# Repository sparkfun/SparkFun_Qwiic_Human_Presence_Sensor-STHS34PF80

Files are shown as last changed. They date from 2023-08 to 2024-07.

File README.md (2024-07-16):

SparkFun Human Presence and Motion Sensor - STHS34PF80
========================================

| [SparkFun Human Presence and Motion Sensor - STHS34PF80 (Qwiic)  *(SEN-22494)*](https://www.sparkfun.com/products/22494) | [SparkFun Qwiic Mini Human Presence and Motion Sensor - STHS34PF80 *(SEN-23253)*](https://www.sparkfun.com/products/23253) |
| --- | --- |
| product in standard 1x1 form factor (https://www.sparkfun.com/products/22494) | product in mini form factor (https://www.sparkfun.com/products/23253) |

The STHS34PF80 sensor, from [ST Microelectronics](https://www.st.com/), is designed to measure the precise [black-body radiation](https://en.wikipedia.org/wiki/Black-body_radiation) *(as described by [Plank's law](https://en.wikipedia.org/wiki/Planck%27s_law))* of an object; as well as monitor ambient temperature conditions within its 80&deg; field of view. The sensor is composed of a matrix of floating vacuum thermal transistors MOS split into two parts, one exposed to IR radiation and the other one shielded. The differential reading between the segments, allows the sensor to remove self-heating effects. The STHS34PF80 also incorporates algorithms to detect and discriminate between stationary and moving objects. These features enable the sensor to work as a human presence and motion sensor in different applications such as alarm systems, anti-intruder systems, smart lighting, and room occupancy.

The sensor can operate in multiple lighting conditions and is unaffected by visible light or other bands thanks to the 5 to 20&micro;m optical band-pass filter. The STHS34PF80 has an output data rates between 0.25 to 30 Hz and an available single-shot, which are accessed through its I²C/SPI interface.

*These products are available in both the standard 1"x1" and mini Qwiic breakout boards. The mini is panel mount compatible for use in enclosures.*

Repository Contents
-------------------

* **[/docs](/docs/)** - Online documentation files
    * [assets](/docs/assets/) - Assets files
        * [board_files](/docs/assets/board_files/) - Files for the product design
            * [Eagle design files](/docs/assets/board_files/eagle_files.zip) (.zip)
            * [Schematic](/docs/assets/board_files/schematic.pdf) (.pdf)
            * [Dimensions](/docs/assets/board_files/dimensions.pdf) (.pdf)
        * [component_documentation](/docs/assets/component_documentation/) - Datasheets for hardware components
        * [img/hookup_guide/](/docs/assets/img/hookup_guide/) - Images for hookup guide documentation
* **[/Hardware](/Hardware/)** - Eagle design files (.brd, .sch)
  * **[/1U](/Hardware/1U/)** - 1"x1" Form Factor
    * **[/Production](/Hardware/1U/Production/)** - Production files
  * **[/Mini](/Hardware/Mini/)** - Mini Form Factor
    * **[/Production](/Hardware/Mini/Production/)** - Production files

Documentation
--------------

* **[Hookup Guide (mkdocs)](http://docs.sparkfun.com/SparkFun_Qwiic_Human_Presence_Sensor-STHS34PF80/)** - Hookup guide for the mosaic-X5 GNSS Breakout hosted by GitHub pages.
  * [Arduino Library](https://github.com/sparkfun/SparkFun_STHS34PF80_Arduino_Library/tree/main)

*Need to download or print our hookup guide?*

* [Print *(Print to PDF)* from Single-Page View](http://docs.sparkfun.com/SparkFun_Qwiic_Human_Presence_Sensor-STHS34PF80/print_view)

Product Variants
----------------

* [SEN-22494](https://www.sparkfun.com/products/22494)- v1.0, Initial Release *(1"x1" Form Factor)*
* [SEN-23253](https://www.sparkfun.com/products/23253)- v1.0, Initial Release *(Mini Form Factor)*

Version History
---------------

* [v10](https://github.com/sparkfun/SparkFun_Qwiic_Human_Presence_Sensor-STHS34PF80/releases/tag/v10) - Initial Release

License Information
-------------------

This product is ***open source***!

Please review the [`LICENSE.md`](./LICENSE.md) file for license information.

If you have any questions or concerns about licensing, please contact technical support on our [SparkFun forums](https://forum.sparkfun.com/viewforum.php?f=152).

Distributed as-is; no warranty is given.

- Your friends at SparkFun.

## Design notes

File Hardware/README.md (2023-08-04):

SparkFun <PRODUCT NAME> Design Files
=====================================

The .sch and .brd files hare are Eagle CAD schematic and PCB design files from SparkFun Electronics.
A freeware version of Autodesk Eagle can be found [here](https://www.autodesk.com/products/eagle/free-download).

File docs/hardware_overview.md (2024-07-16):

---
icon: material/cog
---

## Board Dimensions
The Qwiic Mini Human Presence and Motion Sensor breakout boards are laid out in the standardized 0.5"x 1" (1.77 x 2.54 cm) *mini* form-factor and the normal, 1" x 1" (2.54 x 2.54 cm) Qwiic breakout board. These boards also include standard 0.13" mounting holes, which are compatible with 4-40 screws. The dimensions of these boards are illustrated in the drawings below, where the listed measurements are in inches.

<div class="grid" markdown>

<div markdown>
<figure markdown>
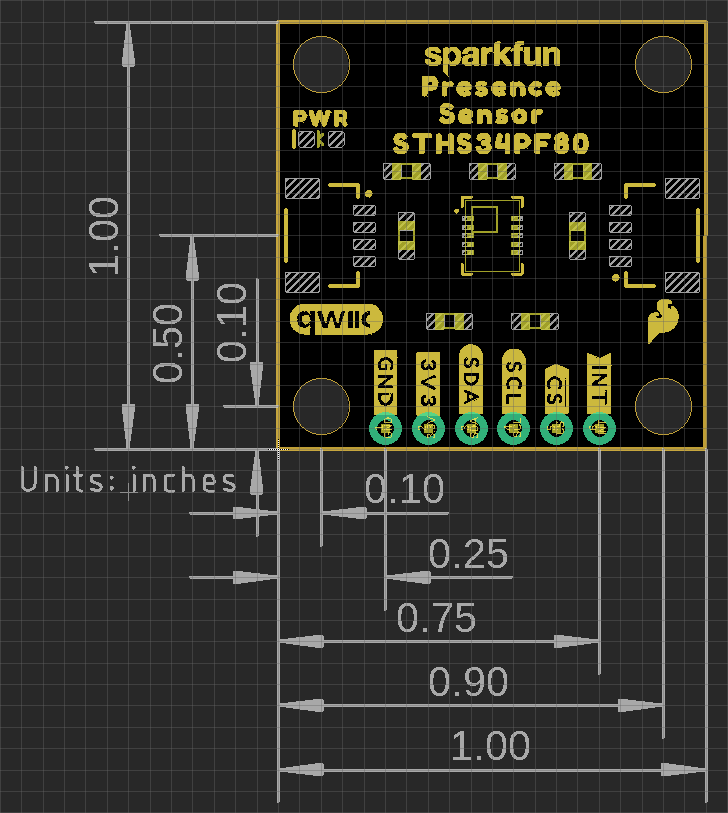
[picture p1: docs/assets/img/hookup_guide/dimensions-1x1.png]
Board Dimensions of the standard board

</figure>
</div>

<div markdown>
<figure markdown>
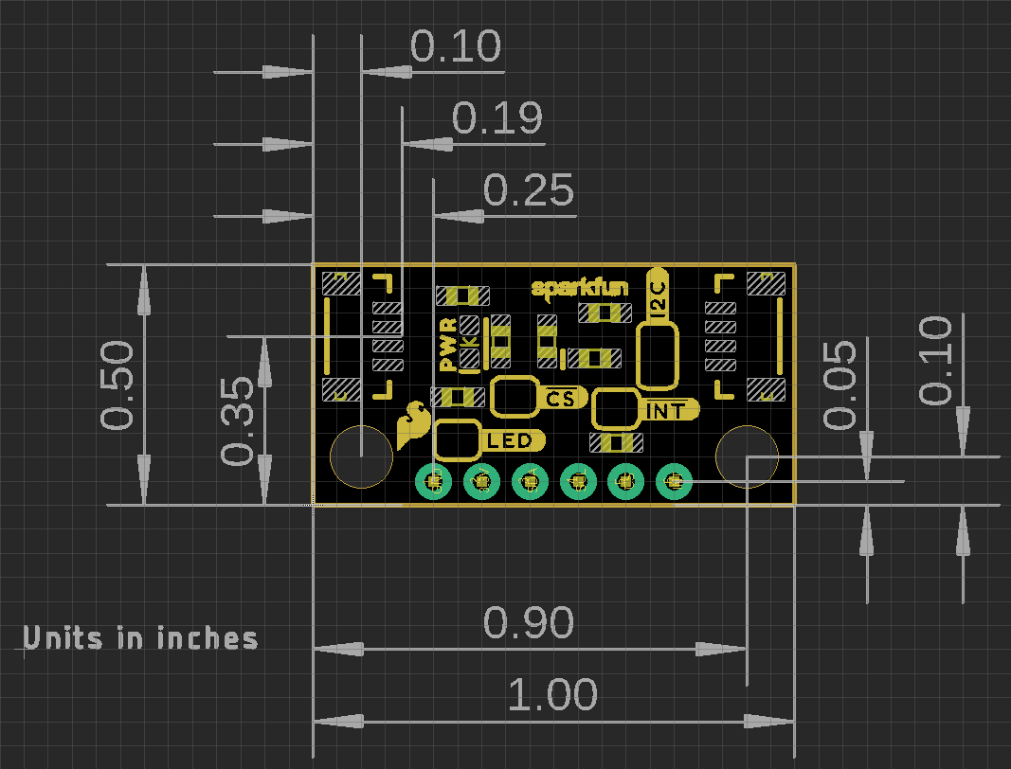
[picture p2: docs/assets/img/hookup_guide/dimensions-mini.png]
Board Dimensions of the mini board

</figure>
</div>

</div>

<center>
*[Dimensions (PDF)](./assets/board_files/dimensions.pdf) for the Qwiic Human Presence/Motion Sensor boards, in inches.*
</center>

??? tip "Need more measurements?"
	For more information about the board's dimensions, users can download the [eagle files](./assets/board_files/eagle_files.zip) for the board. These files can be opened in Eagle and additional measurements can be made with the dimensions tool.

	??? info ":octicons-download-16:{ .heart } Eagle - Free Download!"
		Eagle is a [CAD]("computer-aided design") program for electronics that is free to use for hobbyists and students. However, it does require an account registration to utilize the software.

		<center>
		[Download from<br>:autodesk-primary:{ .autodesk }](https://www.autodesk.com/products/eagle/free-download "Go to downloads page"){ .md-button .md-button--primary width="250px" }
		</center>

	??? info ":straight_ruler: Dimensions Tool"
		This video from Autodesk demonstrates how to utilize the dimensions tool in Eagle, to include additional measurements:

		<center>
		<div class="video-500px">
		<iframe src="https://www.youtube.com/embed/dZLNd1FtNB8" title="EAGLE Dimension Tool" frameborder="0" allow="accelerometer; autoplay; clipboard-write; encrypted-media; gyroscope; picture-in-picture" allowfullscreen></iframe>
		</div>
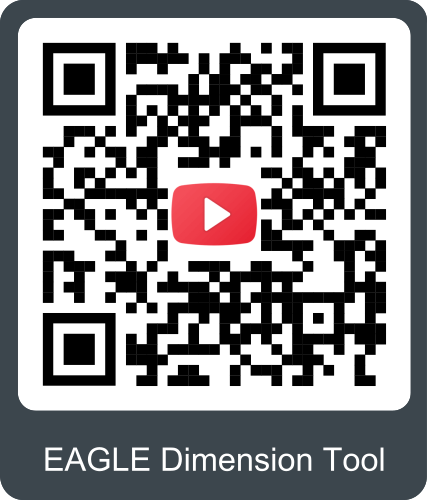
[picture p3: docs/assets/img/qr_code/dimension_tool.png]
QR code to play video
		
		</center>

## Power
The STHS34PF80 requires a supply voltage between **1.7V** to **3.6V**. This power can be provided to the board, either, through one of the *polarized* Qwiic connectors or the dedicated 3.3V and GND [PTH](https://en.wikipedia.org/wiki/Through-hole_technology "Plated Through Holes") pins broken out on the board.

<div class="grid" markdown>

<div markdown>
<figure markdown>
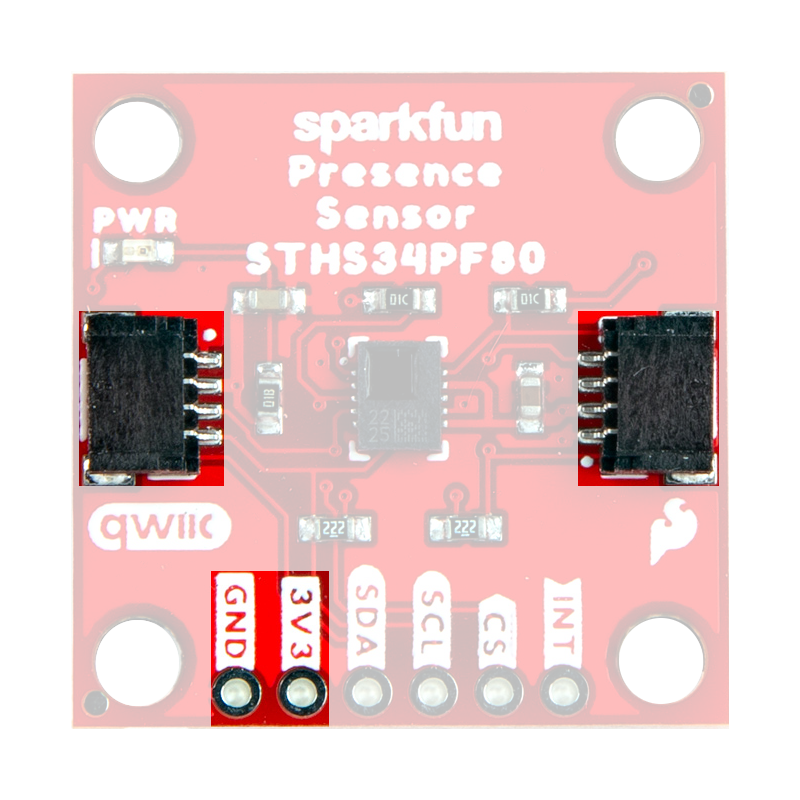
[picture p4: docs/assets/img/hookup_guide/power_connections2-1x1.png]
Power connections on the standard board

</figure>
</div>

<div markdown>
<figure markdown>
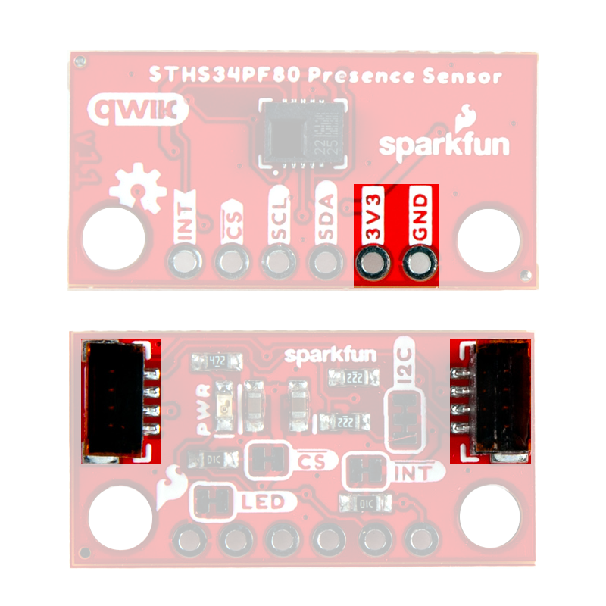
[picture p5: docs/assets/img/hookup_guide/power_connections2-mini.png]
Power connections on the mini board

</figure>
</div>

</div>

<center>
*Qwiic Human Presence/Motion Sensor boards' power connections.*
</center>

!!! warning "Info"
	The Qwiic connect system is meant to run on **3.3V**. Ensure that another voltage is not being supplied, when utilized in conjunction with this system.

!!! info
	For more details, users can reference the [schematic](./assets/board_files/schematic.pdf) and the [STHS34PF80 datasheet](./assets/component_documentation/sths34pf80.pdf).

### Power Status LED
The red, `PWR` LED will light up once **1.4V** is supplied to the board; however, for most users, it will light up when **3.3V** is supplied through the Qwiic connector. A jumper is available to disconnect the power from the LED, for low-power applications (see Jumpers section below).

<div class="grid" markdown>

<div markdown>
<figure markdown>
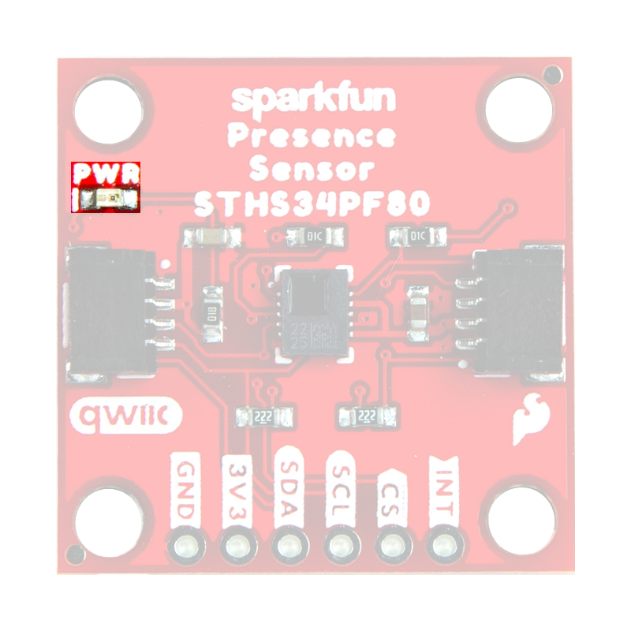
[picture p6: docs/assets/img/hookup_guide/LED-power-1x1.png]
Power LED on the standard board

</figure>
</div>

<div markdown>
<figure markdown>
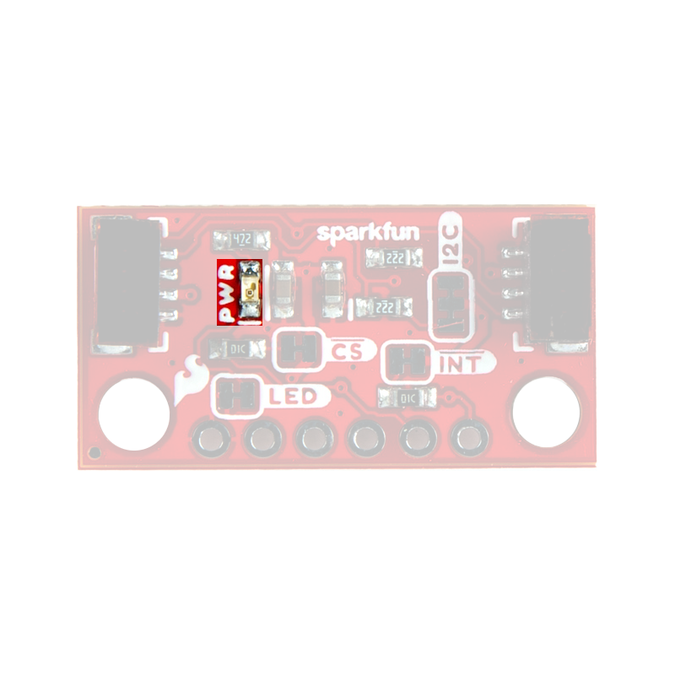
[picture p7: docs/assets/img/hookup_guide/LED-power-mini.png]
Power LED on the mini board

</figure>
</div>

</div>

<center>
*The `PWR` status LED on the Qwiic Human Presence/Motion Sensor boards.*
</center>

!!! tip "Minimum Voltage"
	Users should keep in mind that the forward voltage of the red LED is lower than the minimum voltage required to power the STHS34PF80 sensor. Therefore, the LED could potentially be lit, when there isn't enough voltage to power the sensor.

## :fontawesome-solid-microchip:&nbsp; STHS34PF80
The Qwiic Human Presence/Motion Sensor board features the [STHS34PF80 sensor](./assets/component_documentation/sths34pf80.pdf) from [ST Microelectronics](https://www.st.com). Composed of a matrix of floating vacuum thermal transistors MOS, the sensor measures the ambient temperature and detects the [black-body radiation](https://en.wikipedia.org/wiki/Black-body_radiation) of objects within its 80&deg field of view. The sensor's transistor array is split into two parts, one exposed to IR radiation and the other one shielded. The differential reading between the segments, allows the sensor to remove self-heating effects.

The sensor can operate in multiple lighting conditions and is unaffected by visible light or other bands thanks to the 5 to 20&micro;m optical band-pass filter. The STHS34PF80 also incorporates algorithms to detect and discriminate between stationary and moving objects. These features enable the sensor to work as a human presence and motion sensor in different applications such as alarm systems, anti-intruder systems, smart lighting, and room occupancy. With an output data rates between 0.25 to 30 Hz and an available single-shot measurement from the STHS34PF80, all of which can be accessed through its I<sup>2</sup>C/SPI interface.

<div class="grid" markdown>

<div markdown>

**Features:**

<div class="annotate" markdown>

* I<sup>2</sup>C Address *(7-bit)*: **0x5A** *(**`1011010`**)*
* Operating Voltage: **1.7 to 3.6V**
	* Current Draw: 10&micro;A
* Range: 4m *(objects 70 x 25 cm² in size)*
	* Field of View: 80°
* Optical wavelength: 5 to 20&micro;m
* Built-in Detection Algorithms:
	* Identify stationary objects
	* Distinguish between stationary and moving objects
* Output Data Rate: 0.25 to 30Hz
* IR sensitivity: 2000 LSB/&deg;C
* RMS noise: 25 LSB<sub>rms</sub>
* Operating Temperature: -40 to 85&deg;C (1)
* Sensor accuracy: ±0.6&deg;C *(local)* (2)
* Factory calibrated

</div>

1. The operational temperature range of the sensor is 
2. The accuracy specifications only apply under settled isothermal conditions.

!!! info "Current Consumption"
	The average current consumption by the STHS34PF80 is 10&micro;A with 1.5&micro;A in power-down mode.

</div>

<div markdown>

<!-- <figure markdown>
[![STHS34PF80 sensor on the standard board](./assets/img/hookup_guide/STHS34PF80-1x1.png){ width="400" }](./assets/img/hookup_guide/STHS34PF80-1x1.png "Click to enlarge")
<br>
<figure markdown>
[![STHS34PF80 sensor on the mini board](./assets/img/hookup_guide/STHS34PF80-mini.png){ width="400" }](./assets/img/hookup_guide/STHS34PF80-mini.png "Click to enlarge")
<figcaption markdown>The STHS34PF80 sensor on the Qwiic Human Presence/Motion Sensor boards.</figcaption>
</figure> -->

<figure markdown>
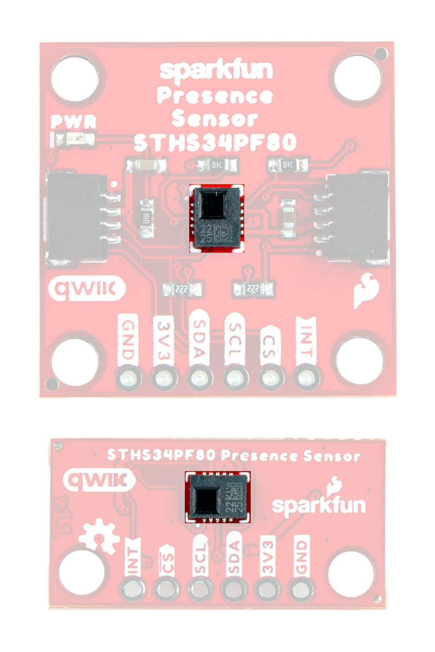
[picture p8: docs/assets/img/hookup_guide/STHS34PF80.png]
STHS34PF80 sensor on the mini board

<figcaption markdown>The STHS34PF80 sensor on the Qwiic Human Presence/Motion Sensor boards.</figcaption>
</figure>

</div>

</div>

??? note "Operation Modes"
	The STHS34PF80 has three operation modes:

	* **Power-down:** After the boot is completed, the device is automatically configured in power-down mode.
	* **One-shot:**	When configured in one-shot mode, the device can read environmental data at the very moment the controlling MCU requires it.
	* **Continuous:**	When configured in continuous mode, the device keeps reading data at predefined frequencies (fixed output data rates, ODRs).
	
	In both one-shot mode and continuous mode, the STHS34PF80 allows performing prior averaging (filtering) of the values of ambient temperature and object temperature to obtain smoother outputs.

	!!! info
		For more details, users can refer to [Section 3 of the AN5867 - Operation Manual](./assets/component_documentation/an5867-operation-manual.pdf).

??? note "Smart Detection Algorithms"
	The STHS34PF80 has three detection modes that are provided by the built-in smart algorithms:

	* Presence detection
	* Motion detection
	* Ambient temperature shock detection

	*\*These are not available when wide mode is configured.*

	!!! info
		For more details, users can refer to [Section 7 of the AN5867 - Operation Manual](./assets/component_documentation/an5867-operation-manual.pdf).

## Breakout Pins
There are six [PTH](https://en.wikipedia.org/wiki/Through-hole_technology "Plated Through Holes") pins broken out on the Qwiic Human Presence/Motion Sensor boards. The pins are evenly spaced at 0.1" on the outer edge of the board; perfect for attaching [headers](https://www.sparkfun.com/categories/381). These pins provide access to the I<sup>2</sup>C and SPI interfaces of the STHS34PF80 sensor, including the interrupt pin.

!!! note
	The I<sup>2</sup>C interface can also be accessed through the Qwiic connectors on the board.

### I<sup>2</sup>C Pins
The I<sup>2</sup>C interface can also be accessed either through the breakout pins or the Qwiic connectors on the board. In most cases, the Qwiic connector will be the simplest method to connect the Qwiic Human Presence/Motion Sensor boards to a microcontroller. The I<sup>2</sup>C interface is **enabled by default** on the Qwiic Human Presence/Motion Sensor boards.

<div class="grid" markdown>

<div markdown>
<figure markdown>
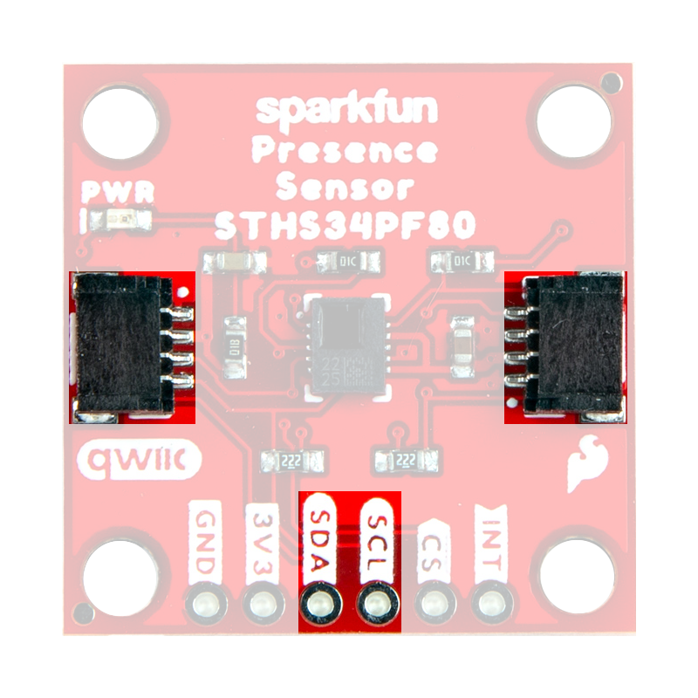
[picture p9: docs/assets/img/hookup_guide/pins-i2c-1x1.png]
I2C pins on the standard board

</figure>
</div>

<div markdown>
<figure markdown>
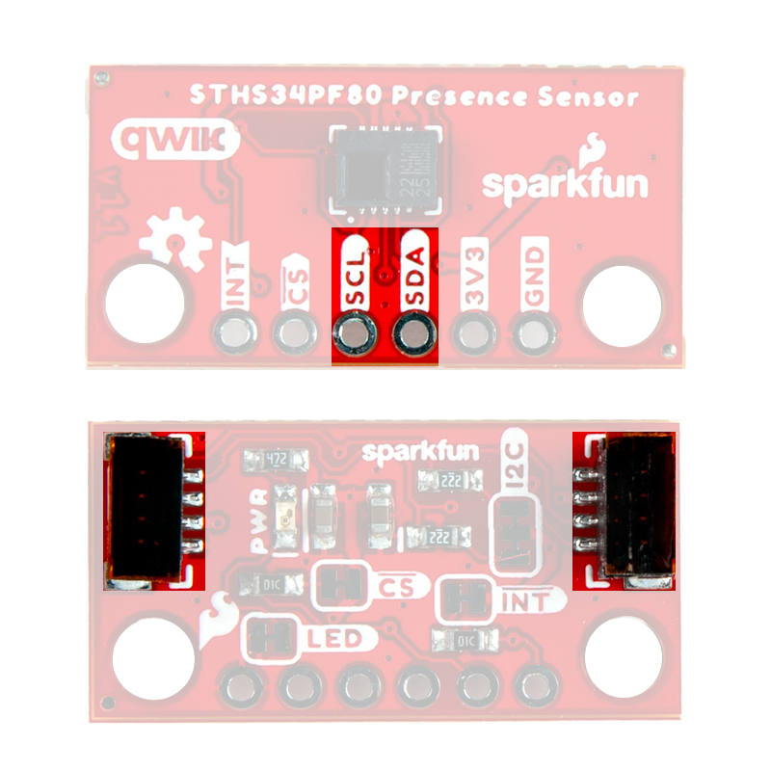
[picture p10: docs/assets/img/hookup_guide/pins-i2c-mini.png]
I2C pins on the mini board

</figure>
</div>

</div>

<center>
*I<sup>2</sup>C pins on the Qwiic Human Presence/Motion Sensor boards.*
</center>

!!! info "Enabling the I<sup>2</sup>C Interface"
	The I<sup>2</sup>C interface is enabled by default on the Qwiic Human Presence/Motion Sensor boards. To disable the I<sup>2</sup>C interface and enable the SPI interface, users must ensure that the `CS` pin is initially pulled down (`0`).

??? tip " Qwiic Connector"
	Qwiic connectors are provided for users to seamlessly integrate I<sup>2</sup>C devices with [SparkFun's Qwiic Ecosystem](https://www.sparkfun.com/qwiic).

	<div class="grid" markdown>

	<div markdown>
	<figure markdown>
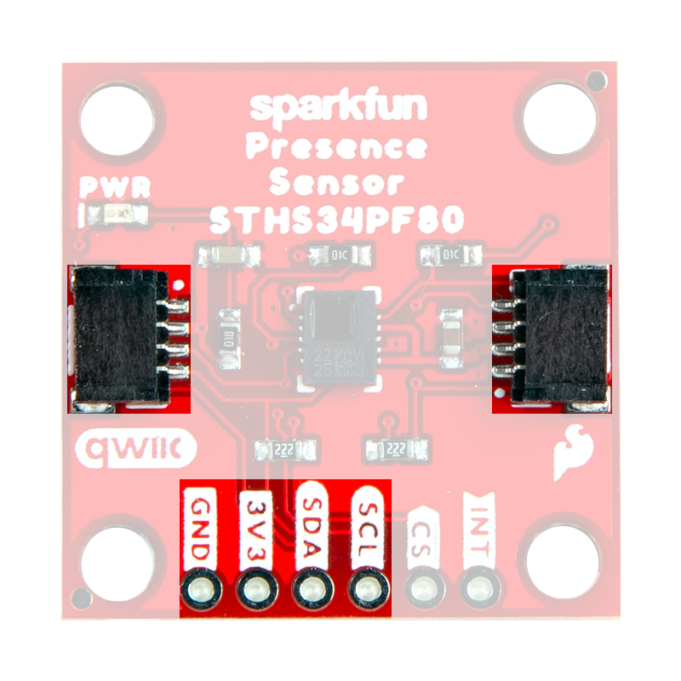
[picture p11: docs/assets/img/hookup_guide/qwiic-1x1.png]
Qwiic connector and I2C pins on the standard board
	
	</figure>
	</div>

	<div markdown>
	<figure markdown>
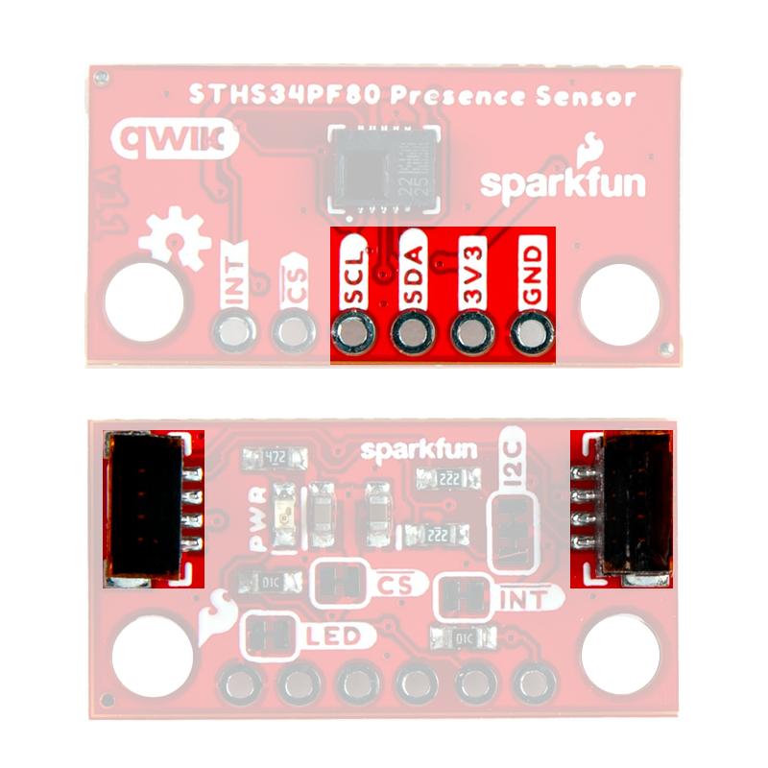
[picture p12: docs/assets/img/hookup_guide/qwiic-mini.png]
Qwiic connector and I2C pins on the mini board
	
	</figure>
	</div>

	</div>

	<center>
	*Qwiic connector and I<sup>2</sup>C pins on the Qwiic Human Presence/Motion Sensor boards.*
	</center>

### SPI Pins
The STHS34PF80 sensor operates in a 3-wire SPI configuration. In a 3-wire mode, the data signal lines are combined into a single bidirectional data line. The data transactions are half-duplex to allow for bidirectional communication.

<div align="center" markdown>

<table markdown>
<tr>
<th align="center">Label</th>
<th align="center">Pin</th>
<th>Function</th>
</tr>
<tr markdown>
<td align="center" markdown>`SCL`</td>
<td align="center" markdown>`SPC`</td>
<td>Clock signal</td>
</tr>
<tr markdown>
<td align="center" markdown>`SDA`</td>
<td align="center" markdown>`SDIO`</td>
<td>Serial data (In/Out)</td>
</tr>
<tr markdown>
<td align="center" style="vertical-align:middle" markdown>`CS`</td>
<td align="center" style="vertical-align:middle" markdown>`CS`</td>
<td markdown>
Chip select:<br>
`1`: I²C enabled<br>
`0`: SPI enabled
</td>
</tr>
</table>

</div>

<div class="grid" markdown>

<div markdown>
<figure markdown>
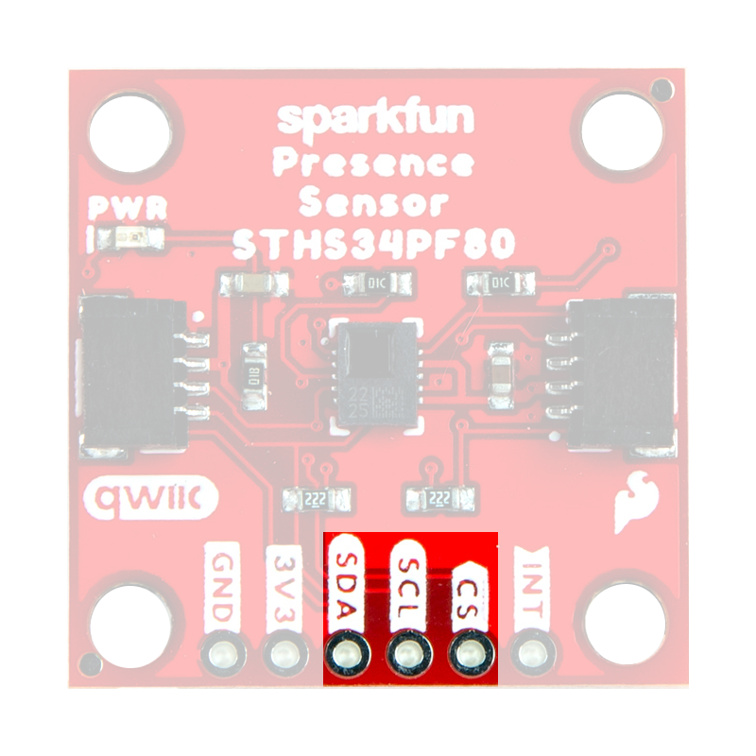
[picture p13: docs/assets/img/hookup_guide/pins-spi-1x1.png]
SPI pins on the standard board

</figure>
</div>

<div markdown>
<figure markdown>
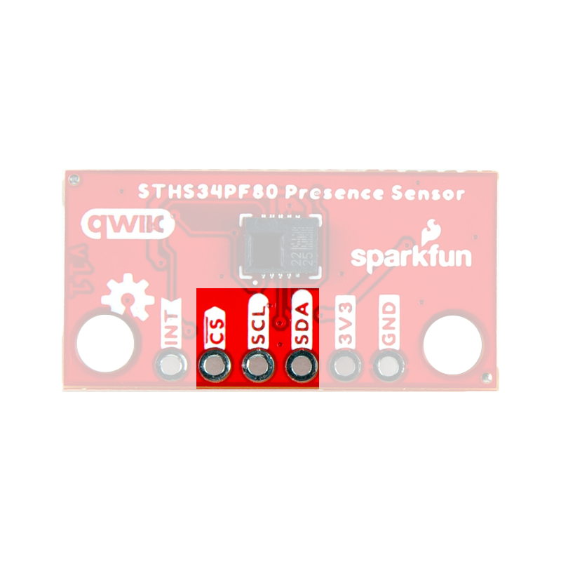
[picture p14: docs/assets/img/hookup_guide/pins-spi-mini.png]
SPI pins on the mini board

</figure>
</div>

</div>

<center>
*SPI pins on the Qwiic Human Presence/Motion Sensor boards. Please refer to the table above for the associated pin connections, based on the boards' labels.*
</center>

!!! info "Enabling the SPI Interface"
	The I<sup>2</sup>C interface is enabled by default on the Qwiic Human Presence/Motion Sensor boards. To disable the I<sup>2</sup>C interface and enable the SPI interface, users must ensure that the `CS` pin is initially pulled down. *(On boot-up, the `CS` must be in a `LOW` state to enable the SPI interface.)*

### Interrupt Pin
By default, the interrupt pin signals when data is available. However, the detection mode employed by the sensor can also trigger an interrupt.

<div class="grid" markdown>

<div markdown>
<figure markdown>
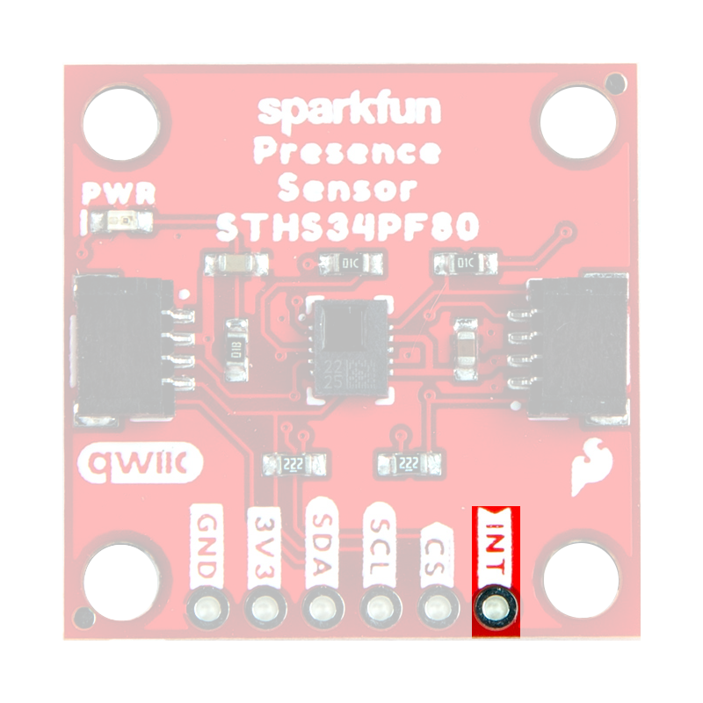
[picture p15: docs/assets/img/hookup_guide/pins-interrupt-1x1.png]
Interrupt pin on the standard board

</figure>
</div>

<div markdown>
<figure markdown>
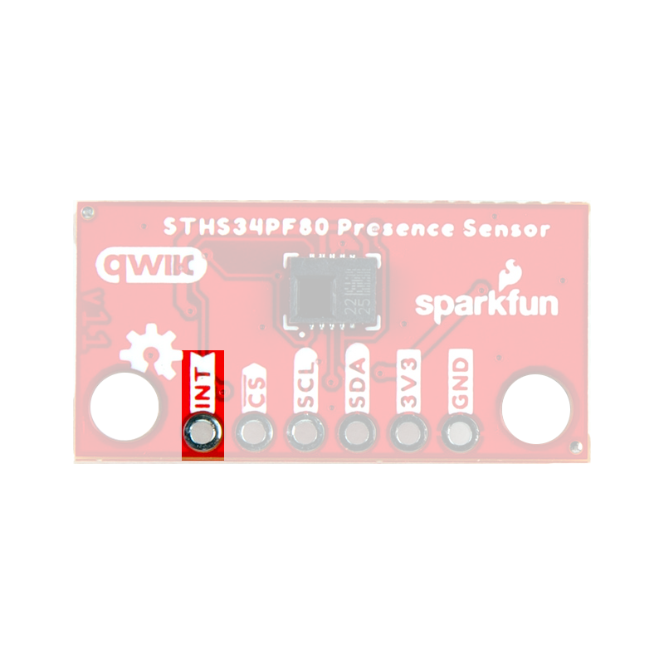
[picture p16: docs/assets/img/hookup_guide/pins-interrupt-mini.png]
Interrupt pin on the mini board

</figure>
</div>

</div>

<center>
*Interrupt pin on the Qwiic Human Presence/Motion Sensor boards.*
</center>

## Qwiic Connectors
Qwiic connectors are provided for users to seamlessly integrate with [SparkFun's Qwiic Ecosystem](https://www.sparkfun.com/qwiic). Otherwise, users can access the I<sup>2</sup>C interface through the [PTH pins broken out on the board](#i2c-pins).

<div class="grid" markdown>

<div markdown>
<figure markdown>
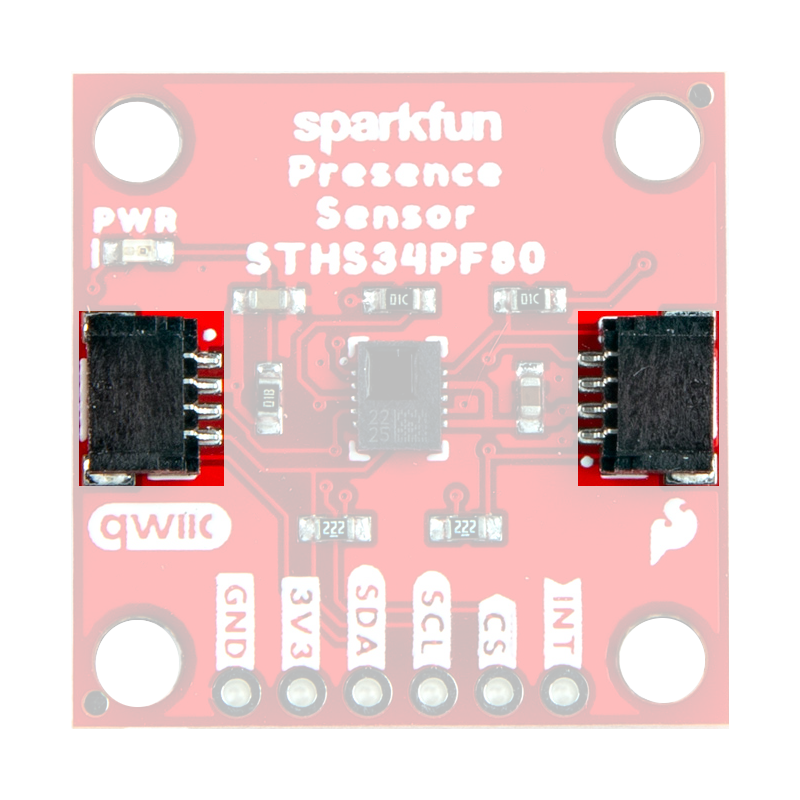
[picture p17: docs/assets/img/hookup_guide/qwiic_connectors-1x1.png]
Qwiic connector on the standard board

</figure>
</div>

<div markdown>
<figure markdown>
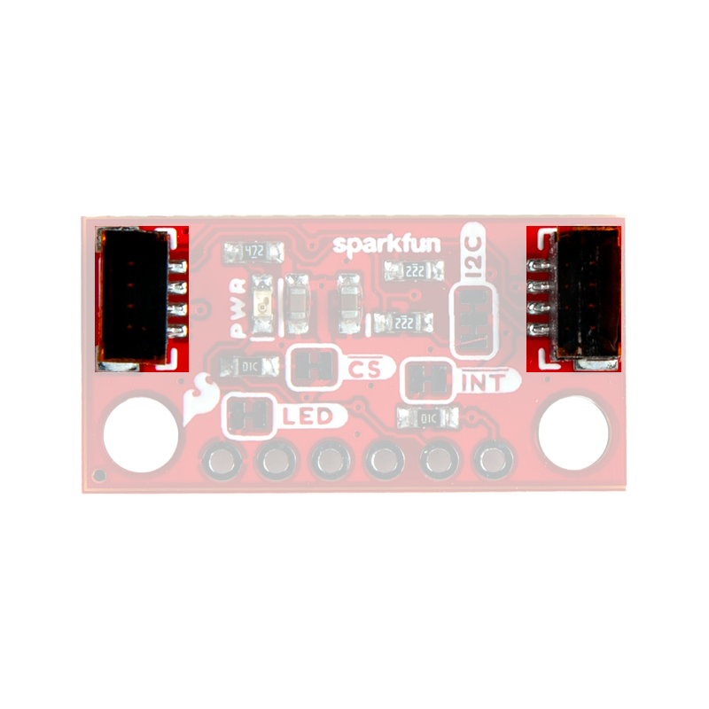
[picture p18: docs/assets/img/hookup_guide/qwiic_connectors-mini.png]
Qwiic connector on the mini board

</figure>
</div>

</div>

<center>
*Qwiic connectors on the Qwiic Human Presence/Motion Sensor boards.*
</center>

??? tip "What is Qwiic?"

	<div class="grid" markdown>

	<div markdown>

	<!-- Qwiic Banner -->
	<center>
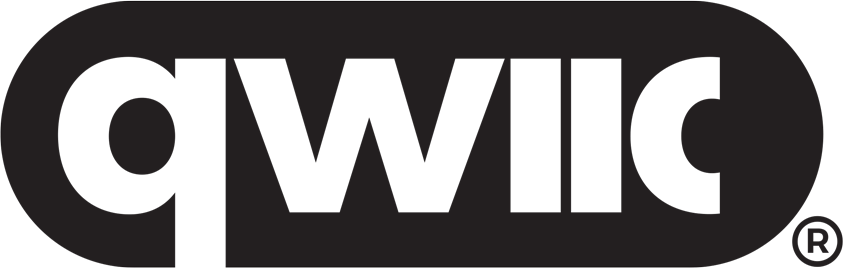
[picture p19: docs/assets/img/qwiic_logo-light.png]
Qwiic Logo - light theme (https://www.sparkfun.com/qwiic)
	
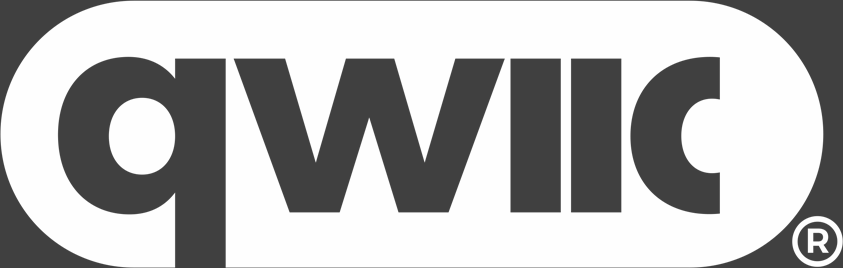
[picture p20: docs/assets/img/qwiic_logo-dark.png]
Qwiic Logo - dark theme (https://www.sparkfun.com/qwiic)
	
	</center>

	---

	The [Qwiic connect system](https://www.sparkfun.com/qwiic) is a solderless, polarized connection system that allows users to seamlessly daisy chain I^2^C boards together. Play the video, to learn more about the Qwiic connect system or click on the banner above to learn more about [Qwiic products](https://www.sparkfun.com/qwiic).

	</div>

	<div style="max-height=400px;" markdown>

	<center>
	<div class="video-container">
	<iframe src="https://www.youtube.com/embed/x0RDEHqFIF8" title="SparkFun's Qwiic Connect System" frameborder="0" allow="accelerometer; encrypted-media; gyroscope; picture-in-picture" allowfullscreen></iframe>

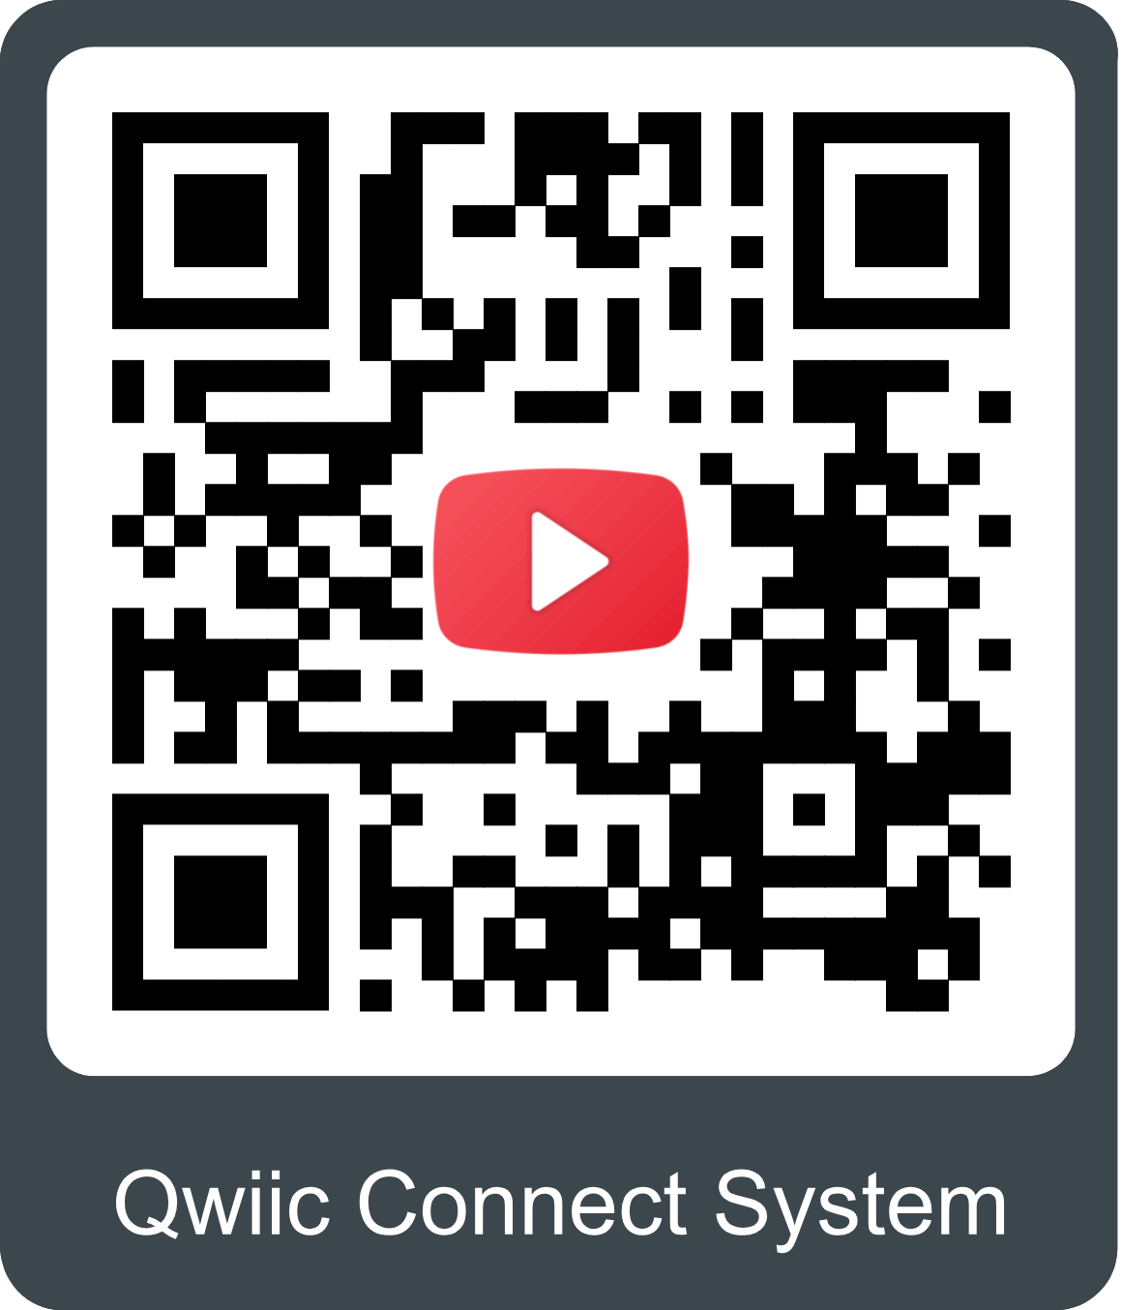
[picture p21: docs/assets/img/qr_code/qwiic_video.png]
QR code to instructional video
	
	</div>
	</center>

	</div>

	</div>

	!!! info "Features of the Qwiic System"

		=== "No Soldering"

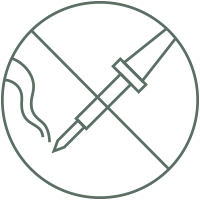
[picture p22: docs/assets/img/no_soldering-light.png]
no soldering - light theme
			
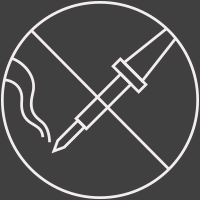
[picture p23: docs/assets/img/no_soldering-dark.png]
no soldering - dark theme
			

			Qwiic cables (4-pin JST) plug easily from development boards to sensors, shields, accessory boards and more, making easy work of setting up a new prototype.

		=== "Polarized Connector"

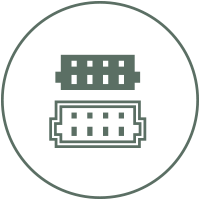
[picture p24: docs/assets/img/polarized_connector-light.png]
polarized connector - light theme
			
			polarized connector - dark theme

			There's no need to worry about accidentally swapping the `SDA` and `SCL` wires on your breadboard. The Qwiic connector is polarized so you know you’ll have it wired correctly every time.

			The part numbers for the PCB connector is `SM04B-SRSS` ([Datasheet](https://cdn.sparkfun.com/assets/parts/1/2/2/8/9/Qwiic_Connector_Datasheet.pdf)) and the mating connector on the cables is `SHR04V-S-B`; or an equivalent *1mm pitch, 4-pin JST connection*.

		=== "Daisy Chain-able"

			daisy chainable - light theme
			daisy chainable - dark theme

			It’s time to leverage the power of the I^2^C bus! Most Qwiic boards will have two or more connectors on them, allowing multiple devices to be connected.

## Jumpers

??? note "Never modified a jumper before?"
	Check out our <a href="https://learn.sparkfun.com/tutorials/664">Jumper Pads and PCB Traces tutorial</a> for a quick introduction!

	<div class="grid cards col-4" markdown align="center">

	-   <a href="https://learn.sparkfun.com/tutorials/664">
		<figure markdown>
		Tutorial thumbnail
		</figure>

		---

		**How to Work with Jumper Pads and PCB Traces**</a>

	</div>

There are four jumpers on the back of the board that can be used to easily modify the hardware connections of the board.

<div class="annotate" markdown>

* **LED** - This jumper can be used to disconnect power from the red, power LED for low-power applications.
* **I2C** - This jumper can be used to remove the pull-up resistors on the I<sup>2</sup>C bus.
* **INT** - This jumper can be used to remove the pull-up resistor from the `INT` pin.
* **CS** - This jumper can be used to remove the pull-up resistor from the `CS` pin.
	* The state of the `CS` pin on boot-up, controls whether the I<sup>2</sup>C or SPI interface is enabled. (1)

</div>

1. !!! info
	* `1`: I²C enabled
	* `0`: SPI enabled

<div class="grid" markdown>

<div markdown>
<figure markdown>
Jumpers on the standard board
<figcaption markdown>Jumpers on the back of the Qwiic Human Presence/Motion Sensor board.</figcaption>
</figure>
</div>

<div markdown>
<figure markdown>
Jumpers on the mini board
<figcaption markdown>Jumpers on the Qwiic Mini Human Presence/Motion Sensor board.</figcaption>
</figure>
</div>

</div>

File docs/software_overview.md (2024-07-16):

---
icon: simple/arduino
---

## Arduino IDE
!!! tip
	For first-time users, who have never programmed before and are looking to use the Arduino IDE, we recommend beginning with the <a href="https://www.sparkfun.com/products/15631">SparkFun Inventor's Kit (SIK)</a>, which is designed to help users get started programming with the Arduino IDE.

Most users may already be familiar with the Arduino IDE and its use. However, for those of you who have never heard the name *Arduino* before, feel free to check out the [Arduino website](https://www.arduino.cc/en/Guide/HomePage). To get started with using the Arduino IDE, check out our tutorials below:

<div class="grid cards" markdown align="center">

-   <a href="https://learn.sparkfun.com/tutorials/50"><figure markdown>
	What is an Arduino?
	</figure>

	---

	**What is an Arduino?**</a>

-   <a href="https://learn.sparkfun.com/tutorials/61"><figure markdown>
	Installing the Arduino IDE
	</figure>

	---
	
	**Installing the Arduino IDE**</a>

-   <a href="https://learn.sparkfun.com/tutorials/15"><figure markdown>
	Installing an Arduino Library
	</figure>

	---
	
	**Installing an Arduino Library**</a>

-   <a href="https://learn.sparkfun.com/tutorials/1265"><figure markdown>
	Installing Board Definitions in the Arduino IDE
	</figure>

	---
	
	**Installing Board Definitions in the Arduino IDE**</a>
</div>

??? tip "Need help setting up the RedBoard Plus?"
	### RedBoard Plus
	The following instructions should help users get started with the RedBoard Plus. For more information about the board, please check out our hookup guide below:

	<figure markdown>
	RedBoard Plus Hookup Guide (https://learn.sparkfun.com/tutorials/1758)
	<figcaption markdown>[**RedBoard Plus Hookup Guide**](https://learn.sparkfun.com/tutorials/1758)</figcaption>
	</figure>

	#### CH340 Driver
	Users will need to install the appropriate driver for their computer to recognize the serial-to-UART chip on their board/adapter. Most of the latest operating systems will recognize the CH340C chip on the board and automatically install the required driver.

	*To manually install the CH340 driver on their computer, users can download it from the [WCH website](http://www.wch-ic.com/products/CH340.html?). For more information, check out our [How to Install CH340 Drivers Tutorial](https://www.sparkfun.com/ch340).*

	<figure markdown>
	How to Install CH340 Drivers (https://learn.sparkfun.com/tutorials/908)
	<figcaption markdown>[**How to Install CH340 Drivers**](https://learn.sparkfun.com/tutorials/908)</figcaption>
	</figure>

	#### Selecting a Board
	When selecting a board to program in the Arduino IDE, users should select the **Arduino Uno** from the **Tools** drop-down menu _(_i.e. **Tools** > **Board** > **Arduino AVR Boards** > **Arduino Uno**)_.

	<figure markdown>
	Click to enlarge
	<figcaption markdown>Select the **Arduino Uno** from the Tools drop-down menu in the Arduino IDE.</figcaption>
	</figure>

	??? info "Arduino IDE 2.x.x - *Alternative Method*"
		In the newest version of the Arduino IDE 2.`x`.`x`, users can also select their board (*green*) and port (*blue*) from the `Select Board & Port` dropdown menu (*yellow*).

		<figure markdown>
		Click to enlarge
		<figcaption markdown>Selecting the **Arduino Uno** and **COM5** port from the **Select Board & Port** drop-down menu in the Arduino IDE (v2.0.3).</figcaption>
	</figure>

## SparkFun STHS34PF80 Arduino Library
The [SparkFun STHS34PF80 Arduino library](https://github.com/sparkfun/SparkFun_STHS34PF80_Arduino_Library) can be installed from the library manager in the Arduino IDE by searching for:

	SparkFun STHS34PF80 Arduino library

<figure markdown>
Click to enlarge
<figcaption markdown>SparkFun STHS34PF80 Arduino library in the library manager of the Arduino IDE.</figcaption>
</figure>

??? tip "Manually Downloading the Arduino Library"
	For users who would like to manually download and install the library, the `*.zip` file can be accessed from the [GitHub repository](https://github.com/sparkfun/SparkFun_STHS34PF80_Arduino_Library) or downloaded by clicking the button below.

	<center>
	[:octicons-download-16:{ .heart } Download the Arduino Library](https://github.com/sparkfun/SparkFun_STHS34PF80_Arduino_Library/archive/refs/heads/main.zip){ .md-button .md-button--primary }
	</center>

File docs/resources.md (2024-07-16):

## Product Resources

<section class="grid cards" markdown>

- **Composite (Both Boards)**

	---

	* :material-folder-cog: Design Files:
		* :fontawesome-solid-file-pdf: [Board Dimensions](./assets/board_files/dimensions.pdf)
		* :fontawesome-solid-file-pdf: [Schematic](./assets/board_files/schematic.pdf)
		* :material-folder-zip: [Eagle Files](./assets/board_files/eagle_files.zip)
	* :simple-arduino: [Arduino Library](https://github.com/sparkfun/SparkFun_STHS34PF80_Arduino_Library/tree/main)
	* Component Documentation
		* :fontawesome-solid-file-pdf: [STHS34PF805 Datasheet](./assets/component_documentation/sths34pf80.pdf)
		* :fontawesome-solid-file-pdf: [AN5983 - Hardware Guidelines](./assets/component_documentation/an5983-hardware-implementation-guidelines.pdf)
		* :fontawesome-solid-file-pdf: [AN5867 - Operation Manual](./assets/component_documentation/an5867-operation-manual.pdf)
	* :material-github: [Hardware Repo](https://github.com/sparkfun/SparkFun_Qwiic_Human_Presence_Sensor-STHS34PF80)

- **Human Presence and Motion Sensor - STHS34PF80 (Qwiic)**

	---

	* :sfe-logo: [Product Page](https://www.sparkfun.com/products/22494)
	* :material-folder-cog: Design Files:
		* :fontawesome-solid-file-pdf: [Board Dimensions](./assets/board_files/dimensions-1x1.pdf)
		* :fontawesome-solid-file-pdf: [Schematic](./assets/board_files/schematic-1x1.pdf)
		* :material-folder-zip: [Eagle Files](./assets/board_files/eagle_files-1x1.zip)

- **Qwiic Mini Human Presence and Motion Sensor - STHS34PF80**

	---

	* :sfe-logo: [Product Page](https://www.sparkfun.com/products/23253)
	* :material-folder-cog: Design Files:
		* :fontawesome-solid-file-pdf: [Board Dimensions](./assets/board_files/dimensions-mini.pdf)
		* :fontawesome-solid-file-pdf: [Schematic](./assets/board_files/schematic-mini.pdf)
		* :material-folder-zip: [Eagle Files](./assets/board_files/eagle_files-mini.zip)

</section>

### Additional Resources

* :material-account-supervisor: [SparkFun Technical Assistance](https://www.sparkfun.com/technical_assistance)

## 🏭&nbsp;Manufacturer's Resources
ST Microelectronics also provides additional resources for the STHS34PF805:

* [STHS34PF805 Product Page](https://www.st.com/en/mems-and-sensors/sths34pf80.html)

<center>
QR code to the hookup guide
</center>

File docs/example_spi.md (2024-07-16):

!!! bug
	This example doesn't currently operate properly; we are actively looking into the issue. To track our progress, please refer to this [GitHub issue](https://github.com/sparkfun/SparkFun_STHS34PF80_Arduino_Library/issues/7).

## Description
The [`Example4_SPIFunctionality.ino`](https://github.com/sparkfun/SparkFun_STHS34PF80_Arduino_Library/blob/main/examples/Example4_SPIFunctionality) example file can be accessed from the **File** > **Examples** > **SparkFun STHS34PF80 Arduino Library** > **Example4_SPIFunctionality** drop-down menu. This example operates similarly to the code in [`Example1_BasicReadings.ino`](https://github.com/sparkfun/SparkFun_STHS34PF80_Arduino_Library/blob/main/examples/Example1_BasicReadings). Instead of retrieving data through the I<sup>2</sup>C interface, the serial peripheral interface (SPI) is used to access the human presence detection values from the STHS34PF80 sensor.

??? code "`Example4_SPIFunctionality.ino`"
	??? info "Code Verification"
		This code was last verified to be functional under the following parameters:

			--8<-- "https://raw.githubusercontent.com/sparkfun/SparkFun_STHS34PF80_Arduino_Library/main/examples/Example4_SPIFunctionality/Example4_SPIFunctionality.ino:16:19"

	```  c++ linenums="1"
	--8<-- "https://raw.githubusercontent.com/sparkfun/SparkFun_STHS34PF80_Arduino_Library/main/examples/Example4_SPIFunctionality/Example4_SPIFunctionality.ino"
	```

## Hardware Connections
For this example, users will need to modify the `CS` jumper to enable the [SPI](https://en.wikipedia.org/wiki/Serial_Peripheral_Interface "Serial Peripheral Interface") communication. In the setups illustrated below, [right-angle headers](https://www.sparkfun.com/products/553) were soldered to the boards and connected with [M/F jumper wires](https://www.sparkfun.com/products/9140) to the microcontroller. However, users should select a connection method that suits their needs.

<div class="grid" markdown>

<div markdown>
<figure markdown>
The sensor connected to a RedBoard Plus
</figure>
</div>

<div markdown>
<figure markdown>
The sensor connected to a RedBoard Plus
</figure>
</div>

</div>

<center>
*The Qwiic Human Presence/Motion Sensor boards with [headers](https://www.sparkfun.com/products/553) soldered to them and connected to a RedBoard Plus with [jumper wires](https://www.sparkfun.com/products/9140).*
</center>

### Pin Connections
Below are the pin connections for SPI communication with the sensor. Users should be aware of the logic-levels of their microcontroller; with the [RedBoard Plus](https://www.sparkfun.com/products/18158), users only need to flip a switch to configure all the board's pins to **3.3V-logic**.

<div class="grid" markdown>

<div align="center" markdown>

| Sensor Pin | Microcontroller Pin | RedBoard Plus |
| :---: | :--- | :---: |
| `CS`  | SPI - Chip Select Pin | `10` |
| `SCL` | SPI - Serial Peripheral Clock | `13` |
| `SDA` | SPI - Serial Data In/Out | `12` |
| `3V3` | Power: **1.7 to 3.6V** | `3.3V`  |
| `GND` | Ground | `GND` |

</div>

<div markdown>
<figure markdown>
Switch on the RedBoard Plus (https://cdn.sparkfun.com/assets/learn_tutorials/1/7/5/8/18158-SparkFun_RedBoard_Plus_IO_Logic_Switch.jpg "Click to enlarge")
<figcaption markdown>
The logic-level switch on the RedBoard Plus.
</figcaption>
</figure>
</div>

</div>

!!! note
	Users will need to initially pull the `CS` pin low, to enable the [SPI](https://en.wikipedia.org/wiki/Serial_Peripheral_Interface "Serial Peripheral Interface") communication on the Qwiic Human Presence/Motion Sensor boards.

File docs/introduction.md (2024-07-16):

---
icon: material/book-open-page-variant
---

# Introduction

The STHS34PF80 sensor, from [ST Microelectronics](https://www.st.com/), is designed to measure the precise [black-body radiation](https://en.wikipedia.org/wiki/Black-body_radiation) *(as described by [Plank's law](https://en.wikipedia.org/wiki/Planck%27s_law))* of an object; as well as monitor ambient temperature conditions within its 80&deg; field of view. The sensor is composed of a matrix of floating vacuum thermal transistors MOS split into two parts, one exposed to IR radiation and the other one shielded. The differential reading between the segments, allows the sensor to remove self-heating effects. The STHS34PF80 also incorporates algorithms to detect and discriminate between stationary and moving objects. These features enable the sensor to work as a human presence and motion sensor in different applications such as alarm systems, anti-intruder systems, smart lighting, and room occupancy.

<section class="grid cards" style="grid-template-columns: repeat(auto-fit,minmax(8rem,1fr));" markdown>

-   <a href="https://www.sparkfun.com/products/22494">
	**SparkFun Human Presence and Motion Sensor - STHS34PF80 (Qwiic)**<br>
	**SKU:** SEN-22494

	---

	<figure markdown>
	Product Thumbnail
	</figure></a>

	<center>
	[QR code to product page&nbsp;&nbsp;Purchase from SparkFun :fontawesome-solid-cart-plus:{ .heart }](https://www.sparkfun.com/products/22494){ .md-button .md-button--primary }
	</center>

-   <a href="https://www.sparkfun.com/products/23253">
	**SparkFun Qwiic Mini Human Presence and Motion Sensor - STHS34PF80**<br>
	**SKU:** SEN-23253

	---

	<figure markdown>
	Product image
	</figure></a>

	<center>
	[QR code to product page&nbsp;&nbsp;&nbsp;Purchase from SparkFun :fontawesome-solid-cart-plus:{ .heart }](https://www.sparkfun.com/products/23253){ .md-button .md-button--primary }
	</center>

</section>

The sensor can operate in multiple lighting conditions and is unaffected by visible light or other bands thanks to the 5 to 20&micro;m optical band-pass filter. The STHS34PF80 has an output data rates between 0.25 to 30 Hz and an available single-shot, which are accessed through its I²C/SPI interface. The SparkFun Qwiic Human Presence and Motion Sensor boards are available in both the standard 1"x1" Qwiic form factor and the *mini* breakout board. *(The mini form-factor is also panel mount compatible for use in enclosures. (1))*
{ .annotate }

1. Please refer to the [hardware implementation guidelines](./assets/component_documentation/an5983-hardware-implementation-guidelines-for-the-sths34pf80-infrared-sensor-stmicroelectronics.pdf) for the STHS34PF80 sensor.

## :fontawesome-solid-list-check:&nbsp;Required Materials
To get started, users will need a few items. Now some users may already have a few of these items, feel free to modify your cart accordingly.

<div class="annotate" markdown>

* Computer with an operating system (OS) that is compatible with all the software installation requirements
* A compatible microcontroller/Arduino board; we recommend the [SparkFun RedBoard Plus](https://www.sparkfun.com/products/18158).
* [USB 3.1 Cable A to C - 3 Foot](https://www.sparkfun.com/products/14743) - Used to interface with the RedBoard Plus (1)
* [SparkFun Qwiic Cable Kit](https://www.sparkfun.com/products/15081) (2)
* [SparkFun Human Presence and Motion Sensor - STHS34PF80](https://www.sparkfun.com/products/22494) (3)

</div>

1. If your computer doesn't have a USB-A slot, then choose an appropriate cable or adapter.
2. Check out our [other Qwiic cable options](https://www.sparkfun.com/search/results?term=qwiic+cable).
3. The [mini version](https://www.sparkfun.com/products/23253) of this product is panel mount compatible.

<div class="grid cards col-4" markdown>

-   <a href="https://www.sparkfun.com/products/14743">
	<figure markdown>
	USB 3.1 Cable A to C - 3 Foot
	</figure>

	---

	**USB 3.1 Cable A to C - 3 Foot**<br>
	CAB-14743</a>

-   <a href="https://www.sparkfun.com/products/18158">
	<figure markdown>
	Product Thumbnail
	</figure>

	---

	**SparkFun RedBoard Plus**<br>
	DEV-18158</a>

-   <a href="https://www.sparkfun.com/products/15081">
	<figure markdown>
	Product Thumbnail
	</figure>

	---

	**SparkFun Qwiic Cable Kit**<br>
	KIT-15081</a>

-   <a href="https://www.sparkfun.com/products/22494">
	<figure markdown>
	Product Thumbnail
	</figure>

	---

	**SparkFun Human Presence and Motion Sensor - STHS34PF80 (Qwiic)**<br>
	SEN-22494</a>

-   <a href="https://www.sparkfun.com/products/22494">
	<figure markdown>
	Product Thumbnail
	</figure>

	---

	**SparkFun Qwiic Mini Human Presence and Motion Sensor - STHS34PF80**<br>
	SEN-23253</a>

</div>

??? note "Headers and Wiring"
	To add headers or hookup wires, users will need [soldering equipment](https://www.sparkfun.com/categories/49) and [headers](https://www.sparkfun.com/categories/381)/[wire](https://www.sparkfun.com/search/results?term=hook-up+wire).

	!!! tip "New to soldering?"
		Check out our [How to Solder: Through-Hole Soldering](https://learn.sparkfun.com/tutorials/5) tutorial for a quick introduction!

		<div class="grid cards col-4" markdown align="center">

		-   <a href="https://learn.sparkfun.com/tutorials/5">
			<figure markdown>
			Tutorial Thumbnail
			</figure>

			---

			**How to Solder: Through-Hole Soldering**</a>

		</div>

	<div class="grid cards col-4" markdown>

	-   <a href="https://www.sparkfun.com/products/9325">
		<figure markdown>
		Product Thumbnail
		</figure>

		---

		**Solder Lead Free - 100-gram Spool**<br>
		TOL-09325</a>

	-   <a href="https://www.sparkfun.com/products/14228">
		<figure markdown>
		Product Thumbnail
		</figure>

		---

		**Weller WLC100 Soldering Station**<br>
		TOL-14228</a>

	-   <a href="https://www.sparkfun.com/products/14579">
		<figure markdown>
		Product Thumbnail
		</figure>

		---

		**Chip Quik No-Clean Flux Pen - 10mL**<br>
		TOL-14579</a>

	-   <a href="https://www.sparkfun.com/products/116">
		<figure markdown>
		Product Thumbnail
		</figure>

		---

		**Break Away Headers - Straight**<br>
		PRT-00116</a>

	-   <a href="https://www.sparkfun.com/products/11375">
		<figure markdown>
		Product Thumbnail
		</figure>

		---

		**Hook-Up Wire - Assortment (Stranded, 22 AWG)**<br>
		PRT-11375</a>

	</div>

??? note "Jumper Modification"
	To modify the [jumpers](../hardware_overview/#jumpers), users will need [soldering equipment](https://www.sparkfun.com/categories/49) and/or a [hobby knife](https://www.sparkfun.com/categories/379).

	!!! tip "New to jumper pads?"
		Check out our [Jumper Pads and PCB Traces Tutorial](https://learn.sparkfun.com/tutorials/664) for a quick introduction!

		<div class="grid cards col-4" markdown align="center">

		-   <a href="https://learn.sparkfun.com/tutorials/664">
			<figure markdown>
			Tutorial thumbnail
			</figure>

			---

			**How to Work with Jumper Pads and PCB Traces**</a>

		</div>

	<div class="grid cards col-4" markdown>

	-   <a href="https://www.sparkfun.com/products/9325">
		<figure markdown>
		Product Thumbnail
		</figure>

		---

		**Solder Lead Free - 100-gram Spool**<br>
		TOL-09325</a>

	-   <a href="https://www.sparkfun.com/products/14228">
		<figure markdown>
		Product Thumbnail
		</figure>

		---

		**Weller WLC100 Soldering Station**<br>
		TOL-14228</a>

	-   <a href="https://www.sparkfun.com/products/14579">
		<figure markdown>
		Product Thumbnail
		</figure>

		---

		**Chip Quik No-Clean Flux Pen - 10mL**<br>
		TOL-14579</a>

	-   <a href="https://www.sparkfun.com/products/9200">
		<figure markdown>
		Product Thumbnail
		</figure>

		---

		**Hobby Knife**<br>
		TOL-09200</a>

	</div>

## :material-bookshelf:&nbsp;Suggested Reading

As a more sophisticated product, we will skip over the more fundamental tutorials (i.e. [**Ohm's Law**](https://learn.sparkfun.com/tutorials/voltage-current-resistance-and-ohms-law) and [**What is Electricity?**](https://learn.sparkfun.com/tutorials/what-is-electricity)). However, below are a few tutorials that may help users familiarize themselves with various aspects of the board.

<div class="grid cards col-4" markdown align="center">

-   <a href="https://learn.sparkfun.com/tutorials/61"><figure markdown>
	Installing the Arduino IDE
	</figure>

	---

	**Installing the Arduino IDE**</a>

-   <a href="https://learn.sparkfun.com/tutorials/15"><figure markdown>
	Installing an Arduino Library
	</figure>

	---

	**Installing an Arduino Library**</a>

-   <a href="https://learn.sparkfun.com/tutorials/908">
	<figure markdown>
	Tutorial Thumbnail
	</figure>

	---

	**How to Install CH340 Drivers**</a>

-   <a href="https://learn.sparkfun.com/tutorials/62">
	<figure markdown>
	Tutorial Thumbnail
	</figure>

	---

	**Logic Levels**</a>

-   <a href="https://learn.sparkfun.com/tutorials/82">
	<figure markdown>
	Tutorial Thumbnail
	</figure>

	---

	**I2C**</a>

-   <a href="https://learn.sparkfun.com/tutorials/16">
	<figure markdown>
	Tutorial Thumbnail
	</figure>

	---

	**SPI**</a>

-   <a href="https://learn.sparkfun.com/tutorials/112">
	<figure markdown>
	Tutorial Thumbnail
	</figure>

	---

	**Serial Terminal Basics**</a>

-   <a href="https://learn.sparkfun.com/tutorials/5">
	<figure markdown>
	Tutorial Thumbnail
	</figure>

	---

	**How to Solder: Through-Hole Soldering**</a>

-   <a href="https://learn.sparkfun.com/tutorials/664">
	<figure markdown>
	Tutorial Thumbnail
	</figure>

	---

	**How to Work with Jumper Pads and PCB Traces**</a>

</div>

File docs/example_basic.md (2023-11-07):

## Description
Once the [Arduino library has been installed](../software_overview/#sparkfun-sths34pf80-arduino-library), the [`Example1_BasicReadings.ino`](https://github.com/sparkfun/SparkFun_STHS34PF80_Arduino_Library/blob/main/examples/Example1_BasicReadings) example file can be accessed from the **File** > **Examples** > **SparkFun STHS34PF80 Arduino Library** > **Example1_BasicReadings** drop-down menu. This example reads the human presence detection values from the STHS34PF80 sensor through the I<sup>2</sup>C interface and displays them in the [Serial Monitor](https://learn.sparkfun.com/tutorials/112).

??? code "`Example1_BasicReadings.ino`"
	??? info "Code Verification"
		This code was last verified to be functional under the following parameters:

			--8<-- "https://raw.githubusercontent.com/sparkfun/SparkFun_STHS34PF80_Arduino_Library/main/examples/Example1_BasicReadings/Example1_BasicReadings.ino:15:18"

	```  c++ linenums="1"
	--8<-- "https://raw.githubusercontent.com/sparkfun/SparkFun_STHS34PF80_Arduino_Library/main/examples/Example1_BasicReadings/Example1_BasicReadings.ino"
	```

## Hardware Connections
For this example, users simply need to connect their Qwiic Human Presence/Motion Sensor board to their microcontroller, utilizing the I<sup>2</sup>C interface. With the recommended hardware, users can easily connect their boards with the Qwiic connection system.

<div class="grid" markdown>

<div markdown>
<figure markdown>
The sensor connected to a RedBoard Plus
</figure>
</div>

<div markdown>
<figure markdown>
The sensor connected to a RedBoard Plus
</figure>
</div>

</div>

<center>
*The Qwiic Human Presence/Motion Sensor boards are connected to a RedBoard Plus, with a [Qwiic cable](https://www.sparkfun.com/products/15081).*
</center>

??? info "Pin Connections"
	For users with a development board without a Qwiic connector, the table below illustrates the required pin connections. Make sure that the logic-level of the sensor is compatible with the development board that is being connected.

	<center>

	| Sensor Pin | Microcontroller Pin | RedBoard/Uno |
	| :--------: | :------------------ | :----------: |
	| `SCL` | I<sup>2</sup>C - Serial Clock | `SCL`/`A5` |
	| `SDA` | I<sup>2</sup>C - Serial Data  | `SDA`/`A4` |
	| `3V3` | Power: **1.7 to 3.6V**        | `3.3V`     |
	| `GND` | Ground                        | `GND`      |

	</center>

## Serial Monitor
This example reads the human presence detection values from the STHS34PF80 sensor and displays them in the [Serial Monitor](https://learn.sparkfun.com/tutorials/112). It prints the raw IR presence (cm<sup>-1</sup>), if the motion detection flag was triggered, and temperature (&deg;C).

<figure markdown>
Data stream in the serial monitor
<figcaption markdown>
The human presence detection values being streamed from the STHS34PF80 sensor into the [Serial Monitor](https://learn.sparkfun.com/tutorials/112).
</figcaption>
</figure>

!!! tip
	For this example wave different objects in front of the sensor, with varying ranges. Objects that emit black body radiation work the best and should trigger the motion detected flag.

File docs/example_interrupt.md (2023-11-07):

## Description
The [`Example2_Interrupts.ino`](https://github.com/sparkfun/SparkFun_STHS34PF80_Arduino_Library/blob/main/examples/Example2_Interrupts) example file can be accessed from the **File** > **Examples** > **SparkFun STHS34PF80 Arduino Library** > **Example2_Interrupts** drop-down menu. This example builds upon the previous code in [`Example1_BasicReadings.ino`](https://github.com/sparkfun/SparkFun_STHS34PF80_Arduino_Library/blob/main/examples/Example1_BasicReadings). Instead of constantly streaming the human presence detection values from the STHS34PF80 sensor, the microcontroller waits until an interrupt is triggered before data is retrieved through the I<sup>2</sup>C interface.

??? code "`Example2_Interrupts.ino`"
	??? info "Code Verification"
		This code was last verified to be functional under the following parameters:

			--8<-- "https://raw.githubusercontent.com/sparkfun/SparkFun_STHS34PF80_Arduino_Library/main/examples/Example2_Interrupts/Example2_Interrupts.ino:15:18"

	```  c++ linenums="1"
	--8<-- "https://raw.githubusercontent.com/sparkfun/SparkFun_STHS34PF80_Arduino_Library/main/examples/Example2_Interrupts/Example2_Interrupts.ino"
	```

## Hardware Connections
For this example, users simply need to connect their Qwiic Human Presence/Motion Sensor board to their microcontroller, utilizing the I<sup>2</sup>C interface and interrupt pin. Users can easily connect the I<sup>2</sup>C interface with the Qwiic connection system on their boards. To connect the interrupt pin, we recommend utilizing an [IC-hook](https://www.sparkfun.com/products/9741) for a temporary connection.

<div class="grid" markdown>

<div markdown>
<figure markdown>
The sensor connected to a RedBoard Plus
</figure>
</div>

<div markdown>
<figure markdown>
The sensor connected to a RedBoard Plus
</figure>
</div>

</div>

<center>
*The Qwiic Human Presence/Motion Sensor boards are connected to a RedBoard Plus, with a [Qwiic cable](https://www.sparkfun.com/products/15081) and an [IC-hook](https://www.sparkfun.com/products/9741).*
</center>

??? info "Pin Connections"
	For users with a development board without a Qwiic connector, the table below illustrates the required pin connections. Make sure that the logic-level of the sensor is compatible with the development board that is being connected.

	<center>

	| Sensor Pin | Microcontroller Pin | RedBoard/Uno |
	| :--------: | :------------------ | :----------: |
	| `INT` | Interrupt Pin                 | `D2`       |
	| `SCL` | I<sup>2</sup>C - Serial Clock | `SCL`/`A5` |
	| `SDA` | I<sup>2</sup>C - Serial Data  | `SDA`/`A4` |
	| `3V3` | Power: **1.7 to 3.6V**        | `3.3V`     |
	| `GND` | Ground                        | `GND`      |

	</center>

## Serial Monitor
This example waits until an interrupt is triggered by one of the detection modes before the raw IR presence value (cm<sup>-1</sup>) is retrieved from the STHS34PF80 sensor. The data is then displayed in the [Serial Monitor](https://learn.sparkfun.com/tutorials/112).

<figure markdown>
Data stream in the serial monitor
<figcaption markdown>
The human presence detection values being streamed from the STHS34PF80 sensor into the [Serial Monitor](https://learn.sparkfun.com/tutorials/112).
</figcaption>
</figure>

!!! tip
	For this example wave different objects in front of the sensor, with varying ranges in and out of the sensor's field of view. Objects that emit black body radiation work the best and should trigger the interrupt.

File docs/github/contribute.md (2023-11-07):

# Contribute: Make an Augmentation!
Spot an improvement opportunity? Feel free to contribute to our open-source design and documentation. 

## :material-file-document-multiple:&nbsp;Improve our Documentation
All of this documentation can be modified by you! Please help us make it better.

* These pages are contained in the [`docs` folder](https://github.com/sparkfun/SparkFun_Qwiic_Human_Presence_Sensor-STHS34PF80/tree/main/docs) of the [SparkFun Qwiic Human Presence/Motion Sensor-STHS34PF80 repository](https://github.com/sparkfun/SparkFun_Qwiic_Human_Presence_Sensor-STHS34PF80).

<!-- ### :material-source-pull:&nbsp;Submit a Correction -->
### Submit a Correction

1. With a GitHub account, [fork this repository](https://github.com/sparkfun/SparkFun_Qwiic_Human_Presence_Sensor-STHS34PF80/fork).
2. Add your corrections or improvements to the markdown file.
3. File a pull request with your changes, and enjoy making the ~~words~~ ~~worlds~~ world a better place.
	* Once received, the documentation specialist will automatically be notified.
	* We will review your suggested improvements to make sure they are correct and fit within our documentation standards.

## :material-cog:&nbsp;Improve our Hardware Design
All of our designs are open-source! Please help us make it better.

* Our board design files are contained in the [`Hardware` folder](https://github.com/sparkfun/SparkFun_Qwiic_Human_Presence_Sensor-STHS34PF80/tree/main/Hardware) of the [SparkFun Qwiic Human Presence/Motion Sensor-STHS34PF80 repository](https://github.com/sparkfun/SparkFun_Qwiic_Human_Presence_Sensor-STHS34PF80).

<!-- ### :material-source-pull:&nbsp;Submit a Design Enhancement -->
### Submit a Design Enhancement

1. With a GitHub account, [fork this repository](https://github.com/sparkfun/SparkFun_Qwiic_Human_Presence_Sensor-STHS34PF80/fork).
2. Add your design augmentation(s)
3. File a pull request with your changes, and enjoy making the ~~words~~ ~~worlds~~ world a better place.
	1. Once received, the engineer in charge of the original design will automatically be notified.
	2. We will review your suggested improvement(s) to verify that they are within our board design standards and meet our product design requirements.
	3. If approved, we will flag these changes for our next board revision. Congrats! 🍻

		!!! info
			Even if your suggestion is accepted, these changes may not be immediately available for purchase. We may have to cycle through our current product inventory first.

## Contributors&nbsp;:clap:
Let's provide some recognition to the contributors for this project!

GitHub Contributors Image
<br>


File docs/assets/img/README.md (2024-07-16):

img directory
====================
This folder should contain the images for the product documentation

## General Images
* `sfe_logo_sm.png` - SparkFun flame logo (Cover page for with-pdf extension)
* `sfe-logo.png` - SparkFun flame logo (favicon)

## Directory
* `hookup_guide` - Images for the hookup guide pages

## QR Codes
* [QR code generator](https://qrgenerator.org/)
	* Flame Color: #E0311D
	* Frame Color: #3C464D
	* Label Font: Arial
* [Remove meta data from svg](https://jakearchibald.github.io/svgomg/)

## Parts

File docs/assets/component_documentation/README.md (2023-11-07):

component_documentation directory
====================

A copy of the datasheets, user manuals, programming guides, etc. of the major electrical components on the board.

* [STHS34PF80 Datasheet](sths34pf80.pdf) (PDF)
	* [AN5867 - STHS34PF80 Operation Guide](an5867-sths34pf80-lowpower-highsensitivity-infrared-ir-sensor-for-presence-and-motion-detection-stmicroelectronics.pdf) (PDF)
	* [AN5983 - Hardware Implementation Guidelines](an5983-hardware-implementation-guidelines-for-the-sths34pf80-infrared-sensor-stmicroelectronics.pdf) (PDF)

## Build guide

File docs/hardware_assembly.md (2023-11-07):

---
icon: material/tools
---

## Qwiic Cable
The simplest method to connect a microcontroller to a Qwiic Human Presence/Motion Sensor board is through the Qwiic connector.

<figure markdown>
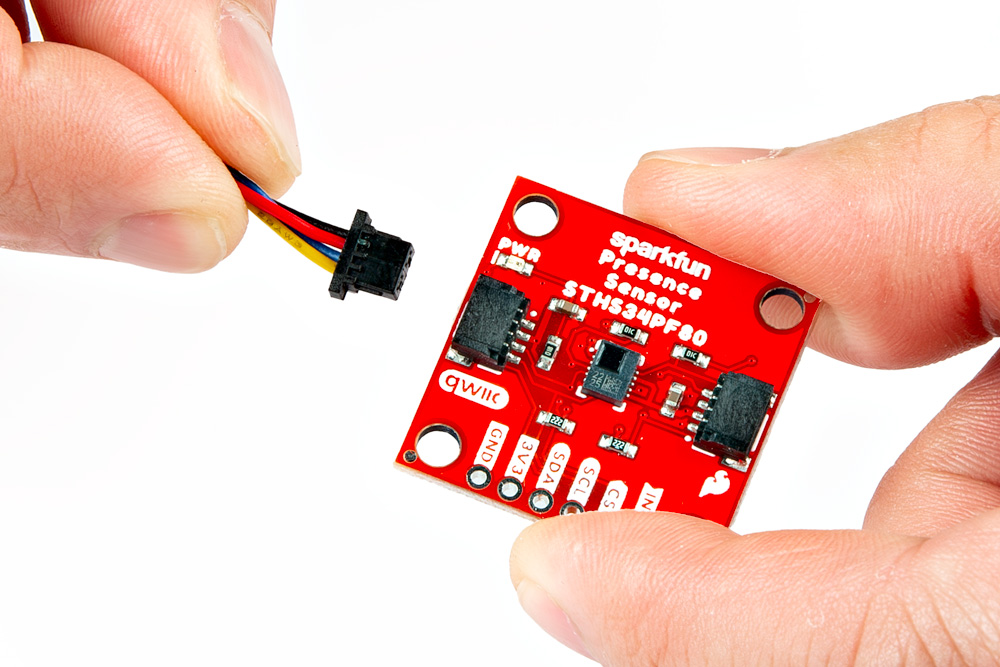
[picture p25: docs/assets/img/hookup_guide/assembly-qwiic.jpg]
Connecting Qwiic cable

<figcaption markdown>Connecting a [Qwiic cable](https://www.sparkfun.com/products/15081) to the Qwiic Human Presence/Motion Sensor board.</figcaption>
</figure>

!!! info
	The [Qwiic connection system](https://www.sparkfun.com/qwiic) is a standardized solderless, polarized connector interface that allows users to seamlessly daisy chain I<sup>2</sup>C boards together.

??? tip "Remove Tape"
	Users with the mini version of the Qwiic Human Presence/Motion Sensor board should remove the tape covering the Qwiic connector.

	<figure markdown>
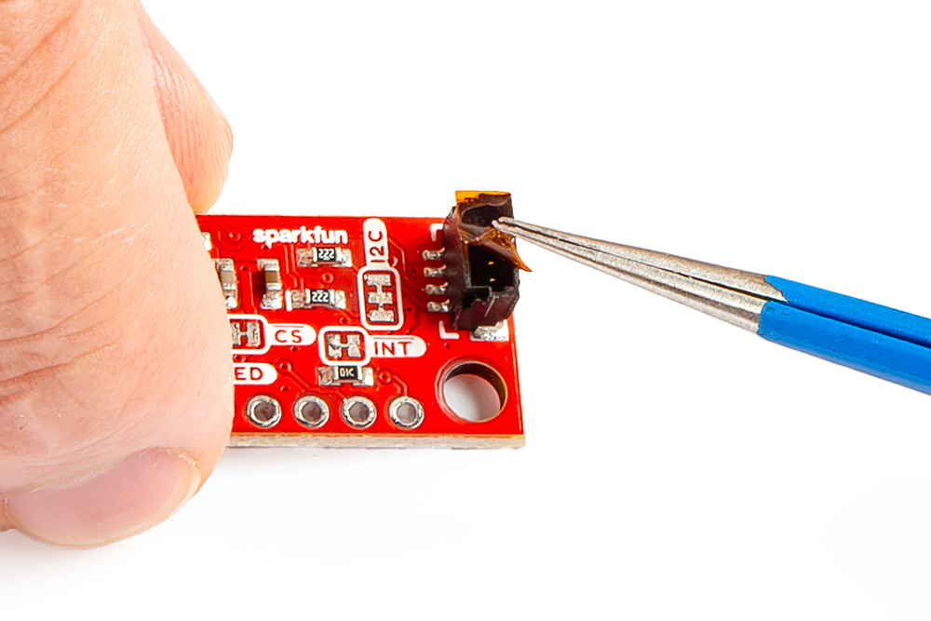
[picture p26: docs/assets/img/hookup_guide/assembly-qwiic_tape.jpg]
Removing tape
	
	<figcaption markdown>Removing the tape from the Qwiic connector to the Qwiic Mini Human Presence/Motion Sensor board.</figcaption>
	</figure>

	!!! note
		The tweezers are not necessary, they were only used for illustration purposes. *(Fingers would have obscured the camera shot.)*

	!!! info
		The tape is used by the [pick-and-place machine](https://en.wikipedia.org/wiki/Pick-and-place_machine) to place the connector on the board during assembly.

## Breakout Pins
The [PTH](https://en.wikipedia.org/wiki/Through-hole_technology "Plated Through Holes") pins on the Qwiic Human Presence/Motion Sensor board are broken out into 0.1"-spaced pins on the outer edge of the board.

??? note "New to soldering?"
	If you have never soldered before or need a quick refresher, check out our [How to Solder: Through-Hole Soldering](https://learn.sparkfun.com/tutorials/how-to-solder-through-hole-soldering) guide.

	<div class="grid cards col-4" markdown align="center">

	-   <a href="https://learn.sparkfun.com/tutorials/5">
		<figure markdown>
		Tutorial thumbnail
		</figure>

		---
		
		**How to Solder: Through-Hole Soldering**</a>

	</div>

### Hookup Wires
For a more permanent connection, users can solder wires directly to the board.

<figure markdown>
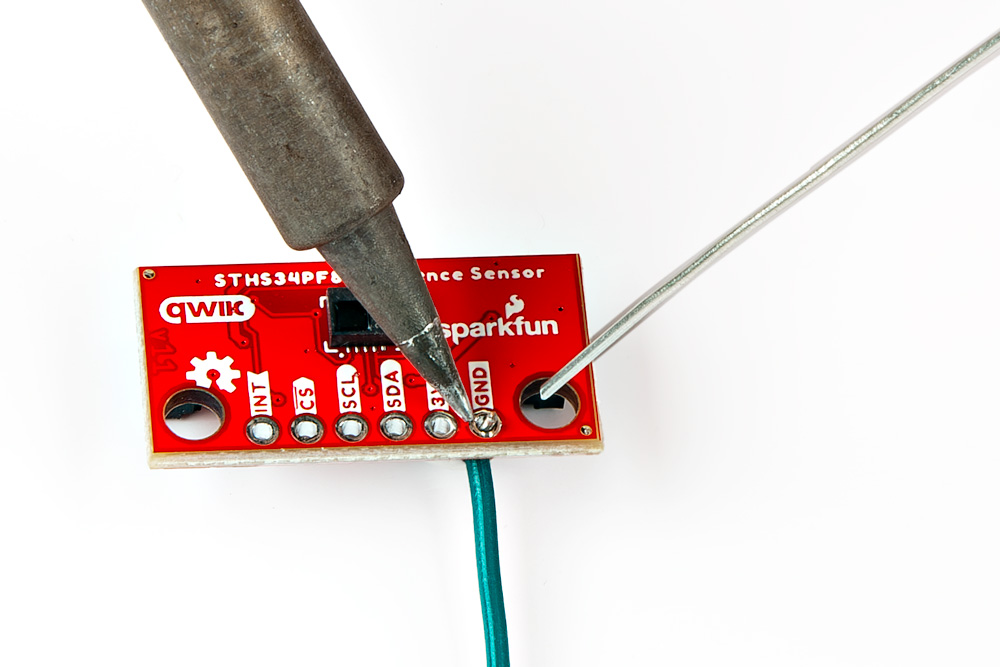
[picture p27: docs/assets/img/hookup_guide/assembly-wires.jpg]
Soldering wires

<figcaption markdown>Soldering wires to the Qwiic Mini Human Presence/Motion Sensor board.</figcaption>
</figure>

### Headers
When [selecting headers](https://www.sparkfun.com/categories/381), be sure you are aware of the functionality or physical arrangement required.

<figure markdown>
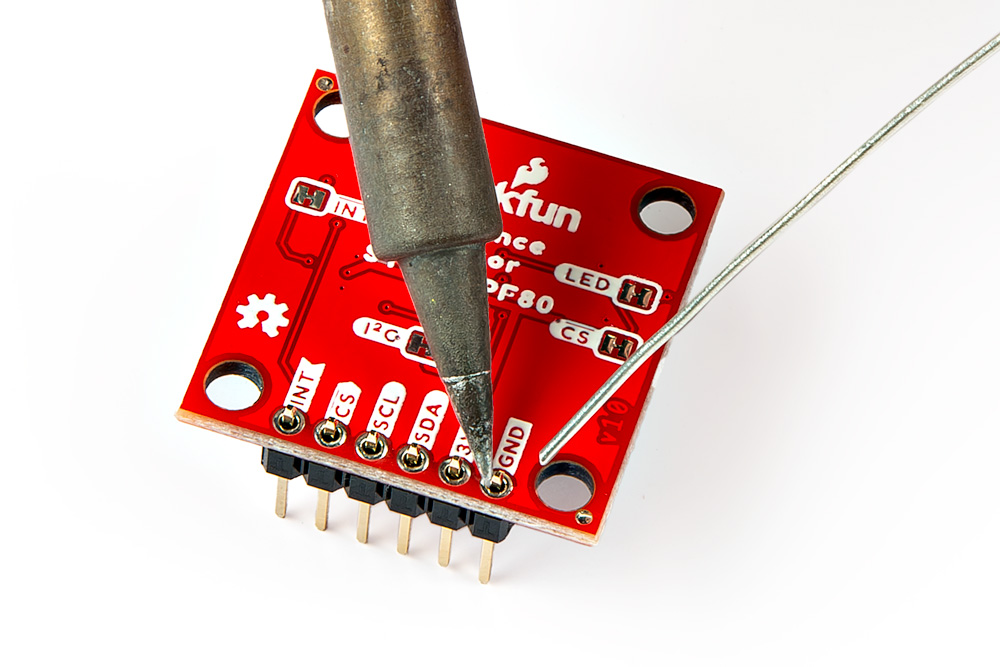
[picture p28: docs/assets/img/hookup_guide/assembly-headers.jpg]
Soldering headers

<figcaption markdown>Soldering [headers](https://www.sparkfun.com/products/116) to the Qwiic Human Presence/Motion Sensor board.</figcaption>
</figure>

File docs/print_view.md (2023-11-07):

---
hide:
  - navigation
  - toc
icon: material/printer
---

--8<-- "./docs/introduction.md:5"

# Hardware Overview
--8<-- "./docs/hardware_overview.md:5"

# Hardware Assembly
--8<-- "./docs/hardware_assembly.md:5"

# Software Overview
--8<-- "./docs/software_overview.md:5"

## Example - Basic
--8<-- "./docs/example_basic.md:2"

## Example - Interrupt
--8<-- "./docs/example_interrupt.md:2"

## Example - SPI
--8<-- "./docs/example_spi.md:2"

# Troubleshooting Tips
--8<-- "./docs/troubleshooting_tips.md:5"

# Resources
--8<-- "./docs/resources.md"

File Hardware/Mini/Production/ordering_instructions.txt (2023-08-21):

panel size, 169x93mm
PCB thickness, 1.6mm
number of layers, 2
soldermask color, Red
silkscreen color, White
oz copper, 1oz
finish, HASL lead free
stencils, top+bottom
pcs per panel, 36
min trace width, 0.1778mm / 0.0070in
min drill size, 0.3048mm / 0.0120in

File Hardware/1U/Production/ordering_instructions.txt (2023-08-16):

panel size, 143x143mm
PCB thickness, 1.6mm
number of layers, 2
soldermask color, Red
silkscreen color, White
oz copper, 1oz
finish, HASL lead free
stencils, none
pcs per panel, 25
min trace width, 0.1778mm / 0.0070in
min drill size, 0.3000mm / 0.0118in

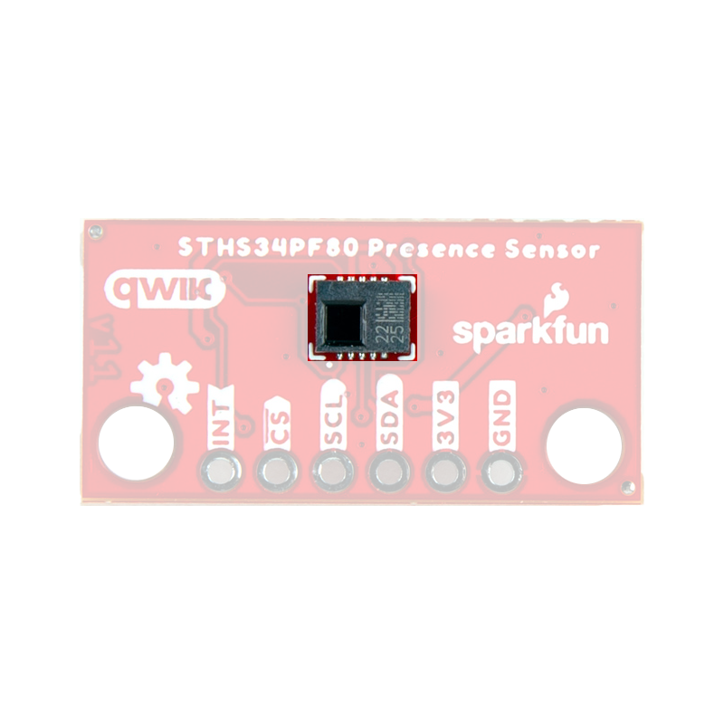
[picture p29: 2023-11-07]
docs/assets/img/hookup_guide/STHS34PF80-mini.png

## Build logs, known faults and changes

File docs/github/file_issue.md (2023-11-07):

# Did we make a mistake?

Spot something wrong? Please let us know. 

<!-- Technical Assistance Box -->
!!! warning "Need Help?"
	If you need technical assistance or more information on a product that is not working as you expected, we recommend heading on over to the [SparkFun Technical Assistance](https://www.sparkfun.com/technical_assistanc) page for some initial troubleshooting. This **Submit Issues** page is not where users should seek assistance.

	<center>
	[SparkFun Technical Assistance Page](https://www.sparkfun.com/technical_assistance){ .md-button .md-button--primary }
	</center>
	
	If you can't find what you need there, the [SparkFun Forums](https://forum.sparkfun.com/index.php) is a great place to search the product forums and ask questions.
	
	!!! info "Account Registration Required"
		For your first visit to our forum, you'll need to create a [Forum Account](https://forum.sparkfun.com/ucp.php?mode=register) to post questions.

## :material-file-document-multiple:&nbsp;Discrepancies in the Documentation

All of our documentation can be modified by you! Please help us make it better.

* The documentation files for these pages are contained in the [`docs` folder](https://github.com/sparkfun/SparkFun_Qwiic_Human_Presence_Sensor-STHS34PF80/tree/main/docs) of the [SparkFun Qwiic Human Presence/Motion Sensor-STHS34PF80 repository](https://github.com/sparkfun/SparkFun_Qwiic_Human_Presence_Sensor-STHS34PF80).

### 🔍 Spot something wrong?

If a section of the documentation is incorrect, please [open an issue](https://github.com/sparkfun/SparkFun_Qwiic_Human_Presence_Sensor-STHS34PF80/issues) and let us know.

### Do you have a suggested correction?

Please, refer to the [Contribute](../contribute/#improve-our-documentation) page.

<!-- 
1. With a GitHub account, [fork this repository](https://github.com/sparkfun/SparkFun_Qwiic_Human_Presence_Sensor-STHS34PF80/fork).
2. Add your correction(s) or improvement(s) to the markdown file(s)
3. File a pull request with your changes, and enjoy making the ~~words~~ ~~worlds~~ world a better place.
	* Once received, the documentation specialist will automatically be notified.
	* We will review your suggested improvement(s) to make sure they are correct and fit within our documentation standards. -->

## :material-cog:&nbsp;Problems in the Hardware Design

All of our designs are open-source! Please help us make it better.

* Our board design files are contained in the [`Hardware` folder](https://github.com/sparkfun/SparkFun_Qwiic_Human_Presence_Sensor-STHS34PF80/tree/main/Hardware) of the [SparkFun Qwiic Human Presence/Motion Sensor-STHS34PF80 repository](https://github.com/sparkfun/SparkFun_Qwiic_Human_Presence_Sensor-STHS34PF80).

### Does something not make sense? 🤔

If part of the design is confusing, please [open an issue](https://github.com/sparkfun/SparkFun_Qwiic_Human_Presence_Sensor-STHS34PF80/issues) and let us know.

### Did we forget to include an important function of the board? 🤦

If part of the board's functionality is missing, please [open an issue](https://github.com/sparkfun/SparkFun_Qwiic_Human_Presence_Sensor-STHS34PF80/issues) and file a feature request.

!!! tip "Design Considerations"
	Please keep in mind that we may intentionally exclude certain functions of the board to meet our product design requirements.
	
	* *For example, our Qwiic Micro boards are intended to fit on a small board layout and only use I<sup>2</sup>C communication; therefore, we may not have the SPI and interrupt pins available for users.*

### Do you wish to contribute directly to improving the board design?

Please, refer to the [Contribute](../contribute/#improve-our-hardware-design) page.

<!-- 1. With a GitHub account, [fork this repository](https://github.com/sparkfun/SparkFun_Qwiic_Human_Presence_Sensor-STHS34PF80/fork).
2. Add your design augmentation(s)
3. File a pull request with your changes, and enjoy making the ~~words~~ ~~worlds~~ world a better place.
	1. Once received, the engineer in charge of the original design will automatically be notified.
	2. We will review your suggested improvement(s) to verify that they are within our board design standards and meet our product design requirements.
	3. If approved, we will flag these changes for our next board revision. Congrats! 🍻

		!!! info
			Even if your suggestion is accepted, these changes may not be immediately available for purchase. We may have to cycle through our current product inventory first. -->

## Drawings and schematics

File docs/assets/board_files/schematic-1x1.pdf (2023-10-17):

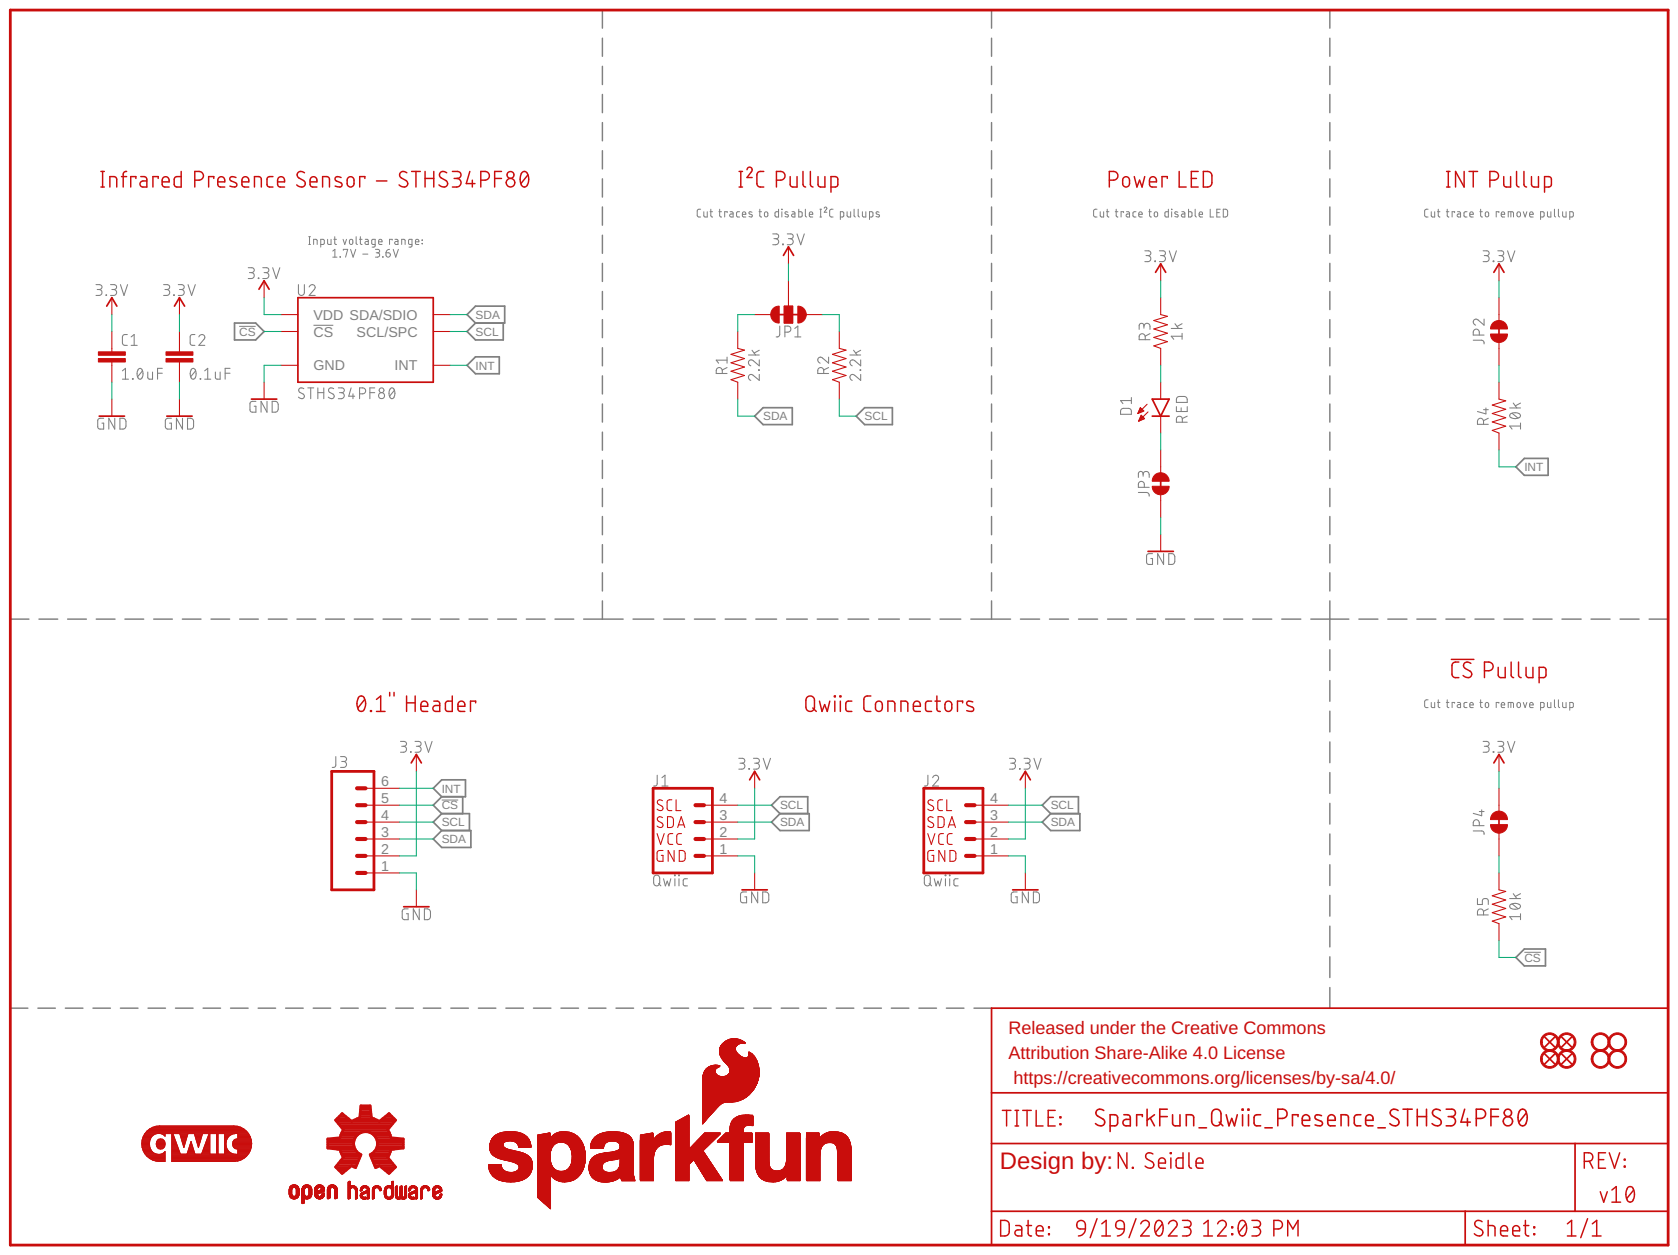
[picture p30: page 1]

CS Released under the Creative Commons

Attribution Share-Alike 4.0 License
https://creativecommons.org/licenses/by-sa/4.0/

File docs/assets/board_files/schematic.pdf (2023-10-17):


CS Released under the Creative Commons

Attribution Share-Alike 4.0 License
https://creativecommons.org/licenses/by-sa/4.0/

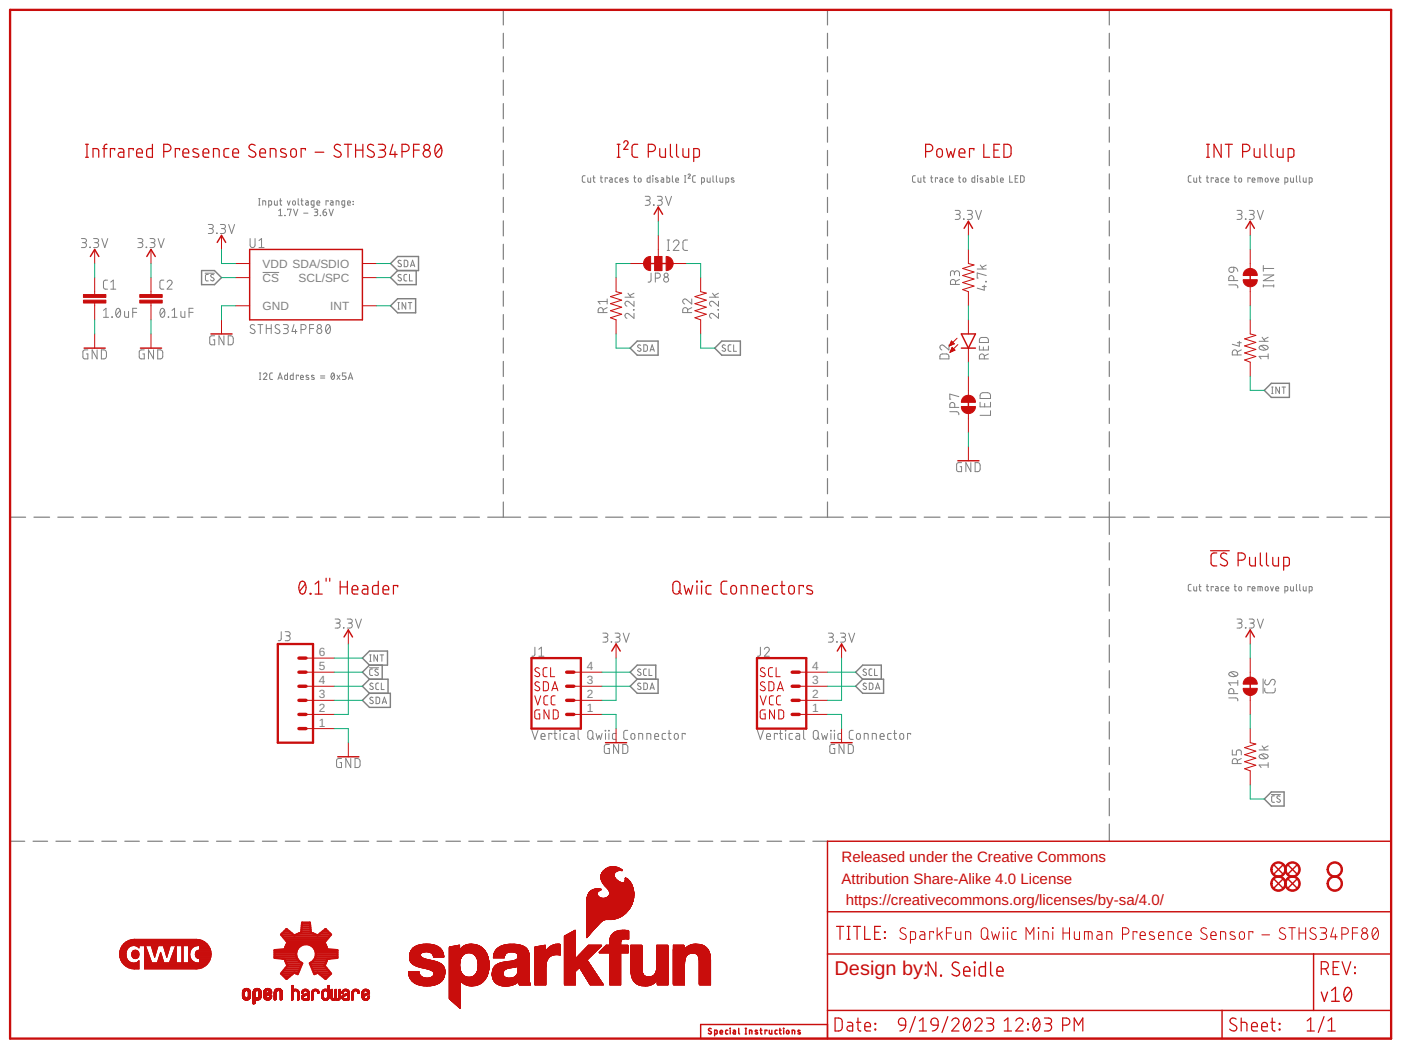
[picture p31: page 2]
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

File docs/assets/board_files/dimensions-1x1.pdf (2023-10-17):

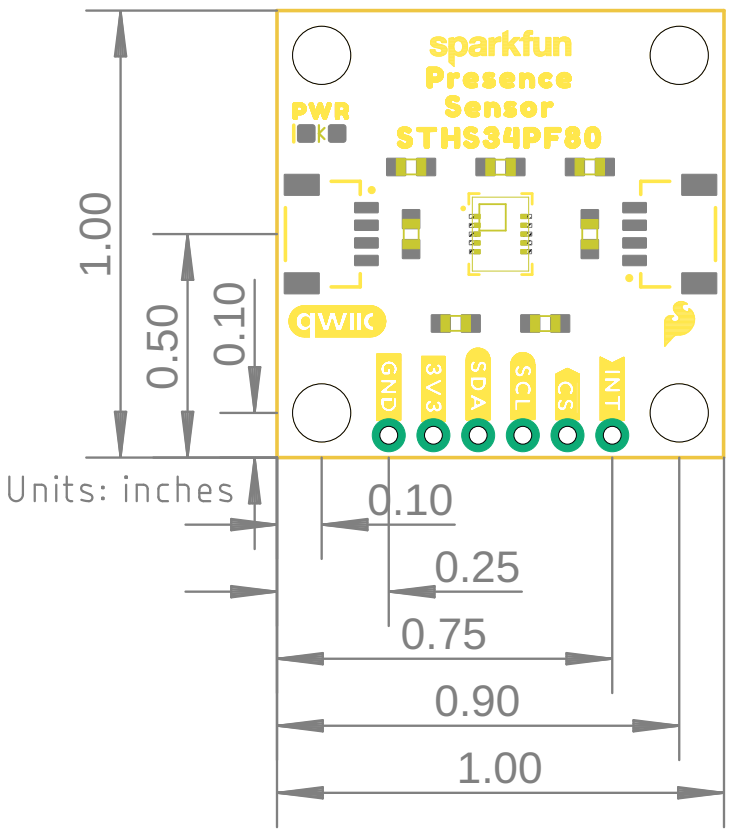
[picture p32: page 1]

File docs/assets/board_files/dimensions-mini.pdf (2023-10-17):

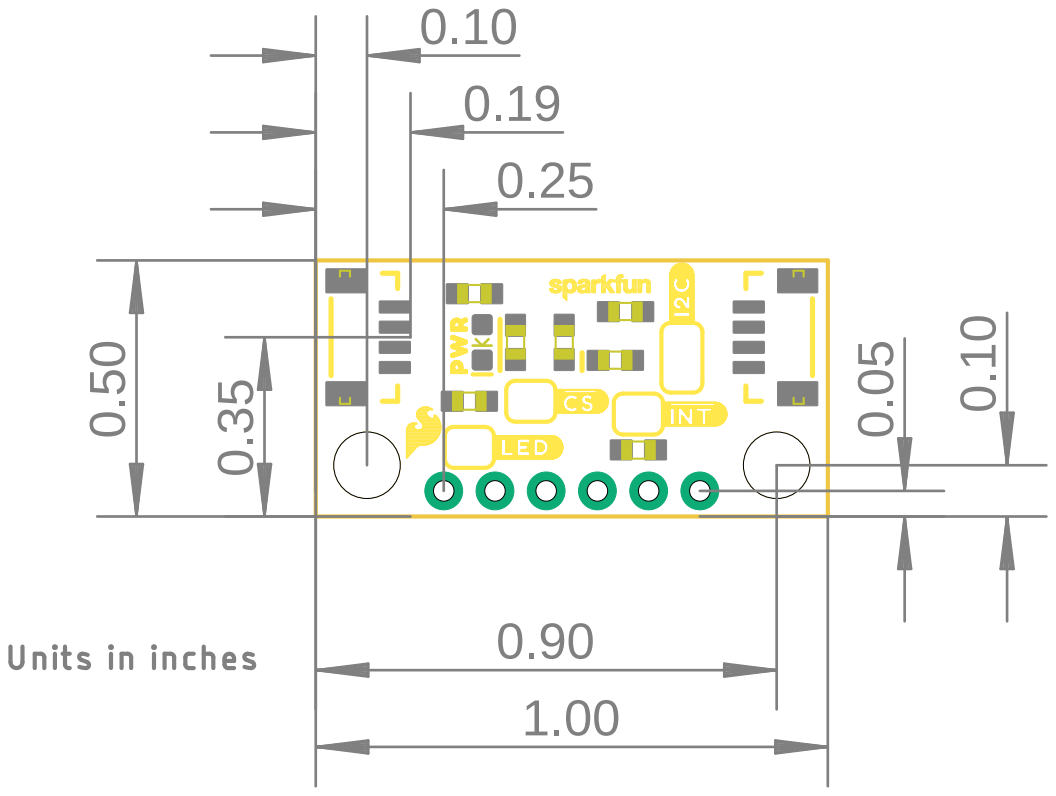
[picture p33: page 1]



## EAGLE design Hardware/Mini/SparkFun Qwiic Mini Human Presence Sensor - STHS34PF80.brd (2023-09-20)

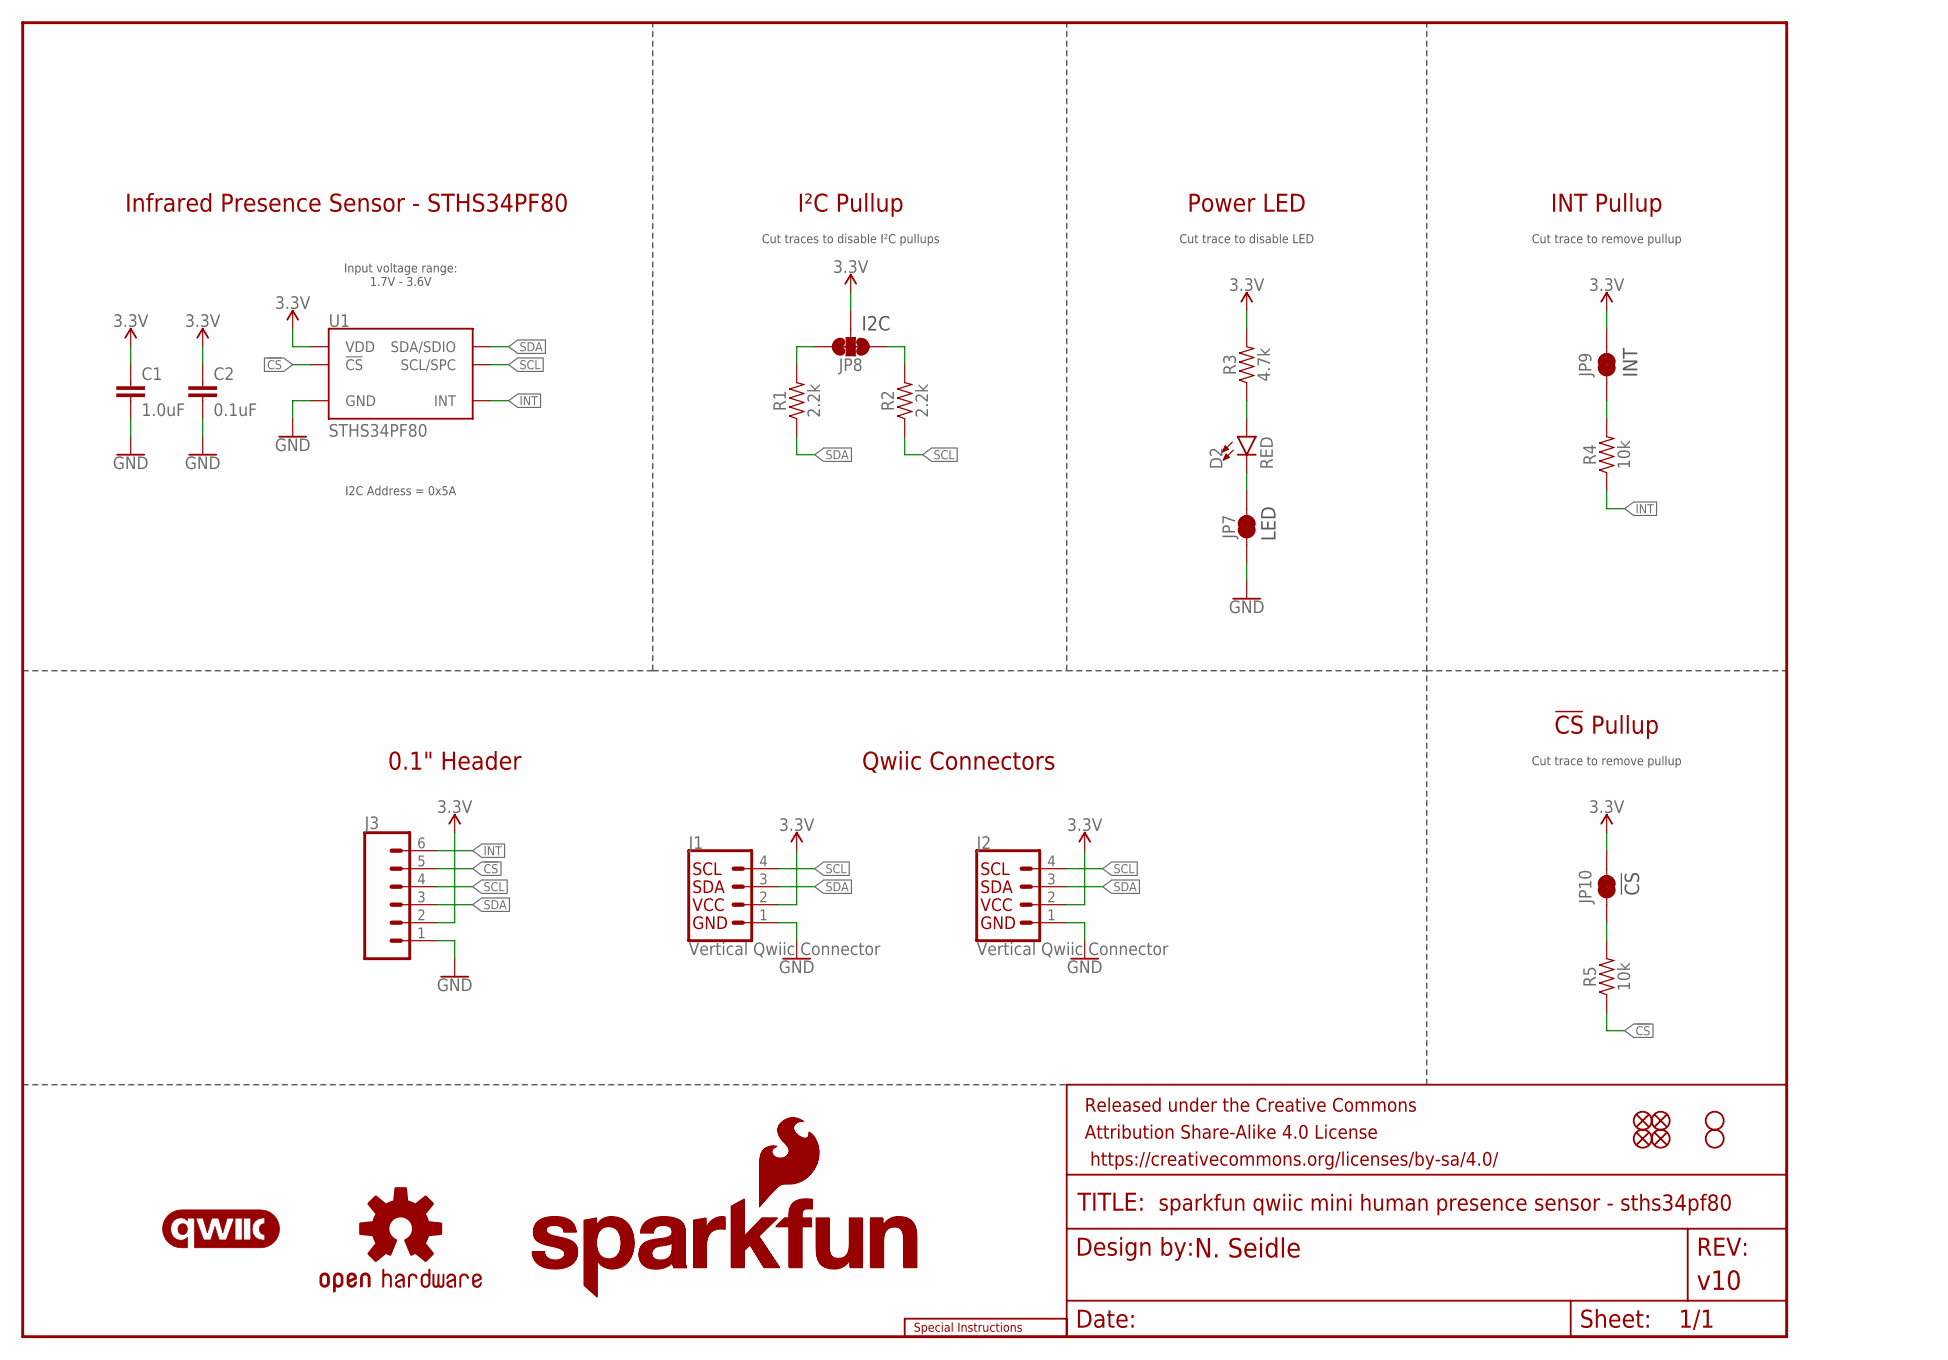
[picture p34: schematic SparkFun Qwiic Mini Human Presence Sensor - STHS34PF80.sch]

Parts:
C1: 1.0uF; 0603
C2: 0.1uF; 0603
D2: RED; LED-0603
FRAME1: FRAME-LETTER; CREATIVE_COMMONS
J1, J2: Vertical Qwiic Connector; JST04_1MM_VERT
J3: CONN_06NO_SILK_FEMALE_PTH; 1X06_NO_SILK
JP1, JP2, JP5, JP6: FIDUCIALUFIDUCIAL; FIDUCIAL-MICRO
JP3, JP4: STAND-OFF
JP7, JP9, JP10: JUMPER-SMT_2_NC_TRACE_SILK; SMT-JUMPER_2_NC_TRACE_SILK
JP8: JUMPER-SMT_3_2-NC_TRACE_SILK; SMT-JUMPER_3_2-NC_TRACE_SILK
LOGO1: OSHW-LOGOS; OSHW-LOGO-S
LOGO2: SFE_LOGO_NAME_FLAME7_MM; SFE_LOGO_NAME_FLAME_7MM
LOGO3: QWIIC_LOGO_CONNECTOR; QWIIC_5.5MM
LOGO4: SFE_LOGO_NAME5_MM; SFE_LOGO_NAME_5MM
LOGO5: SPECIAL_INSTRUCTIONS-ORDERING; ORDERING_INSTRUCTIONS
LOGO6: SFE_LOGO_FLAME.1_INCH; SFE_LOGO_FLAME_.1
R1, R2: 2.2k; 0603
R3: 4.7k; 0603
R4, R5: 10k; 0603
U1: STHS34PF80; OLGA-10L

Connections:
3.3V: C1.1, C2.1, J1.2, J2.2, J3.2, JP8.2, JP9.2, JP10.2, R3.2, U1.6 (VDD), U1.9 (VDD)
!CS!: J3.5, R5.1, U1.3 (!CS!)
GND: C1.2, C2.2, J1.1, J2.1, J3.1, JP7.1, U1.2 (GND), U1.7 (GND), U1.8 (GND)
INT: J3.6, R4.1, U1.10 (INT)
unnamed: D2.C, JP7.2
unnamed: JP8.3, R1.2
unnamed: JP8.1, R2.2
unnamed: D2.A, R3.1
unnamed: JP9.1, R4.2
unnamed: JP10.1, R5.2
SCL: J1.4, J2.4, J3.4, R2.1, U1.1 (SCL/SPC)
SDA: J1.3, J2.3, J3.3, R1.1, U1.4 (SDA/SDIO)

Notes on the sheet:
Qwiic Connectors
Cut trace to disable LED
Cut trace to remove pullup
0.1" Header
I²C Pullup
Power LED
INT Pullup
Infrared Presence Sensor - STHS34PF80
Cut traces to disable I²C pullups
Input voltage range: 1.7V - 3.6V
!CS! Pullup
LED
INT
I2C
!CS
I2C Address = 0x5A

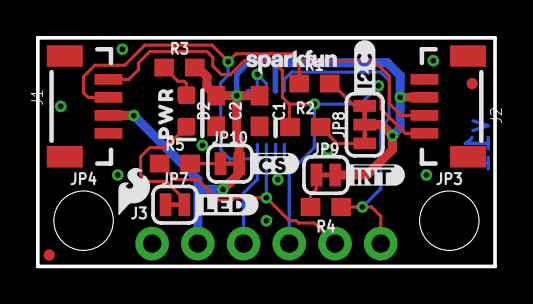
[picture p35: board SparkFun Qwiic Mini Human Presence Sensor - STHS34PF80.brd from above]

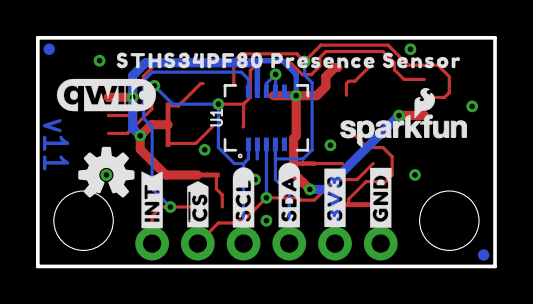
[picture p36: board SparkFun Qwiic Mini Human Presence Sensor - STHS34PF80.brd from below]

Board: 2 copper layers, 25.4 x 12.7 mm, 41 parts (13 on the bottom side), 12 nets.

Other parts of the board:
U$1: #3V3#36
U$2: ##CS#36
U$3: #SDA#5
U$4: #SCL#6
U$5: #INT#37
U$6: STHS34PF80_PRESENCE_SENSOR35
U$7: PWR9
U$8: #I2C#0
U$9: ##CS#6
U$10: #LED#8
U$11: ##INT#9
U$13: #GND#35

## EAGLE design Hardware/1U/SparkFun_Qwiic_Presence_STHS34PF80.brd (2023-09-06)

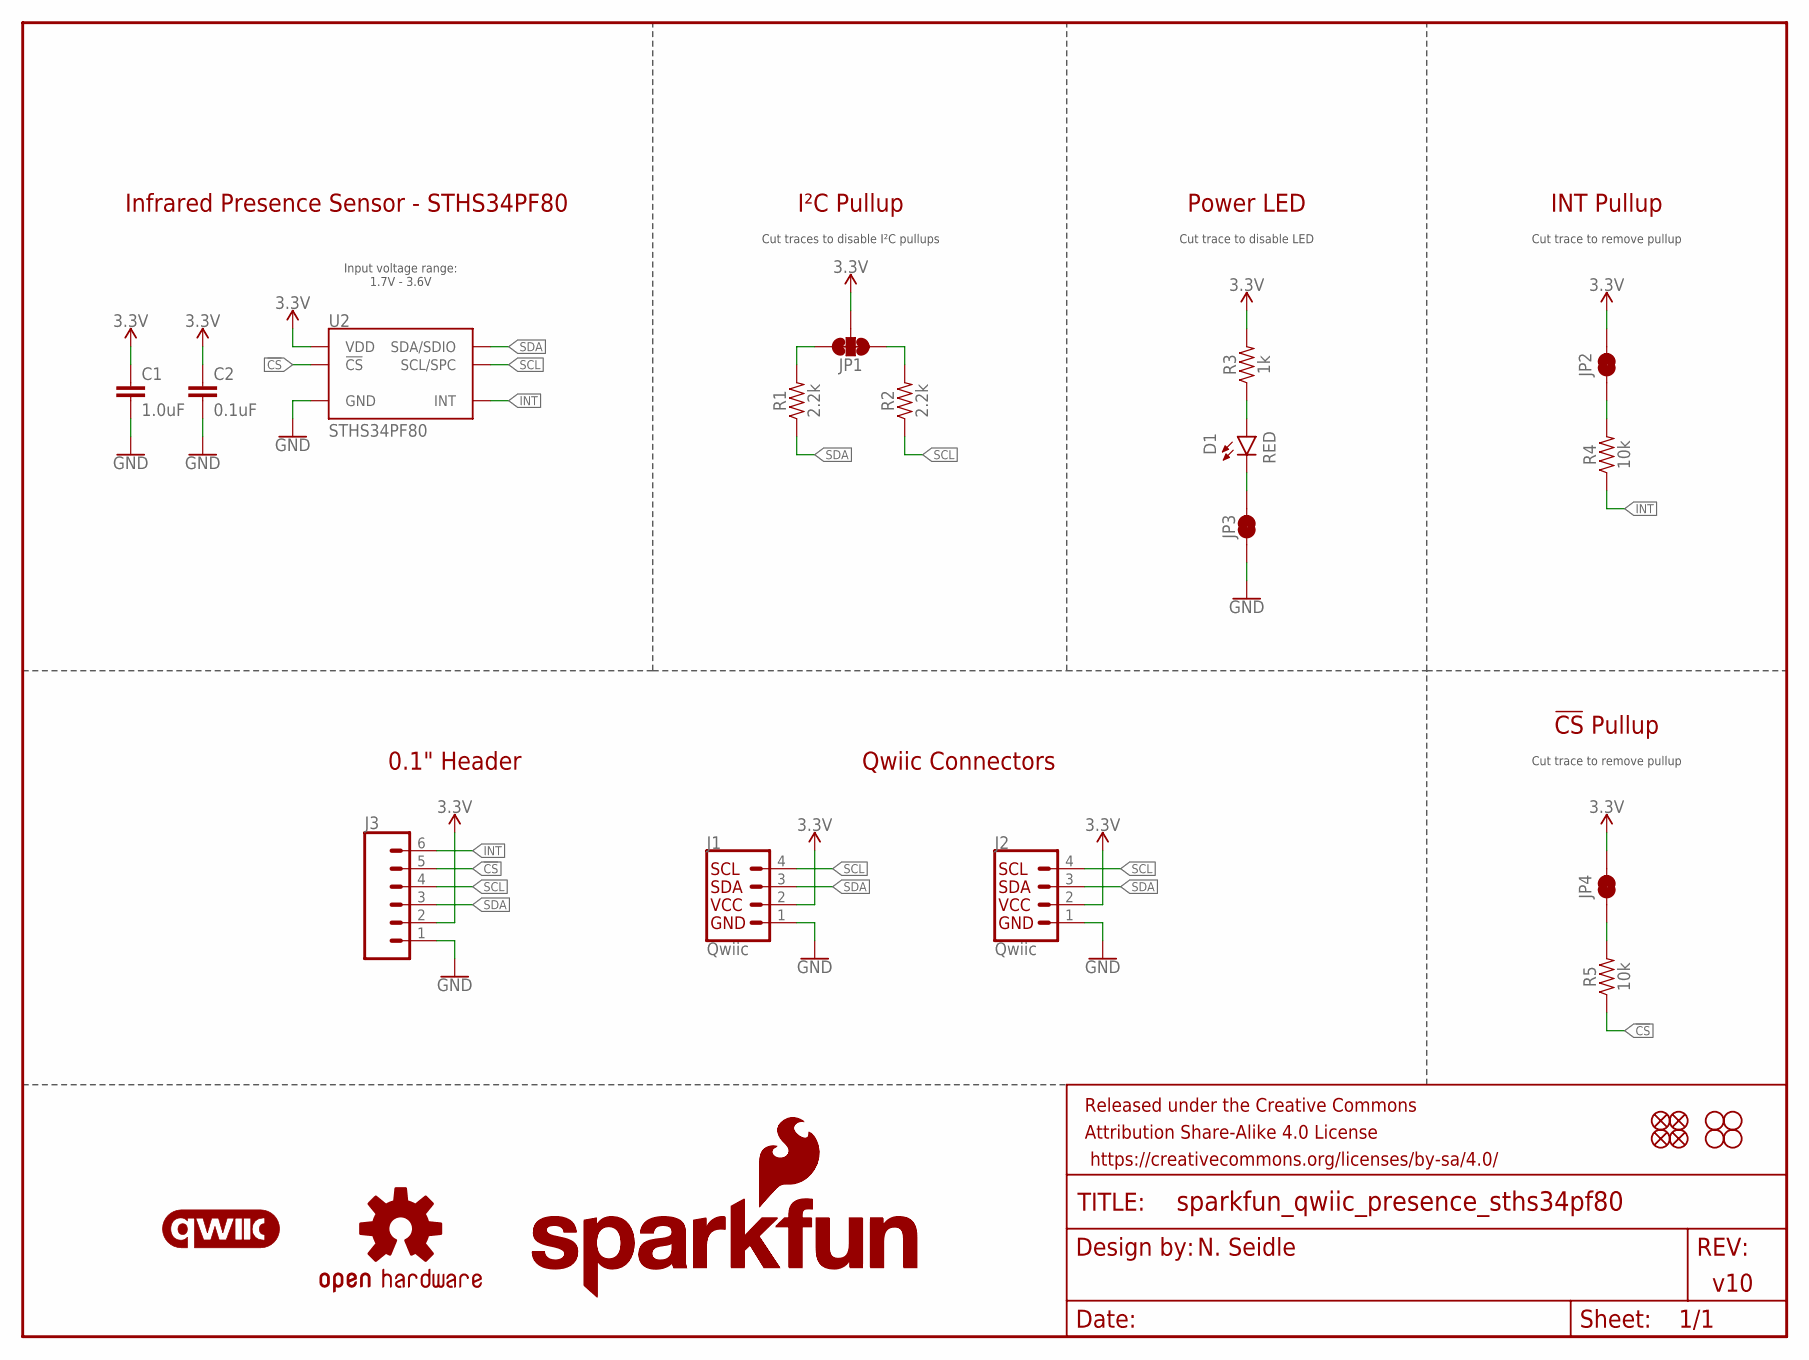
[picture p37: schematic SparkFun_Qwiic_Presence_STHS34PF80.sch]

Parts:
C1: 1.0uF; 0603
C2: 0.1uF; 0603
D1: RED; LED-0603
FD1, FD2, FD3, FD4: FIDUCIAL1X2; FIDUCIAL-1X2
FRAME2: FRAME-LETTER; CREATIVE_COMMONS
H1, H2, H3, H4: STAND-OFF
J1, J2: Qwiic; JST04_1MM_RA
J3: CONN_06NO_SILK_NO_POP; 1X06_NO_SILK
JP1: JUMPER-SMT_3_2-NC_TRACE_SILK; SMT-JUMPER_3_2-NC_TRACE_SILK
JP2, JP3, JP4: JUMPER-SMT_2_NC_TRACE_SILK; SMT-JUMPER_2_NC_TRACE_SILK
LOGO1: OSHW-LOGOS; OSHW-LOGO-S
LOGO2: SFE_LOGO_NAME_FLAME.1_INCH; SFE_LOGO_NAME_FLAME_.1
LOGO3: QWIIC_LOGO_CONNECTOR; QWIIC_5.5MM
LOGO4: SFE_LOGO_NAME8_MM; SFE_LOGO_NAME_8MM
LOGO6: SFE_LOGO_FLAME.1_INCH; SFE_LOGO_FLAME_.1
R1, R2: 2.2k; 0603
R3: 1k; 0603
R4, R5: 10k; 0603
U2: STHS34PF80; OLGA-10L

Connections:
3.3V: C1.1, C2.1, J1.2, J2.2, J3.2, JP1.2, JP2.2, JP4.2, R3.2, U2.6 (VDD), U2.9 (VDD)
!CS!: J3.5, R5.1, U2.3 (!CS!)
GND: C1.2, C2.2, J1.1, J2.1, J3.1, JP3.1, U2.2 (GND), U2.7 (GND), U2.8 (GND)
INT: J3.6, R4.1, U2.10 (INT)
unnamed: D1.C, JP3.2
unnamed: JP1.3, R1.2
unnamed: JP1.1, R2.2
unnamed: D1.A, R3.1
unnamed: JP2.1, R4.2
unnamed: JP4.1, R5.2
SCL: J1.4, J2.4, J3.4, R2.1, U2.1 (SCL/SPC)
SDA: J1.3, J2.3, J3.3, R1.1, U2.4 (SDA/SDIO)

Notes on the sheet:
Qwiic Connectors
Cut trace to disable LED
Cut trace to remove pullup
0.1" Header
I²C Pullup
Power LED
INT Pullup
Infrared Presence Sensor - STHS34PF80
Cut traces to disable I²C pullups
v10
N. Seidle
Input voltage range: 1.7V - 3.6V
!CS! Pullup

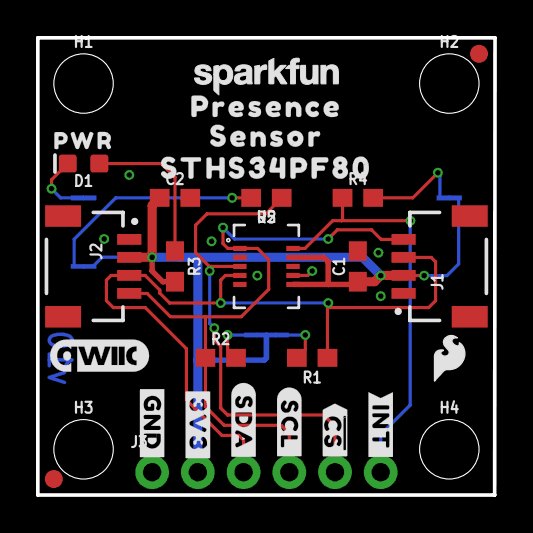
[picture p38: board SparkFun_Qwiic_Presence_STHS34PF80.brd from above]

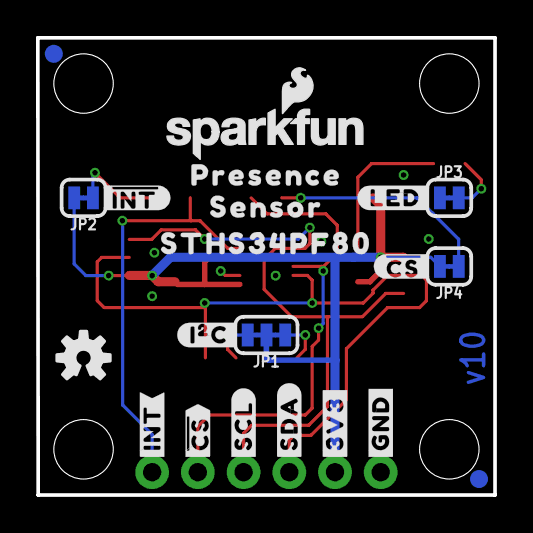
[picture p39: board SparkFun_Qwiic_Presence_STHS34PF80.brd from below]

Board: 2 copper layers, 25.4 x 25.4 mm, 53 parts (21 on the bottom side), 12 nets.

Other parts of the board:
U$1: #I�C#0
U$2: ##CS##0
U$3, U$19: #3V3#0
U$4: #INT#1
U$5, U$6: STHS34PF800
U$7, U$8: PRESENCE0
U$9: PWR11
U$10: ##INT##0
U$11: #SDA#0
U$12, U$14: SENSOR1
U$13: ##CS##1
U$15: #INT#2
U$16, U$18: #GND#4
U$17: #LED#10
U$20: #SDA#5
U$21: #SCL#6
U$22: #SCL#0
U$23: ##CS#0

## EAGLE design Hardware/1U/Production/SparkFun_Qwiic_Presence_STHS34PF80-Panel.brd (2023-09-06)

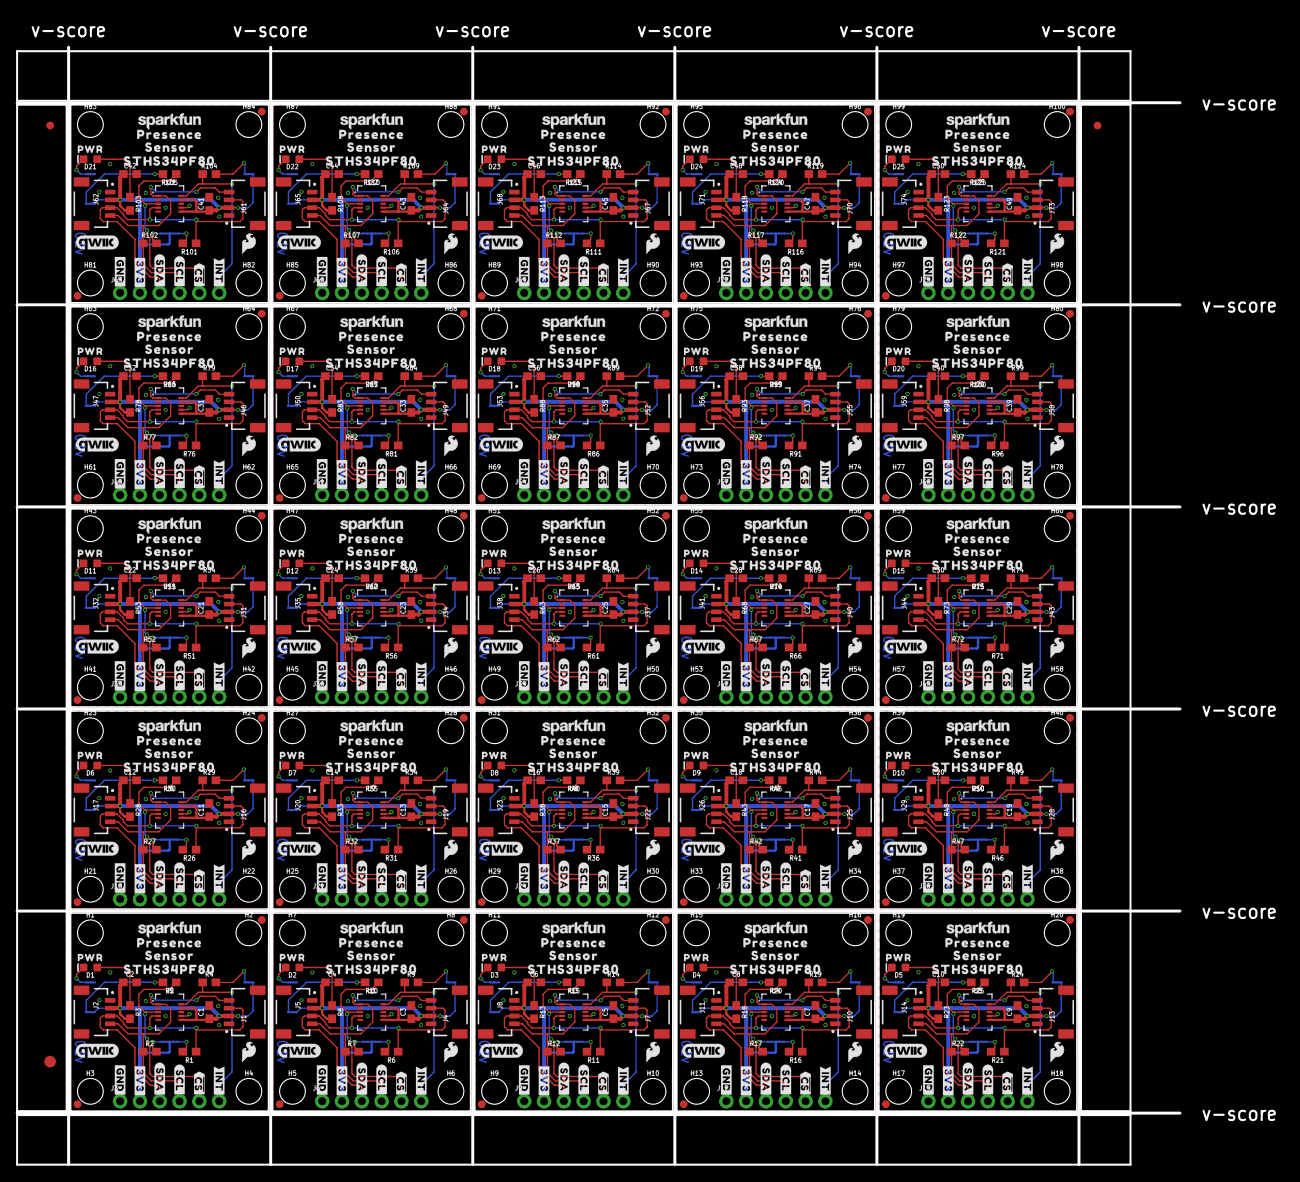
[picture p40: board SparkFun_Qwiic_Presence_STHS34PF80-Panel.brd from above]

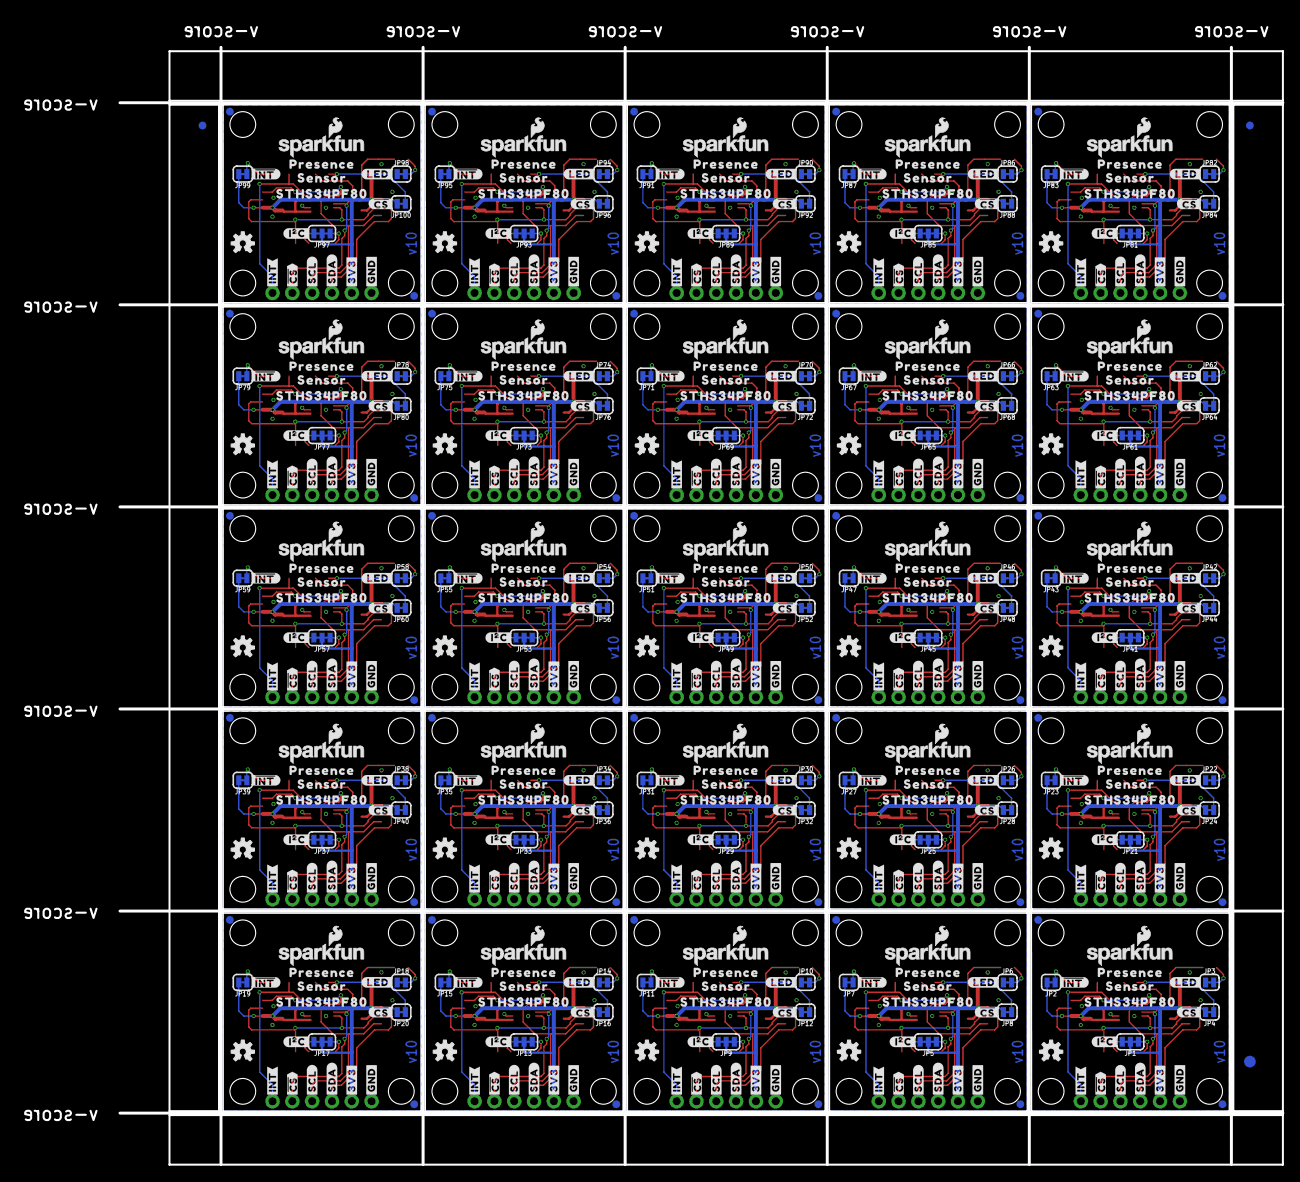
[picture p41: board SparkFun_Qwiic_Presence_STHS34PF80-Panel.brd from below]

Board: 2 copper layers, 149.1 x 143.3 mm, 1306 parts (528 on the bottom side), 300 nets.

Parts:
C1, C3, C5, C7, C9, C11, C13, C15, C17, C19, C21, C23, C25, C27, C29, C31, C33, C35, C37, C39, C41, C43, C45, C47, C49: 1.0uF; 0603
C2, C4, C6, C8, C10, C12, C14, C16, C18, C20, C22, C24, C26, C28, C30, C32, C34, C36, C38, C40, C42, C44, C46, C48, C50: 0.1uF; 0603
D1, D2, D3, D4, D5, D6, D7, D8, D9, D10, D11, D12, D13, D14, D15, D16, D17, D18, D19, D20, D21, D22, D23, D24, D25: RED; LED-0603
E$1, E$2, E$3, E$4: FIDUCIAL-1X2
E$5, E$6: FIDUCIAL-1.5X3
FD1, FD2, FD3, FD4, FD5, FD6, FD7, FD8, FD9, FD10, FD11, FD12, FD13, FD14, FD15, FD16, FD17, FD18, FD19, FD20, FD21, FD22, FD23, FD24, FD25, FD26, FD27, FD28, FD29, FD30, FD31, FD32, FD33, FD34, FD35, FD36, FD37, FD38, FD39, FD40, FD41, FD42, FD43, FD44, FD45, FD46, FD47, FD48, FD49, FD50, FD51, FD52, FD53, FD54, FD55, FD56, FD57, FD58, FD59, FD60, FD61, FD62, FD63, FD64, FD65, FD66, FD67, FD68, FD69, FD70, FD71, FD72, FD73, FD74, FD75, FD76, FD77, FD78, FD79, FD80, FD81, FD82, FD83, FD84, FD85, FD86, FD87, FD88, FD89, FD90, FD91, FD92, FD93, FD94, FD95, FD96, FD97, FD98, FD99, FD100: FIDUCIAL1X2; FIDUCIAL-1X2
H1, H2, H3, H4, H5, H6, H7, H8, H9, H10, H11, H12, H13, H14, H15, H16, H17, H18, H19, H20, H21, H22, H23, H24, H25, H26, H27, H28, H29, H30, H31, H32, H33, H34, H35, H36, H37, H38, H39, H40, H41, H42, H43, H44, H45, H46, H47, H48, H49, H50, H51, H52, H53, H54, H55, H56, H57, H58, H59, H60, H61, H62, H63, H64, H65, H66, H67, H68, H69, H70, H71, H72, H73, H74, H75, H76, H77, H78, H79, H80, H81, H82, H83, H84, H85, H86, H87, H88, H89, H90, H91, H92, H93, H94, H95, H96, H97, H98, H99, H100: STAND-OFF
J1, J2, J4, J5, J7, J8, J10, J11, J13, J14, J16, J17, J19, J20, J22, J23, J25, J26, J28, J29, J31, J32, J34, J35, J37, J38, J40, J41, J43, J44, J46, J47, J49, J50, J52, J53, J55, J56, J58, J59, J61, J62, J64, J65, J67, J68, J70, J71, J73, J74: Qwiic; JST04_1MM_RA
J3, J6, J9, J12, J15, J18, J21, J24, J27, J30, J33, J36, J39, J42, J45, J48, J51, J54, J57, J60, J63, J66, J69, J72, J75: 1X06_NO_SILK
JP1, JP5, JP9, JP13, JP17, JP21, JP25, JP29, JP33, JP37, JP41, JP45, JP49, JP53, JP57, JP61, JP65, JP69, JP73, JP77, JP81, JP85, JP89, JP93, JP97: JUMPER-SMT_3_2-NC_TRACE_SILK; SMT-JUMPER_3_2-NC_TRACE_SILK
JP2, JP3, JP4, JP6, JP7, JP8, JP10, JP11, JP12, JP14, JP15, JP16, JP18, JP19, JP20, JP22, JP23, JP24, JP26, JP27, JP28, JP30, JP31, JP32, JP34, JP35, JP36, JP38, JP39, JP40, JP42, JP43, JP44, JP46, JP47, JP48, JP50, JP51, JP52, JP54, JP55, JP56, JP58, JP59, JP60, JP62, JP63, JP64, JP66, JP67, JP68, JP70, JP71, JP72, JP74, JP75, JP76, JP78, JP79, JP80, JP82, JP83, JP84, JP86, JP87, JP88, JP90, JP91, JP92, JP94, JP95, JP96, JP98, JP99, JP100: JUMPER-SMT_2_NC_TRACE_SILK; SMT-JUMPER_2_NC_TRACE_SILK
LOGO1, LOGO5, LOGO11, LOGO16, LOGO21, LOGO26, LOGO31, LOGO36, LOGO41, LOGO46, LOGO51, LOGO56, LOGO61, LOGO66, LOGO71, LOGO76, LOGO81, LOGO86, LOGO91, LOGO96, LOGO101, LOGO106, LOGO111, LOGO116, LOGO121: OSHW-LOGOS; OSHW-LOGO-S
LOGO2, LOGO8, LOGO13, LOGO18, LOGO23, LOGO28, LOGO33, LOGO38, LOGO43, LOGO48, LOGO53, LOGO58, LOGO63, LOGO68, LOGO73, LOGO78, LOGO83, LOGO88, LOGO93, LOGO98, LOGO103, LOGO108, LOGO113, LOGO118, LOGO123: SFE_LOGO_NAME_FLAME.1_INCH; SFE_LOGO_NAME_FLAME_.1
LOGO3, LOGO7, LOGO12, LOGO17, LOGO22, LOGO27, LOGO32, LOGO37, LOGO42, LOGO47, LOGO52, LOGO57, LOGO62, LOGO67, LOGO72, LOGO77, LOGO82, LOGO87, LOGO92, LOGO97, LOGO102, LOGO107, LOGO112, LOGO117, LOGO122: QWIIC_LOGO_CONNECTOR; QWIIC_5.5MM
LOGO4, LOGO10, LOGO15, LOGO20, LOGO25, LOGO30, LOGO35, LOGO40, LOGO45, LOGO50, LOGO55, LOGO60, LOGO65, LOGO70, LOGO75, LOGO80, LOGO85, LOGO90, LOGO95, LOGO100, LOGO105, LOGO110, LOGO115, LOGO120, LOGO125: SFE_LOGO_NAME8_MM; SFE_LOGO_NAME_8MM
LOGO6, LOGO9, LOGO14, LOGO19, LOGO24, LOGO29, LOGO34, LOGO39, LOGO44, LOGO49, LOGO54, LOGO59, LOGO64, LOGO69, LOGO74, LOGO79, LOGO84, LOGO89, LOGO94, LOGO99, LOGO104, LOGO109, LOGO114, LOGO119, LOGO124: SFE_LOGO_FLAME.1_INCH; SFE_LOGO_FLAME_.1
R1, R2, R6, R7, R11, R12, R16, R17, R21, R22, R26, R27, R31, R32, R36, R37, R41, R42, R46, R47, R51, R52, R56, R57, R61, R62, R66, R67, R71, R72, R76, R77, R81, R82, R86, R87, R91, R92, R96, R97, R101, R102, R106, R107, R111, R112, R116, R117, R121, R122: 2.2k; 0603
R3, R8, R13, R18, R23, R28, R33, R38, R43, R48, R53, R58, R63, R68, R73, R78, R83, R88, R93, R98, R103, R108, R113, R118, R123: 1k; 0603
R4, R5, R9, R10, R14, R15, R19, R20, R24, R25, R29, R30, R34, R35, R39, R40, R44, R45, R49, R50, R54, R55, R59, R60, R64, R65, R69, R70, R74, R75, R79, R80, R84, R85, R89, R90, R94, R95, R99, R100, R104, R105, R109, R110, R114, R115, R119, R120, R124, R125: 10k; 0603
U1, U2, U3, U4, U5, U6, U7, U8, U9, U10, U11, U12, U13, U14, U15, U16, U17, U18, U19, U20, U21, U22, U23, U24, U25: STHS34PF80; OLGA-10L
U$1, U$38, U$61, U$84, U$107, U$130, U$153, U$176, U$199, U$222, U$245, U$268, U$291, U$314, U$337, U$360, U$383, U$406, U$429, U$452, U$475, U$498, U$521, U$544, U$567: #I�C#0
U$2, U$30, U$53, U$76, U$99, U$122, U$145, U$168, U$191, U$214, U$237, U$260, U$283, U$306, U$329, U$352, U$375, U$398, U$421, U$444, U$467, U$490, U$513, U$536, U$559: ##CS##0
U$3, U$19, U$29, U$40, U$52, U$63, U$75, U$86, U$98, U$109, U$121, U$132, U$144, U$155, U$167, U$178, U$190, U$201, U$213, U$224, U$236, U$247, U$259, U$270, U$282, U$293, U$305, U$316, U$328, U$339, U$351, U$362, U$374, U$385, U$397, U$408, U$420, U$431, U$443, U$454, U$466, U$477, U$489, U$500, U$512, U$523, U$535, U$546, U$558, U$569: #3V3#0
U$4, U$31, U$54, U$77, U$100, U$123, U$146, U$169, U$192, U$215, U$238, U$261, U$284, U$307, U$330, U$353, U$376, U$399, U$422, U$445, U$468, U$491, U$514, U$537, U$560: #INT#1
U$5, U$6, U$32, U$33, U$55, U$56, U$78, U$79, U$101, U$102, U$124, U$125, U$147, U$148, U$170, U$171, U$193, U$194, U$216, U$217, U$239, U$240, U$262, U$263, U$285, U$286, U$308, U$309, U$331, U$332, U$354, U$355, U$377, U$378, U$400, U$401, U$423, U$424, U$446, U$447, U$469, U$470, U$492, U$493, U$515, U$516, U$538, U$539, U$561, U$562: STHS34PF800
U$7, U$8, U$34, U$35, U$57, U$58, U$80, U$81, U$103, U$104, U$126, U$127, U$149, U$150, U$172, U$173, U$195, U$196, U$218, U$219, U$241, U$242, U$264, U$265, U$287, U$288, U$310, U$311, U$333, U$334, U$356, U$357, U$379, U$380, U$402, U$403, U$425, U$426, U$448, U$449, U$471, U$472, U$494, U$495, U$517, U$518, U$540, U$541, U$563, U$564: PRESENCE0
U$9, U$24, U$47, U$70, U$93, U$116, U$139, U$162, U$185, U$208, U$231, U$254, U$277, U$300, U$323, U$346, U$369, U$392, U$415, U$438, U$461, U$484, U$507, U$530, U$553: PWR11
U$10, U$41, U$64, U$87, U$110, U$133, U$156, U$179, U$202, U$225, U$248, U$271, U$294, U$317, U$340, U$363, U$386, U$409, U$432, U$455, U$478, U$501, U$524, U$547, U$570: ##INT##0
U$11, U$42, U$65, U$88, U$111, U$134, U$157, U$180, U$203, U$226, U$249, U$272, U$295, U$318, U$341, U$364, U$387, U$410, U$433, U$456, U$479, U$502, U$525, U$548, U$571: #SDA#0
U$12, U$14, U$36, U$37, U$59, U$60, U$82, U$83, U$105, U$106, U$128, U$129, U$151, U$152, U$174, U$175, U$197, U$198, U$220, U$221, U$243, U$244, U$266, U$267, U$289, U$290, U$312, U$313, U$335, U$336, U$358, U$359, U$381, U$382, U$404, U$405, U$427, U$428, U$450, U$451, U$473, U$474, U$496, U$497, U$519, U$520, U$542, U$543, U$565, U$566: SENSOR1
U$13, U$43, U$66, U$89, U$112, U$135, U$158, U$181, U$204, U$227, U$250, U$273, U$296, U$319, U$342, U$365, U$388, U$411, U$434, U$457, U$480, U$503, U$526, U$549, U$572: ##CS##1
U$15, U$44, U$67, U$90, U$113, U$136, U$159, U$182, U$205, U$228, U$251, U$274, U$297, U$320, U$343, U$366, U$389, U$412, U$435, U$458, U$481, U$504, U$527, U$550, U$573: #INT#2
U$16, U$18, U$26, U$39, U$49, U$62, U$72, U$85, U$95, U$108, U$118, U$131, U$141, U$154, U$164, U$177, U$187, U$200, U$210, U$223, U$233, U$246, U$256, U$269, U$279, U$292, U$302, U$315, U$325, U$338, U$348, U$361, U$371, U$384, U$394, U$407, U$417, U$430, U$440, U$453, U$463, U$476, U$486, U$499, U$509, U$522, U$532, U$545, U$555, U$568: #GND#4
U$17, U$25, U$48, U$71, U$94, U$117, U$140, U$163, U$186, U$209, U$232, U$255, U$278, U$301, U$324, U$347, U$370, U$393, U$416, U$439, U$462, U$485, U$508, U$531, U$554: #LED#10
U$20, U$27, U$50, U$73, U$96, U$119, U$142, U$165, U$188, U$211, U$234, U$257, U$280, U$303, U$326, U$349, U$372, U$395, U$418, U$441, U$464, U$487, U$510, U$533, U$556: #SDA#5
U$21, U$28, U$51, U$74, U$97, U$120, U$143, U$166, U$189, U$212, U$235, U$258, U$281, U$304, U$327, U$350, U$373, U$396, U$419, U$442, U$465, U$488, U$511, U$534, U$557: #SCL#6
U$22, U$45, U$68, U$91, U$114, U$137, U$160, U$183, U$206, U$229, U$252, U$275, U$298, U$321, U$344, U$367, U$390, U$413, U$436, U$459, U$482, U$505, U$528, U$551, U$574: #SCL#0
U$23, U$46, U$69, U$92, U$115, U$138, U$161, U$184, U$207, U$230, U$253, U$276, U$299, U$322, U$345, U$368, U$391, U$414, U$437, U$460, U$483, U$506, U$529, U$552, U$575: ##CS#0

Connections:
3.3V: C1.1, C2.1, J1.2, J2.2, J3.2, JP1.2, JP2.2, JP4.2, R3.2, U2.6, U2.9
3.3V1: C3.1, C4.1, J4.2, J5.2, J6.2, JP5.2, JP7.2, JP8.2, R8.2, U1.6, U1.9
3.3V2: C5.1, C6.1, J7.2, J8.2, J9.2, JP9.2, JP11.2, JP12.2, R13.2, U3.6, U3.9
3.3V3: C7.1, C8.1, J10.2, J11.2, J12.2, JP13.2, JP15.2, JP16.2, R18.2, U4.6, U4.9
3.3V4: C9.1, C10.1, J13.2, J14.2, J15.2, JP17.2, JP19.2, JP20.2, R23.2, U5.6, U5.9
3.3V5: C11.1, C12.1, J16.2, J17.2, J18.2, JP21.2, JP23.2, JP24.2, R28.2, U6.6, U6.9
3.3V6: C13.1, C14.1, J19.2, J20.2, J21.2, JP25.2, JP27.2, JP28.2, R33.2, U7.6, U7.9
3.3V7: C15.1, C16.1, J22.2, J23.2, J24.2, JP29.2, JP31.2, JP32.2, R38.2, U8.6, U8.9
3.3V8: C17.1, C18.1, J25.2, J26.2, J27.2, JP33.2, JP35.2, JP36.2, R43.2, U9.6, U9.9
3.3V9: C19.1, C20.1, J28.2, J29.2, J30.2, JP37.2, JP39.2, JP40.2, R48.2, U10.6, U10.9
3.3V10: C21.1, C22.1, J31.2, J32.2, J33.2, JP41.2, JP43.2, JP44.2, R53.2, U11.6, U11.9
3.3V11: C23.1, C24.1, J34.2, J35.2, J36.2, JP45.2, JP47.2, JP48.2, R58.2, U12.6, U12.9
3.3V12: C25.1, C26.1, J37.2, J38.2, J39.2, JP49.2, JP51.2, JP52.2, R63.2, U13.6, U13.9
3.3V13: C27.1, C28.1, J40.2, J41.2, J42.2, JP53.2, JP55.2, JP56.2, R68.2, U14.6, U14.9
3.3V14: C29.1, C30.1, J43.2, J44.2, J45.2, JP57.2, JP59.2, JP60.2, R73.2, U15.6, U15.9
3.3V15: C31.1, C32.1, J46.2, J47.2, J48.2, JP61.2, JP63.2, JP64.2, R78.2, U16.6, U16.9
3.3V16: C33.1, C34.1, J49.2, J50.2, J51.2, JP65.2, JP67.2, JP68.2, R83.2, U17.6, U17.9
3.3V17: C35.1, C36.1, J52.2, J53.2, J54.2, JP69.2, JP71.2, JP72.2, R88.2, U18.6, U18.9
3.3V18: C37.1, C38.1, J55.2, J56.2, J57.2, JP73.2, JP75.2, JP76.2, R93.2, U19.6, U19.9
3.3V19: C39.1, C40.1, J58.2, J59.2, J60.2, JP77.2, JP79.2, JP80.2, R98.2, U20.6, U20.9
3.3V20: C41.1, C42.1, J61.2, J62.2, J63.2, JP81.2, JP83.2, JP84.2, R103.2, U21.6, U21.9
3.3V21: C43.1, C44.1, J64.2, J65.2, J66.2, JP85.2, JP87.2, JP88.2, R108.2, U22.6, U22.9
3.3V22: C45.1, C46.1, J67.2, J68.2, J69.2, JP89.2, JP91.2, JP92.2, R113.2, U23.6, U23.9
3.3V23: C47.1, C48.1, J70.2, J71.2, J72.2, JP93.2, JP95.2, JP96.2, R118.2, U24.6, U24.9
3.3V24: C49.1, C50.1, J73.2, J74.2, J75.2, JP97.2, JP99.2, JP100.2, R123.2, U25.6, U25.9
!CS!: J3.5, R5.1, U2.3
!CS!1: J6.5, R10.1, U1.3
!CS!2: J9.5, R15.1, U3.3
!CS!3: J12.5, R20.1, U4.3
!CS!4: J15.5, R25.1, U5.3
!CS!5: J18.5, R30.1, U6.3
!CS!6: J21.5, R35.1, U7.3
!CS!7: J24.5, R40.1, U8.3
!CS!8: J27.5, R45.1, U9.3
!CS!9: J30.5, R50.1, U10.3
!CS!10: J33.5, R55.1, U11.3
!CS!11: J36.5, R60.1, U12.3
!CS!12: J39.5, R65.1, U13.3
!CS!13: J42.5, R70.1, U14.3
!CS!14: J45.5, R75.1, U15.3
!CS!15: J48.5, R80.1, U16.3
!CS!16: J51.5, R85.1, U17.3
!CS!17: J54.5, R90.1, U18.3
!CS!18: J57.5, R95.1, U19.3
!CS!19: J60.5, R100.1, U20.3
!CS!20: J63.5, R105.1, U21.3
!CS!21: J66.5, R110.1, U22.3
!CS!22: J69.5, R115.1, U23.3
!CS!23: J72.5, R120.1, U24.3
!CS!24: J75.5, R125.1, U25.3
GND: C1.2, C2.2, J1.1, J2.1, J3.1, JP3.1, U2.2, U2.7, U2.8
GND1: C3.2, C4.2, J4.1, J5.1, J6.1, JP6.1, U1.2, U1.7, U1.8
GND2: C5.2, C6.2, J7.1, J8.1, J9.1, JP10.1, U3.2, U3.7, U3.8
GND3: C7.2, C8.2, J10.1, J11.1, J12.1, JP14.1, U4.2, U4.7, U4.8
GND4: C9.2, C10.2, J13.1, J14.1, J15.1, JP18.1, U5.2, U5.7, U5.8
GND5: C11.2, C12.2, J16.1, J17.1, J18.1, JP22.1, U6.2, U6.7, U6.8
GND6: C13.2, C14.2, J19.1, J20.1, J21.1, JP26.1, U7.2, U7.7, U7.8
GND7: C15.2, C16.2, J22.1, J23.1, J24.1, JP30.1, U8.2, U8.7, U8.8
GND8: C17.2, C18.2, J25.1, J26.1, J27.1, JP34.1, U9.2, U9.7, U9.8
GND9: C19.2, C20.2, J28.1, J29.1, J30.1, JP38.1, U10.2, U10.7, U10.8
GND10: C21.2, C22.2, J31.1, J32.1, J33.1, JP42.1, U11.2, U11.7, U11.8
GND11: C23.2, C24.2, J34.1, J35.1, J36.1, JP46.1, U12.2, U12.7, U12.8
GND12: C25.2, C26.2, J37.1, J38.1, J39.1, JP50.1, U13.2, U13.7, U13.8
GND13: C27.2, C28.2, J40.1, J41.1, J42.1, JP54.1, U14.2, U14.7, U14.8
GND14: C29.2, C30.2, J43.1, J44.1, J45.1, JP58.1, U15.2, U15.7, U15.8
GND15: C31.2, C32.2, J46.1, J47.1, J48.1, JP62.1, U16.2, U16.7, U16.8
GND16: C33.2, C34.2, J49.1, J50.1, J51.1, JP66.1, U17.2, U17.7, U17.8
GND17: C35.2, C36.2, J52.1, J53.1, J54.1, JP70.1, U18.2, U18.7, U18.8
GND18: C37.2, C38.2, J55.1, J56.1, J57.1, JP74.1, U19.2, U19.7, U19.8
GND19: C39.2, C40.2, J58.1, J59.1, J60.1, JP78.1, U20.2, U20.7, U20.8
GND20: C41.2, C42.2, J61.1, J62.1, J63.1, JP82.1, U21.2, U21.7, U21.8
GND21: C43.2, C44.2, J64.1, J65.1, J66.1, JP86.1, U22.2, U22.7, U22.8
GND22: C45.2, C46.2, J67.1, J68.1, J69.1, JP90.1, U23.2, U23.7, U23.8
GND23: C47.2, C48.2, J70.1, J71.1, J72.1, JP94.1, U24.2, U24.7, U24.8
GND24: C49.2, C50.2, J73.1, J74.1, J75.1, JP98.1, U25.2, U25.7, U25.8
INT: J3.6, R4.1, U2.10
INT1: J6.6, R9.1, U1.10
INT2: J9.6, R14.1, U3.10
INT3: J12.6, R19.1, U4.10
INT4: J15.6, R24.1, U5.10
INT5: J18.6, R29.1, U6.10
INT6: J21.6, R34.1, U7.10
INT7: J24.6, R39.1, U8.10
INT8: J27.6, R44.1, U9.10
INT9: J30.6, R49.1, U10.10
INT10: J33.6, R54.1, U11.10
INT11: J36.6, R59.1, U12.10
INT12: J39.6, R64.1, U13.10
INT13: J42.6, R69.1, U14.10
INT14: J45.6, R74.1, U15.10
INT15: J48.6, R79.1, U16.10
INT16: J51.6, R84.1, U17.10
INT17: J54.6, R89.1, U18.10
INT18: J57.6, R94.1, U19.10
INT19: J60.6, R99.1, U20.10
INT20: J63.6, R104.1, U21.10
INT21: J66.6, R109.1, U22.10
INT22: J69.6, R114.1, U23.10
INT23: J72.6, R119.1, U24.10
INT24: J75.6, R124.1, U25.10
unnamed: D1.C, JP3.2
unnamed: JP1.3, R1.2
unnamed: JP1.1, R2.2
unnamed: D1.A, R3.1
unnamed: JP2.1, R4.2
unnamed: JP4.1, R5.2
unnamed: JP5.3, R6.2
unnamed: JP5.1, R7.2
unnamed: D2.A, R8.1
unnamed: JP7.1, R9.2
unnamed: D2.C, JP6.2
unnamed: JP8.1, R10.2
unnamed: JP9.3, R11.2
unnamed: JP9.1, R12.2
unnamed: D3.A, R13.1
unnamed: JP11.1, R14.2
unnamed: D3.C, JP10.2
unnamed: JP12.1, R15.2
unnamed: JP13.3, R16.2
unnamed: JP13.1, R17.2
unnamed: D4.A, R18.1
unnamed: JP15.1, R19.2
unnamed: D4.C, JP14.2
unnamed: JP16.1, R20.2
unnamed: JP17.3, R21.2
unnamed: JP17.1, R22.2
unnamed: D5.A, R23.1
unnamed: JP19.1, R24.2
unnamed: D5.C, JP18.2
unnamed: JP20.1, R25.2
unnamed: JP21.3, R26.2
unnamed: JP21.1, R27.2
unnamed: D6.A, R28.1
unnamed: JP23.1, R29.2
unnamed: D6.C, JP22.2
unnamed: JP24.1, R30.2
unnamed: JP25.3, R31.2
unnamed: JP25.1, R32.2
unnamed: D7.A, R33.1
unnamed: JP27.1, R34.2
unnamed: D7.C, JP26.2
unnamed: JP28.1, R35.2
unnamed: JP29.3, R36.2
unnamed: JP29.1, R37.2
unnamed: D8.A, R38.1
unnamed: JP31.1, R39.2
unnamed: D8.C, JP30.2
unnamed: JP32.1, R40.2
unnamed: JP33.3, R41.2
unnamed: JP33.1, R42.2
unnamed: D9.A, R43.1
unnamed: JP35.1, R44.2
unnamed: D9.C, JP34.2
unnamed: JP36.1, R45.2
unnamed: JP37.3, R46.2
unnamed: JP37.1, R47.2
unnamed: D10.A, R48.1
unnamed: JP39.1, R49.2
unnamed: D10.C, JP38.2
unnamed: JP40.1, R50.2
unnamed: JP41.3, R51.2
unnamed: JP41.1, R52.2
unnamed: D11.A, R53.1
unnamed: JP43.1, R54.2
unnamed: D11.C, JP42.2
unnamed: JP44.1, R55.2
unnamed: JP45.3, R56.2
unnamed: JP45.1, R57.2
unnamed: D12.A, R58.1
unnamed: JP47.1, R59.2
unnamed: D12.C, JP46.2
unnamed: JP48.1, R60.2
unnamed: JP49.3, R61.2
unnamed: JP49.1, R62.2
unnamed: D13.A, R63.1
unnamed: JP51.1, R64.2
unnamed: D13.C, JP50.2
unnamed: JP52.1, R65.2
unnamed: JP53.3, R66.2
unnamed: JP53.1, R67.2
unnamed: D14.A, R68.1
unnamed: JP55.1, R69.2
unnamed: D14.C, JP54.2
unnamed: JP56.1, R70.2
unnamed: JP57.3, R71.2
unnamed: JP57.1, R72.2
unnamed: D15.A, R73.1
unnamed: JP59.1, R74.2
unnamed: D15.C, JP58.2
unnamed: JP60.1, R75.2
unnamed: JP61.3, R76.2
unnamed: JP61.1, R77.2
unnamed: D16.A, R78.1
unnamed: JP63.1, R79.2
unnamed: D16.C, JP62.2
unnamed: JP64.1, R80.2
unnamed: JP65.3, R81.2
unnamed: JP65.1, R82.2
unnamed: D17.A, R83.1
unnamed: JP67.1, R84.2
unnamed: D17.C, JP66.2
unnamed: JP68.1, R85.2
unnamed: JP69.3, R86.2
unnamed: JP69.1, R87.2
unnamed: D18.A, R88.1
unnamed: JP71.1, R89.2
unnamed: D18.C, JP70.2
unnamed: JP72.1, R90.2
unnamed: JP73.3, R91.2
unnamed: JP73.1, R92.2
unnamed: D19.A, R93.1
unnamed: JP75.1, R94.2
unnamed: D19.C, JP74.2
unnamed: JP76.1, R95.2
unnamed: JP77.3, R96.2
unnamed: JP77.1, R97.2
unnamed: D20.A, R98.1
unnamed: JP79.1, R99.2
unnamed: D20.C, JP78.2
unnamed: JP80.1, R100.2
unnamed: JP81.3, R101.2
unnamed: JP81.1, R102.2
unnamed: D21.A, R103.1
unnamed: JP83.1, R104.2
unnamed: D21.C, JP82.2
unnamed: JP84.1, R105.2
unnamed: JP85.3, R106.2
unnamed: JP85.1, R107.2
unnamed: D22.A, R108.1
unnamed: JP87.1, R109.2
unnamed: D22.C, JP86.2
unnamed: JP88.1, R110.2
unnamed: JP89.3, R111.2
unnamed: JP89.1, R112.2
unnamed: D23.A, R113.1
unnamed: JP91.1, R114.2
unnamed: D23.C, JP90.2
unnamed: JP92.1, R115.2
unnamed: JP93.3, R116.2
unnamed: JP93.1, R117.2
unnamed: D24.A, R118.1
unnamed: JP95.1, R119.2
unnamed: D24.C, JP94.2
unnamed: JP96.1, R120.2
unnamed: JP97.3, R121.2
unnamed: JP97.1, R122.2
unnamed: D25.A, R123.1
unnamed: JP99.1, R124.2
unnamed: D25.C, JP98.2
unnamed: JP100.1, R125.2
SCL: J1.4, J2.4, J3.4, R2.1, U2.1
SCL1: J4.4, J5.4, J6.4, R7.1, U1.1
SCL2: J7.4, J8.4, J9.4, R12.1, U3.1
SCL3: J10.4, J11.4, J12.4, R17.1, U4.1
SCL4: J13.4, J14.4, J15.4, R22.1, U5.1
SCL5: J16.4, J17.4, J18.4, R27.1, U6.1
SCL6: J19.4, J20.4, J21.4, R32.1, U7.1
SCL7: J22.4, J23.4, J24.4, R37.1, U8.1
SCL8: J25.4, J26.4, J27.4, R42.1, U9.1
SCL9: J28.4, J29.4, J30.4, R47.1, U10.1
SCL10: J31.4, J32.4, J33.4, R52.1, U11.1
SCL11: J34.4, J35.4, J36.4, R57.1, U12.1
SCL12: J37.4, J38.4, J39.4, R62.1, U13.1
SCL13: J40.4, J41.4, J42.4, R67.1, U14.1
SCL14: J43.4, J44.4, J45.4, R72.1, U15.1
SCL15: J46.4, J47.4, J48.4, R77.1, U16.1
SCL16: J49.4, J50.4, J51.4, R82.1, U17.1
SCL17: J52.4, J53.4, J54.4, R87.1, U18.1
SCL18: J55.4, J56.4, J57.4, R92.1, U19.1
SCL19: J58.4, J59.4, J60.4, R97.1, U20.1
SCL20: J61.4, J62.4, J63.4, R102.1, U21.1
SCL21: J64.4, J65.4, J66.4, R107.1, U22.1
SCL22: J67.4, J68.4, J69.4, R112.1, U23.1
SCL23: J70.4, J71.4, J72.4, R117.1, U24.1
SCL24: J73.4, J74.4, J75.4, R122.1, U25.1
SDA: J1.3, J2.3, J3.3, R1.1, U2.4
SDA1: J4.3, J5.3, J6.3, R6.1, U1.4
SDA2: J7.3, J8.3, J9.3, R11.1, U3.4
SDA3: J10.3, J11.3, J12.3, R16.1, U4.4
SDA4: J13.3, J14.3, J15.3, R21.1, U5.4
SDA5: J16.3, J17.3, J18.3, R26.1, U6.4
SDA6: J19.3, J20.3, J21.3, R31.1, U7.4
SDA7: J22.3, J23.3, J24.3, R36.1, U8.4
SDA8: J25.3, J26.3, J27.3, R41.1, U9.4
SDA9: J28.3, J29.3, J30.3, R46.1, U10.4
SDA10: J31.3, J32.3, J33.3, R51.1, U11.4
SDA11: J34.3, J35.3, J36.3, R56.1, U12.4
SDA12: J37.3, J38.3, J39.3, R61.1, U13.4
SDA13: J40.3, J41.3, J42.3, R66.1, U14.4
SDA14: J43.3, J44.3, J45.3, R71.1, U15.4
SDA15: J46.3, J47.3, J48.3, R76.1, U16.4
SDA16: J49.3, J50.3, J51.3, R81.1, U17.4
SDA17: J52.3, J53.3, J54.3, R86.1, U18.4
SDA18: J55.3, J56.3, J57.3, R91.1, U19.4
SDA19: J58.3, J59.3, J60.3, R96.1, U20.4
SDA20: J61.3, J62.3, J63.3, R101.1, U21.4
SDA21: J64.3, J65.3, J66.3, R106.1, U22.4
SDA22: J67.3, J68.3, J69.3, R111.1, U23.4
SDA23: J70.3, J71.3, J72.3, R116.1, U24.4
SDA24: J73.3, J74.3, J75.3, R121.1, U25.4

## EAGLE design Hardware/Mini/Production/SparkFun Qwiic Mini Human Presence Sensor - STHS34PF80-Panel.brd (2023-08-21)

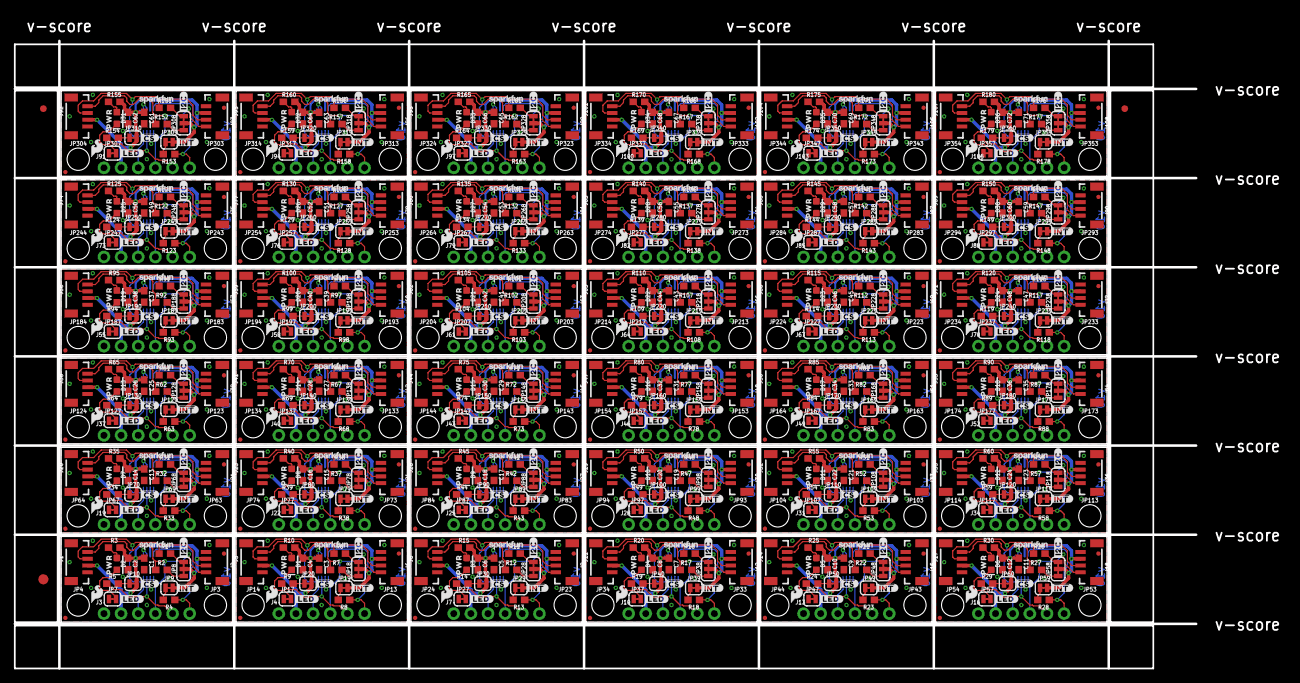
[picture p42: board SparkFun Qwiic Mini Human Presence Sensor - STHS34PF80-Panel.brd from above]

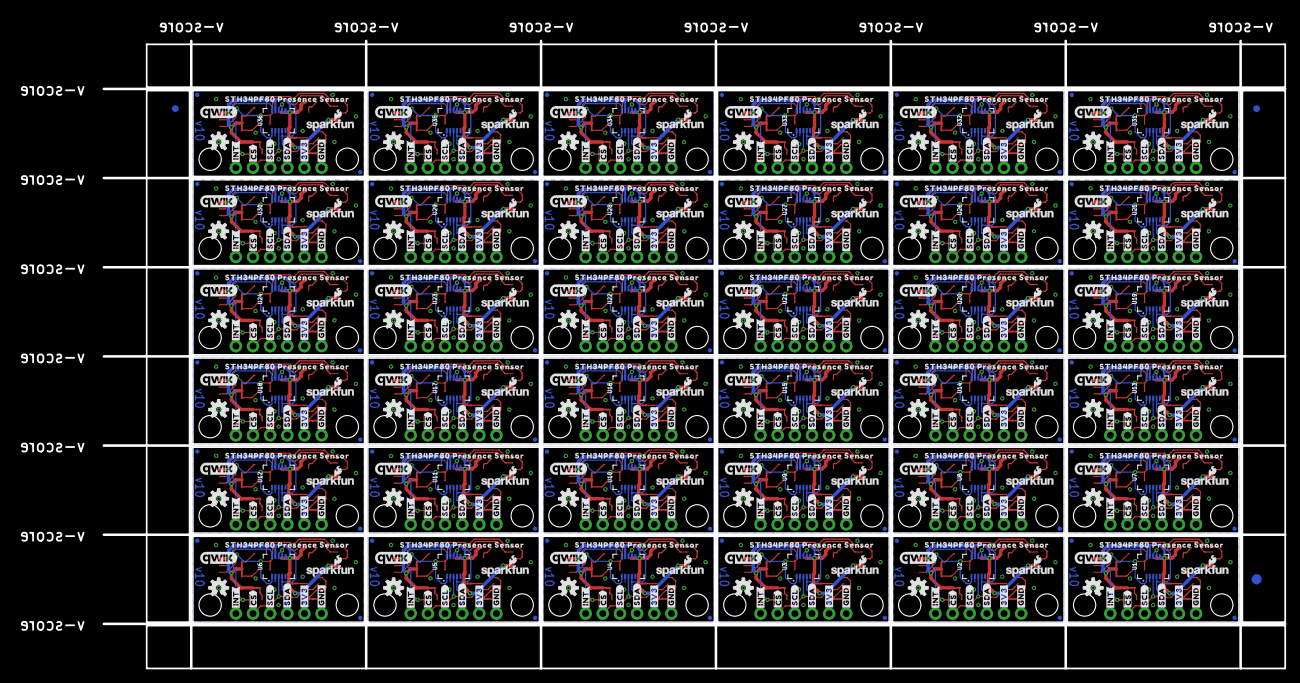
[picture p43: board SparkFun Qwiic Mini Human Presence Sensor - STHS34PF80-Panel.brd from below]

Board: 2 copper layers, 175.0 x 93.0 mm, 1410 parts (471 on the bottom side), 432 nets.

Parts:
C1, C3, C5, C7, C9, C11, C13, C15, C17, C19, C21, C23, C25, C27, C29, C31, C33, C35, C37, C39, C41, C43, C45, C47, C49, C51, C53, C55, C57, C59, C61, C63, C65, C67, C69, C71: 1.0uF; 0603
C2, C4, C6, C8, C10, C12, C14, C16, C18, C20, C22, C24, C26, C28, C30, C32, C34, C36, C38, C40, C42, C44, C46, C48, C50, C52, C54, C56, C58, C60, C62, C64, C66, C68, C70, C72: 0.1uF; 0603
D1, D2, D3, D4, D5, D6, D7, D8, D9, D10, D11, D12, D13, D14, D15, D16, D17, D18, D19, D20, D21, D22, D23, D24, D25, D26, D27, D28, D29, D30, D31, D32, D33, D34, D35, D36: RED; LED-0603
E$1, E$2, E$3, E$4: FIDUCIAL-1X2
E$5, E$6: FIDUCIAL-1.5X3
J1, J2, J5, J6, J8, J9, J11, J12, J14, J15, J17, J18, J20, J21, J23, J24, J26, J27, J29, J30, J32, J33, J35, J36, J38, J39, J41, J42, J44, J45, J47, J48, J50, J51, J53, J54, J56, J57, J59, J60, J62, J63, J65, J66, J68, J69, J71, J72, J74, J75, J77, J78, J80, J81, J83, J84, J86, J87, J89, J90, J92, J93, J95, J96, J98, J99, J101, J102, J104, J105, J107, J108: Vertical Qwiic Connector; JST04_1MM_VERT
J3, J4, J7, J10, J13, J16, J19, J22, J25, J28, J31, J34, J37, J40, J43, J46, J49, J52, J55, J58, J61, J64, J67, J70, J73, J76, J79, J82, J85, J88, J91, J94, J97, J100, J103, J106: 1X06_NO_SILK
JP1, JP2, JP5, JP6, JP11, JP12, JP15, JP16, JP21, JP22, JP25, JP26, JP31, JP32, JP35, JP36, JP41, JP42, JP45, JP46, JP51, JP52, JP55, JP56, JP61, JP62, JP65, JP66, JP71, JP72, JP75, JP76, JP81, JP82, JP85, JP86, JP91, JP92, JP95, JP96, JP101, JP102, JP105, JP106, JP111, JP112, JP115, JP116, JP121, JP122, JP125, JP126, JP131, JP132, JP135, JP136, JP141, JP142, JP145, JP146, JP151, JP152, JP155, JP156, JP161, JP162, JP165, JP166, JP171, JP172, JP175, JP176, JP181, JP182, JP185, JP186, JP191, JP192, JP195, JP196, JP201, JP202, JP205, JP206, JP211, JP212, JP215, JP216, JP221, JP222, JP225, JP226, JP231, JP232, JP235, JP236, JP241, JP242, JP245, JP246, JP251, JP252, JP255, JP256, JP261, JP262, JP265, JP266, JP271, JP272, JP275, JP276, JP281, JP282, JP285, JP286, JP291, JP292, JP295, JP296, JP301, JP302, JP305, JP306, JP311, JP312, JP315, JP316, JP321, JP322, JP325, JP326, JP331, JP332, JP335, JP336, JP341, JP342, JP345, JP346, JP351, JP352, JP355, JP356: FIDUCIALUFIDUCIAL; FIDUCIAL-MICRO
JP3, JP4, JP13, JP14, JP23, JP24, JP33, JP34, JP43, JP44, JP53, JP54, JP63, JP64, JP73, JP74, JP83, JP84, JP93, JP94, JP103, JP104, JP113, JP114, JP123, JP124, JP133, JP134, JP143, JP144, JP153, JP154, JP163, JP164, JP173, JP174, JP183, JP184, JP193, JP194, JP203, JP204, JP213, JP214, JP223, JP224, JP233, JP234, JP243, JP244, JP253, JP254, JP263, JP264, JP273, JP274, JP283, JP284, JP293, JP294, JP303, JP304, JP313, JP314, JP323, JP324, JP333, JP334, JP343, JP344, JP353, JP354: STAND-OFF
JP7, JP9, JP10, JP17, JP19, JP20, JP27, JP29, JP30, JP37, JP39, JP40, JP47, JP49, JP50, JP57, JP59, JP60, JP67, JP69, JP70, JP77, JP79, JP80, JP87, JP89, JP90, JP97, JP99, JP100, JP107, JP109, JP110, JP117, JP119, JP120, JP127, JP129, JP130, JP137, JP139, JP140, JP147, JP149, JP150, JP157, JP159, JP160, JP167, JP169, JP170, JP177, JP179, JP180, JP187, JP189, JP190, JP197, JP199, JP200, JP207, JP209, JP210, JP217, JP219, JP220, JP227, JP229, JP230, JP237, JP239, JP240, JP247, JP249, JP250, JP257, JP259, JP260, JP267, JP269, JP270, JP277, JP279, JP280, JP287, JP289, JP290, JP297, JP299, JP300, JP307, JP309, JP310, JP317, JP319, JP320, JP327, JP329, JP330, JP337, JP339, JP340, JP347, JP349, JP350, JP357, JP359, JP360: JUMPER-SMT_2_NC_TRACE_SILK; SMT-JUMPER_2_NC_TRACE_SILK
JP8, JP18, JP28, JP38, JP48, JP58, JP68, JP78, JP88, JP98, JP108, JP118, JP128, JP138, JP148, JP158, JP168, JP178, JP188, JP198, JP208, JP218, JP228, JP238, JP248, JP258, JP268, JP278, JP288, JP298, JP308, JP318, JP328, JP338, JP348, JP358: JUMPER-SMT_3_2-NC_TRACE_SILK; SMT-JUMPER_3_2-NC_TRACE_SILK
LOGO1, LOGO5, LOGO11, LOGO16, LOGO21, LOGO26, LOGO31, LOGO36, LOGO41, LOGO46, LOGO51, LOGO56, LOGO61, LOGO66, LOGO71, LOGO76, LOGO81, LOGO86, LOGO91, LOGO96, LOGO101, LOGO106, LOGO111, LOGO116, LOGO121, LOGO126, LOGO131, LOGO136, LOGO141, LOGO146, LOGO151, LOGO156, LOGO161, LOGO166, LOGO171, LOGO176: OSHW-LOGOS; OSHW-LOGO-S
LOGO2, LOGO8, LOGO13, LOGO18, LOGO23, LOGO28, LOGO33, LOGO38, LOGO43, LOGO48, LOGO53, LOGO58, LOGO63, LOGO68, LOGO73, LOGO78, LOGO83, LOGO88, LOGO93, LOGO98, LOGO103, LOGO108, LOGO113, LOGO118, LOGO123, LOGO128, LOGO133, LOGO138, LOGO143, LOGO148, LOGO153, LOGO158, LOGO163, LOGO168, LOGO173, LOGO178: SFE_LOGO_NAME_FLAME7_MM; SFE_LOGO_NAME_FLAME_7MM
LOGO3, LOGO7, LOGO12, LOGO17, LOGO22, LOGO27, LOGO32, LOGO37, LOGO42, LOGO47, LOGO52, LOGO57, LOGO62, LOGO67, LOGO72, LOGO77, LOGO82, LOGO87, LOGO92, LOGO97, LOGO102, LOGO107, LOGO112, LOGO117, LOGO122, LOGO127, LOGO132, LOGO137, LOGO142, LOGO147, LOGO152, LOGO157, LOGO162, LOGO167, LOGO172, LOGO177: QWIIC_LOGO_CONNECTOR; QWIIC_5.5MM
LOGO4, LOGO10, LOGO15, LOGO20, LOGO25, LOGO30, LOGO35, LOGO40, LOGO45, LOGO50, LOGO55, LOGO60, LOGO65, LOGO70, LOGO75, LOGO80, LOGO85, LOGO90, LOGO95, LOGO100, LOGO105, LOGO110, LOGO115, LOGO120, LOGO125, LOGO130, LOGO135, LOGO140, LOGO145, LOGO150, LOGO155, LOGO160, LOGO165, LOGO170, LOGO175, LOGO180: SFE_LOGO_NAME5_MM; SFE_LOGO_NAME_5MM
LOGO6, LOGO9, LOGO14, LOGO19, LOGO24, LOGO29, LOGO34, LOGO39, LOGO44, LOGO49, LOGO54, LOGO59, LOGO64, LOGO69, LOGO74, LOGO79, LOGO84, LOGO89, LOGO94, LOGO99, LOGO104, LOGO109, LOGO114, LOGO119, LOGO124, LOGO129, LOGO134, LOGO139, LOGO144, LOGO149, LOGO154, LOGO159, LOGO164, LOGO169, LOGO174, LOGO179: SFE_LOGO_FLAME.1_INCH; SFE_LOGO_FLAME_.1
R1, R2, R6, R7, R11, R12, R16, R17, R21, R22, R26, R27, R31, R32, R36, R37, R41, R42, R46, R47, R51, R52, R56, R57, R61, R62, R66, R67, R71, R72, R76, R77, R81, R82, R86, R87, R91, R92, R96, R97, R101, R102, R106, R107, R111, R112, R116, R117, R121, R122, R126, R127, R131, R132, R136, R137, R141, R142, R146, R147, R151, R152, R156, R157, R161, R162, R166, R167, R171, R172, R176, R177: 2.2k; 0603
R3, R10, R15, R20, R25, R30, R35, R40, R45, R50, R55, R60, R65, R70, R75, R80, R85, R90, R95, R100, R105, R110, R115, R120, R125, R130, R135, R140, R145, R150, R155, R160, R165, R170, R175, R180: 4.7k; 0603
R4, R5, R8, R9, R13, R14, R18, R19, R23, R24, R28, R29, R33, R34, R38, R39, R43, R44, R48, R49, R53, R54, R58, R59, R63, R64, R68, R69, R73, R74, R78, R79, R83, R84, R88, R89, R93, R94, R98, R99, R103, R104, R108, R109, R113, R114, R118, R119, R123, R124, R128, R129, R133, R134, R138, R139, R143, R144, R148, R149, R153, R154, R158, R159, R163, R164, R168, R169, R173, R174, R178, R179: 10k; 0603
U1, U2, U3, U4, U5, U6, U7, U8, U9, U10, U11, U12, U13, U14, U15, U16, U17, U18, U19, U20, U21, U22, U23, U24, U25, U26, U27, U28, U29, U30, U31, U32, U33, U34, U35, U36: STHS34PF80; OLGA-10L
U$1, U$22, U$34, U$46, U$58, U$70, U$82, U$94, U$106, U$118, U$130, U$142, U$154, U$166, U$178, U$190, U$202, U$214, U$226, U$238, U$250, U$262, U$274, U$286, U$298, U$310, U$322, U$334, U$346, U$358, U$370, U$382, U$394, U$406, U$418, U$430: #3V3#36
U$2, U$23, U$35, U$47, U$59, U$71, U$83, U$95, U$107, U$119, U$131, U$143, U$155, U$167, U$179, U$191, U$203, U$215, U$227, U$239, U$251, U$263, U$275, U$287, U$299, U$311, U$323, U$335, U$347, U$359, U$371, U$383, U$395, U$407, U$419, U$431: ##CS#36
U$3, U$6, U$25, U$37, U$49, U$61, U$73, U$85, U$97, U$109, U$121, U$133, U$145, U$157, U$169, U$181, U$193, U$205, U$217, U$229, U$241, U$253, U$265, U$277, U$289, U$301, U$313, U$325, U$337, U$349, U$361, U$373, U$385, U$397, U$409, U$421: #SDA#5
U$4, U$14, U$26, U$38, U$50, U$62, U$74, U$86, U$98, U$110, U$122, U$134, U$146, U$158, U$170, U$182, U$194, U$206, U$218, U$230, U$242, U$254, U$266, U$278, U$290, U$302, U$314, U$326, U$338, U$350, U$362, U$374, U$386, U$398, U$410, U$422: #SCL#6
U$5, U$24, U$36, U$48, U$60, U$72, U$84, U$96, U$108, U$120, U$132, U$144, U$156, U$168, U$180, U$192, U$204, U$216, U$228, U$240, U$252, U$264, U$276, U$288, U$300, U$312, U$324, U$336, U$348, U$360, U$372, U$384, U$396, U$408, U$420, U$432: #INT#37
U$7, U$15, U$27, U$39, U$51, U$63, U$75, U$87, U$99, U$111, U$123, U$135, U$147, U$159, U$171, U$183, U$195, U$207, U$219, U$231, U$243, U$255, U$267, U$279, U$291, U$303, U$315, U$327, U$339, U$351, U$363, U$375, U$387, U$399, U$411, U$423: PWR9
U$8, U$16, U$28, U$40, U$52, U$64, U$76, U$88, U$100, U$112, U$124, U$136, U$148, U$160, U$172, U$184, U$196, U$208, U$220, U$232, U$244, U$256, U$268, U$280, U$292, U$304, U$316, U$328, U$340, U$352, U$364, U$376, U$388, U$400, U$412, U$424: #I2C#0
U$9, U$17, U$29, U$41, U$53, U$65, U$77, U$89, U$101, U$113, U$125, U$137, U$149, U$161, U$173, U$185, U$197, U$209, U$221, U$233, U$245, U$257, U$269, U$281, U$293, U$305, U$317, U$329, U$341, U$353, U$365, U$377, U$389, U$401, U$413, U$425: ##CS#6
U$10, U$18, U$30, U$42, U$54, U$66, U$78, U$90, U$102, U$114, U$126, U$138, U$150, U$162, U$174, U$186, U$198, U$210, U$222, U$234, U$246, U$258, U$270, U$282, U$294, U$306, U$318, U$330, U$342, U$354, U$366, U$378, U$390, U$402, U$414, U$426: #LED#8
U$11, U$19, U$31, U$43, U$55, U$67, U$79, U$91, U$103, U$115, U$127, U$139, U$151, U$163, U$175, U$187, U$199, U$211, U$223, U$235, U$247, U$259, U$271, U$283, U$295, U$307, U$319, U$331, U$343, U$355, U$367, U$379, U$391, U$403, U$415, U$427: ##INT#9
U$12, U$20, U$32, U$44, U$56, U$68, U$80, U$92, U$104, U$116, U$128, U$140, U$152, U$164, U$176, U$188, U$200, U$212, U$224, U$236, U$248, U$260, U$272, U$284, U$296, U$308, U$320, U$332, U$344, U$356, U$368, U$380, U$392, U$404, U$416, U$428: STH34PF80_PRESENCE_SENSOR10
U$13, U$21, U$33, U$45, U$57, U$69, U$81, U$93, U$105, U$117, U$129, U$141, U$153, U$165, U$177, U$189, U$201, U$213, U$225, U$237, U$249, U$261, U$273, U$285, U$297, U$309, U$321, U$333, U$345, U$357, U$369, U$381, U$393, U$405, U$417, U$429: #GND#35

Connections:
3.3V: C1.1, C2.1, J1.2, J2.2, J3.2, JP8.2, JP9.2, JP10.2, R3.2, U1.6, U1.9
3.3V1: C3.1, C4.1, J4.2, J5.2, J6.2, JP18.2, JP19.2, JP20.2, R10.2, U2.6, U2.9
3.3V2: C5.1, C6.1, J7.2, J8.2, J9.2, JP28.2, JP29.2, JP30.2, R15.2, U3.6, U3.9
3.3V3: C7.1, C8.1, J10.2, J11.2, J12.2, JP38.2, JP39.2, JP40.2, R20.2, U4.6, U4.9
3.3V4: C9.1, C10.1, J13.2, J14.2, J15.2, JP48.2, JP49.2, JP50.2, R25.2, U5.6, U5.9
3.3V5: C11.1, C12.1, J16.2, J17.2, J18.2, JP58.2, JP59.2, JP60.2, R30.2, U6.6, U6.9
3.3V6: C13.1, C14.1, J19.2, J20.2, J21.2, JP68.2, JP69.2, JP70.2, R35.2, U7.6, U7.9
3.3V7: C15.1, C16.1, J22.2, J23.2, J24.2, JP78.2, JP79.2, JP80.2, R40.2, U8.6, U8.9
3.3V8: C17.1, C18.1, J25.2, J26.2, J27.2, JP88.2, JP89.2, JP90.2, R45.2, U9.6, U9.9
3.3V9: C19.1, C20.1, J28.2, J29.2, J30.2, JP98.2, JP99.2, JP100.2, R50.2, U10.6, U10.9
3.3V10: C21.1, C22.1, J31.2, J32.2, J33.2, JP108.2, JP109.2, JP110.2, R55.2, U11.6, U11.9
3.3V11: C23.1, C24.1, J34.2, J35.2, J36.2, JP118.2, JP119.2, JP120.2, R60.2, U12.6, U12.9
3.3V12: C25.1, C26.1, J37.2, J38.2, J39.2, JP128.2, JP129.2, JP130.2, R65.2, U13.6, U13.9
3.3V13: C27.1, C28.1, J40.2, J41.2, J42.2, JP138.2, JP139.2, JP140.2, R70.2, U14.6, U14.9
3.3V14: C29.1, C30.1, J43.2, J44.2, J45.2, JP148.2, JP149.2, JP150.2, R75.2, U15.6, U15.9
3.3V15: C31.1, C32.1, J46.2, J47.2, J48.2, JP158.2, JP159.2, JP160.2, R80.2, U16.6, U16.9
3.3V16: C33.1, C34.1, J49.2, J50.2, J51.2, JP168.2, JP169.2, JP170.2, R85.2, U17.6, U17.9
3.3V17: C35.1, C36.1, J52.2, J53.2, J54.2, JP178.2, JP179.2, JP180.2, R90.2, U18.6, U18.9
3.3V18: C37.1, C38.1, J55.2, J56.2, J57.2, JP188.2, JP189.2, JP190.2, R95.2, U19.6, U19.9
3.3V19: C39.1, C40.1, J58.2, J59.2, J60.2, JP198.2, JP199.2, JP200.2, R100.2, U20.6, U20.9
3.3V20: C41.1, C42.1, J61.2, J62.2, J63.2, JP208.2, JP209.2, JP210.2, R105.2, U21.6, U21.9
3.3V21: C43.1, C44.1, J64.2, J65.2, J66.2, JP218.2, JP219.2, JP220.2, R110.2, U22.6, U22.9
3.3V22: C45.1, C46.1, J67.2, J68.2, J69.2, JP228.2, JP229.2, JP230.2, R115.2, U23.6, U23.9
3.3V23: C47.1, C48.1, J70.2, J71.2, J72.2, JP238.2, JP239.2, JP240.2, R120.2, U24.6, U24.9
3.3V24: C49.1, C50.1, J73.2, J74.2, J75.2, JP248.2, JP249.2, JP250.2, R125.2, U25.6, U25.9
3.3V25: C51.1, C52.1, J76.2, J77.2, J78.2, JP258.2, JP259.2, JP260.2, R130.2, U26.6, U26.9
3.3V26: C53.1, C54.1, J79.2, J80.2, J81.2, JP268.2, JP269.2, JP270.2, R135.2, U27.6, U27.9
3.3V27: C55.1, C56.1, J82.2, J83.2, J84.2, JP278.2, JP279.2, JP280.2, R140.2, U28.6, U28.9
3.3V28: C57.1, C58.1, J85.2, J86.2, J87.2, JP288.2, JP289.2, JP290.2, R145.2, U29.6, U29.9
3.3V29: C59.1, C60.1, J88.2, J89.2, J90.2, JP298.2, JP299.2, JP300.2, R150.2, U30.6, U30.9
3.3V30: C61.1, C62.1, J91.2, J92.2, J93.2, JP308.2, JP309.2, JP310.2, R155.2, U31.6, U31.9
3.3V31: C63.1, C64.1, J94.2, J95.2, J96.2, JP318.2, JP319.2, JP320.2, R160.2, U32.6, U32.9
3.3V32: C65.1, C66.1, J97.2, J98.2, J99.2, JP328.2, JP329.2, JP330.2, R165.2, U33.6, U33.9
3.3V33: C67.1, C68.1, J100.2, J101.2, J102.2, JP338.2, JP339.2, JP340.2, R170.2, U34.6, U34.9
3.3V34: C69.1, C70.1, J103.2, J104.2, J105.2, JP348.2, JP349.2, JP350.2, R175.2, U35.6, U35.9
3.3V35: C71.1, C72.1, J106.2, J107.2, J108.2, JP358.2, JP359.2, JP360.2, R180.2, U36.6, U36.9
!CS!: J3.5, R5.1, U1.3
!CS!1: J4.5, R9.1, U2.3
!CS!2: J7.5, R14.1, U3.3
!CS!3: J10.5, R19.1, U4.3
!CS!4: J13.5, R24.1, U5.3
!CS!5: J16.5, R29.1, U6.3
!CS!6: J19.5, R34.1, U7.3
!CS!7: J22.5, R39.1, U8.3
!CS!8: J25.5, R44.1, U9.3
!CS!9: J28.5, R49.1, U10.3
!CS!10: J31.5, R54.1, U11.3
!CS!11: J34.5, R59.1, U12.3
!CS!12: J37.5, R64.1, U13.3
!CS!13: J40.5, R69.1, U14.3
!CS!14: J43.5, R74.1, U15.3
!CS!15: J46.5, R79.1, U16.3
!CS!16: J49.5, R84.1, U17.3
!CS!17: J52.5, R89.1, U18.3
!CS!18: J55.5, R94.1, U19.3
!CS!19: J58.5, R99.1, U20.3
!CS!20: J61.5, R104.1, U21.3
!CS!21: J64.5, R109.1, U22.3
!CS!22: J67.5, R114.1, U23.3
!CS!23: J70.5, R119.1, U24.3
!CS!24: J73.5, R124.1, U25.3
!CS!25: J76.5, R129.1, U26.3
!CS!26: J79.5, R134.1, U27.3
!CS!27: J82.5, R139.1, U28.3
!CS!28: J85.5, R144.1, U29.3
!CS!29: J88.5, R149.1, U30.3
!CS!30: J91.5, R154.1, U31.3
!CS!31: J94.5, R159.1, U32.3
!CS!32: J97.5, R164.1, U33.3
!CS!33: J100.5, R169.1, U34.3
!CS!34: J103.5, R174.1, U35.3
!CS!35: J106.5, R179.1, U36.3
GND: C1.2, C2.2, J1.1, J2.1, J3.1, JP7.1, U1.2, U1.7, U1.8
GND1: C3.2, C4.2, J4.1, J5.1, J6.1, JP17.1, U2.2, U2.7, U2.8
GND2: C5.2, C6.2, J7.1, J8.1, J9.1, JP27.1, U3.2, U3.7, U3.8
GND3: C7.2, C8.2, J10.1, J11.1, J12.1, JP37.1, U4.2, U4.7, U4.8
GND4: C9.2, C10.2, J13.1, J14.1, J15.1, JP47.1, U5.2, U5.7, U5.8
GND5: C11.2, C12.2, J16.1, J17.1, J18.1, JP57.1, U6.2, U6.7, U6.8
GND6: C13.2, C14.2, J19.1, J20.1, J21.1, JP67.1, U7.2, U7.7, U7.8
GND7: C15.2, C16.2, J22.1, J23.1, J24.1, JP77.1, U8.2, U8.7, U8.8
GND8: C17.2, C18.2, J25.1, J26.1, J27.1, JP87.1, U9.2, U9.7, U9.8
GND9: C19.2, C20.2, J28.1, J29.1, J30.1, JP97.1, U10.2, U10.7, U10.8
GND10: C21.2, C22.2, J31.1, J32.1, J33.1, JP107.1, U11.2, U11.7, U11.8
GND11: C23.2, C24.2, J34.1, J35.1, J36.1, JP117.1, U12.2, U12.7, U12.8
GND12: C25.2, C26.2, J37.1, J38.1, J39.1, JP127.1, U13.2, U13.7, U13.8
GND13: C27.2, C28.2, J40.1, J41.1, J42.1, JP137.1, U14.2, U14.7, U14.8
GND14: C29.2, C30.2, J43.1, J44.1, J45.1, JP147.1, U15.2, U15.7, U15.8
GND15: C31.2, C32.2, J46.1, J47.1, J48.1, JP157.1, U16.2, U16.7, U16.8
GND16: C33.2, C34.2, J49.1, J50.1, J51.1, JP167.1, U17.2, U17.7, U17.8
GND17: C35.2, C36.2, J52.1, J53.1, J54.1, JP177.1, U18.2, U18.7, U18.8
GND18: C37.2, C38.2, J55.1, J56.1, J57.1, JP187.1, U19.2, U19.7, U19.8
GND19: C39.2, C40.2, J58.1, J59.1, J60.1, JP197.1, U20.2, U20.7, U20.8
GND20: C41.2, C42.2, J61.1, J62.1, J63.1, JP207.1, U21.2, U21.7, U21.8
GND21: C43.2, C44.2, J64.1, J65.1, J66.1, JP217.1, U22.2, U22.7, U22.8
GND22: C45.2, C46.2, J67.1, J68.1, J69.1, JP227.1, U23.2, U23.7, U23.8
GND23: C47.2, C48.2, J70.1, J71.1, J72.1, JP237.1, U24.2, U24.7, U24.8
GND24: C49.2, C50.2, J73.1, J74.1, J75.1, JP247.1, U25.2, U25.7, U25.8
GND25: C51.2, C52.2, J76.1, J77.1, J78.1, JP257.1, U26.2, U26.7, U26.8
GND26: C53.2, C54.2, J79.1, J80.1, J81.1, JP267.1, U27.2, U27.7, U27.8
GND27: C55.2, C56.2, J82.1, J83.1, J84.1, JP277.1, U28.2, U28.7, U28.8
GND28: C57.2, C58.2, J85.1, J86.1, J87.1, JP287.1, U29.2, U29.7, U29.8
GND29: C59.2, C60.2, J88.1, J89.1, J90.1, JP297.1, U30.2, U30.7, U30.8
GND30: C61.2, C62.2, J91.1, J92.1, J93.1, JP307.1, U31.2, U31.7, U31.8
GND31: C63.2, C64.2, J94.1, J95.1, J96.1, JP317.1, U32.2, U32.7, U32.8
GND32: C65.2, C66.2, J97.1, J98.1, J99.1, JP327.1, U33.2, U33.7, U33.8
GND33: C67.2, C68.2, J100.1, J101.1, J102.1, JP337.1, U34.2, U34.7, U34.8
GND34: C69.2, C70.2, J103.1, J104.1, J105.1, JP347.1, U35.2, U35.7, U35.8
GND35: C71.2, C72.2, J106.1, J107.1, J108.1, JP357.1, U36.2, U36.7, U36.8
INT: J3.6, R4.1, U1.10
INT1: J4.6, R8.1, U2.10
INT2: J7.6, R13.1, U3.10
INT3: J10.6, R18.1, U4.10
INT4: J13.6, R23.1, U5.10
INT5: J16.6, R28.1, U6.10
INT6: J19.6, R33.1, U7.10
INT7: J22.6, R38.1, U8.10
INT8: J25.6, R43.1, U9.10
INT9: J28.6, R48.1, U10.10
INT10: J31.6, R53.1, U11.10
INT11: J34.6, R58.1, U12.10
INT12: J37.6, R63.1, U13.10
INT13: J40.6, R68.1, U14.10
INT14: J43.6, R73.1, U15.10
INT15: J46.6, R78.1, U16.10
INT16: J49.6, R83.1, U17.10
INT17: J52.6, R88.1, U18.10
INT18: J55.6, R93.1, U19.10
INT19: J58.6, R98.1, U20.10
INT20: J61.6, R103.1, U21.10
INT21: J64.6, R108.1, U22.10
INT22: J67.6, R113.1, U23.10
INT23: J70.6, R118.1, U24.10
INT24: J73.6, R123.1, U25.10
INT25: J76.6, R128.1, U26.10
INT26: J79.6, R133.1, U27.10
INT27: J82.6, R138.1, U28.10
INT28: J85.6, R143.1, U29.10
INT29: J88.6, R148.1, U30.10
INT30: J91.6, R153.1, U31.10
INT31: J94.6, R158.1, U32.10
INT32: J97.6, R163.1, U33.10
INT33: J100.6, R168.1, U34.10
INT34: J103.6, R173.1, U35.10
INT35: J106.6, R178.1, U36.10
unnamed: D2.C, JP7.2
unnamed: JP8.3, R1.2
unnamed: JP8.1, R2.2
unnamed: D2.A, R3.1
unnamed: JP9.1, R4.2
unnamed: JP10.1, R5.2
unnamed: JP18.3, R6.2
unnamed: JP18.1, R7.2
unnamed: D1.A, R10.1
unnamed: JP19.1, R8.2
unnamed: D1.C, JP17.2
unnamed: JP20.1, R9.2
unnamed: JP28.3, R11.2
unnamed: JP28.1, R12.2
unnamed: D3.A, R15.1
unnamed: JP29.1, R13.2
unnamed: D3.C, JP27.2
unnamed: JP30.1, R14.2
unnamed: JP38.3, R16.2
unnamed: JP38.1, R17.2
unnamed: D4.A, R20.1
unnamed: JP39.1, R18.2
unnamed: D4.C, JP37.2
unnamed: JP40.1, R19.2
unnamed: JP48.3, R21.2
unnamed: JP48.1, R22.2
unnamed: D5.A, R25.1
unnamed: JP49.1, R23.2
unnamed: D5.C, JP47.2
unnamed: JP50.1, R24.2
unnamed: JP58.3, R26.2
unnamed: JP58.1, R27.2
unnamed: D6.A, R30.1
unnamed: JP59.1, R28.2
unnamed: D6.C, JP57.2
unnamed: JP60.1, R29.2
unnamed: JP68.3, R31.2
unnamed: JP68.1, R32.2
unnamed: D7.A, R35.1
unnamed: JP69.1, R33.2
unnamed: D7.C, JP67.2
unnamed: JP70.1, R34.2
unnamed: JP78.3, R36.2
unnamed: JP78.1, R37.2
unnamed: D8.A, R40.1
unnamed: JP79.1, R38.2
unnamed: D8.C, JP77.2
unnamed: JP80.1, R39.2
unnamed: JP88.3, R41.2
unnamed: JP88.1, R42.2
unnamed: D9.A, R45.1
unnamed: JP89.1, R43.2
unnamed: D9.C, JP87.2
unnamed: JP90.1, R44.2
unnamed: JP98.3, R46.2
unnamed: JP98.1, R47.2
unnamed: D10.A, R50.1
unnamed: JP99.1, R48.2
unnamed: D10.C, JP97.2
unnamed: JP100.1, R49.2
unnamed: JP108.3, R51.2
unnamed: JP108.1, R52.2
unnamed: D11.A, R55.1
unnamed: JP109.1, R53.2
unnamed: D11.C, JP107.2
unnamed: JP110.1, R54.2
unnamed: JP118.3, R56.2
unnamed: JP118.1, R57.2
unnamed: D12.A, R60.1
unnamed: JP119.1, R58.2
unnamed: D12.C, JP117.2
unnamed: JP120.1, R59.2
unnamed: JP128.3, R61.2
unnamed: JP128.1, R62.2
unnamed: D13.A, R65.1
unnamed: JP129.1, R63.2
unnamed: D13.C, JP127.2
unnamed: JP130.1, R64.2
unnamed: JP138.3, R66.2
unnamed: JP138.1, R67.2
unnamed: D14.A, R70.1
unnamed: JP139.1, R68.2
unnamed: D14.C, JP137.2
unnamed: JP140.1, R69.2
unnamed: JP148.3, R71.2
unnamed: JP148.1, R72.2
unnamed: D15.A, R75.1
unnamed: JP149.1, R73.2
unnamed: D15.C, JP147.2
unnamed: JP150.1, R74.2
unnamed: JP158.3, R76.2
unnamed: JP158.1, R77.2
unnamed: D16.A, R80.1
unnamed: JP159.1, R78.2
unnamed: D16.C, JP157.2
unnamed: JP160.1, R79.2
unnamed: JP168.3, R81.2
unnamed: JP168.1, R82.2
unnamed: D17.A, R85.1
unnamed: JP169.1, R83.2
unnamed: D17.C, JP167.2
unnamed: JP170.1, R84.2
unnamed: JP178.3, R86.2
unnamed: JP178.1, R87.2
unnamed: D18.A, R90.1
unnamed: JP179.1, R88.2
unnamed: D18.C, JP177.2
unnamed: JP180.1, R89.2
unnamed: JP188.3, R91.2
unnamed: JP188.1, R92.2
unnamed: D19.A, R95.1
unnamed: JP189.1, R93.2
unnamed: D19.C, JP187.2
unnamed: JP190.1, R94.2
unnamed: JP198.3, R96.2
unnamed: JP198.1, R97.2
unnamed: D20.A, R100.1
unnamed: JP199.1, R98.2
unnamed: D20.C, JP197.2
unnamed: JP200.1, R99.2
unnamed: JP208.3, R101.2
unnamed: JP208.1, R102.2
unnamed: D21.A, R105.1
unnamed: JP209.1, R103.2
unnamed: D21.C, JP207.2
unnamed: JP210.1, R104.2
unnamed: JP218.3, R106.2
unnamed: JP218.1, R107.2
unnamed: D22.A, R110.1
unnamed: JP219.1, R108.2
unnamed: D22.C, JP217.2
unnamed: JP220.1, R109.2
unnamed: JP228.3, R111.2
unnamed: JP228.1, R112.2
unnamed: D23.A, R115.1
unnamed: JP229.1, R113.2
unnamed: D23.C, JP227.2
unnamed: JP230.1, R114.2
unnamed: JP238.3, R116.2
unnamed: JP238.1, R117.2
unnamed: D24.A, R120.1
unnamed: JP239.1, R118.2
unnamed: D24.C, JP237.2
unnamed: JP240.1, R119.2
unnamed: JP248.3, R121.2
unnamed: JP248.1, R122.2
unnamed: D25.A, R125.1
unnamed: JP249.1, R123.2
unnamed: D25.C, JP247.2
unnamed: JP250.1, R124.2
unnamed: JP258.3, R126.2
unnamed: JP258.1, R127.2
unnamed: D26.A, R130.1
unnamed: JP259.1, R128.2
unnamed: D26.C, JP257.2
unnamed: JP260.1, R129.2
unnamed: JP268.3, R131.2
unnamed: JP268.1, R132.2
unnamed: D27.A, R135.1
unnamed: JP269.1, R133.2
unnamed: D27.C, JP267.2
unnamed: JP270.1, R134.2
unnamed: JP278.3, R136.2
unnamed: JP278.1, R137.2
unnamed: D28.A, R140.1
unnamed: JP279.1, R138.2
unnamed: D28.C, JP277.2
unnamed: JP280.1, R139.2
unnamed: JP288.3, R141.2
unnamed: JP288.1, R142.2
unnamed: D29.A, R145.1
unnamed: JP289.1, R143.2
unnamed: D29.C, JP287.2
unnamed: JP290.1, R144.2
unnamed: JP298.3, R146.2
unnamed: JP298.1, R147.2
unnamed: D30.A, R150.1
unnamed: JP299.1, R148.2
unnamed: D30.C, JP297.2
unnamed: JP300.1, R149.2
unnamed: JP308.3, R151.2
unnamed: JP308.1, R152.2
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

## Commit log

2023-08-04 Folder restructure and addition of datasheet(s)
    Removed the folders from the SFE repo template that were unneeded and added the datasheet, application note, and part layout guidelines for the sensor to the documentation folder.
2023-08-07 Addition of STHS34PF80 part, schematic, and board file
    Created the new part in Eagle Library and added to project. Created schematic and board files, worked on rough drafts of each.
    [SparkFun Infrared Sensor STH34PF80.brd, SparkFun Infrared Sensor STH34PF80.sch]
2023-08-09 Continued design
    Adjusted symbol and footprint to reflect the I2C AND SPI interfaces. Uploading to change name in GitHub for official product name
    [SparkFun Infrared Sensor STH34PF80.brd, SparkFun Infrared Sensor STH34PF80.sch]
2023-08-15 Updates to Mini - uploading to change repo name
    Continued mini board design
    [SparkFun Infrared Sensor STH34PF80.brd, SparkFun Infrared Sensor STH34PF80.sch, SparkFun Infrared Sensor STHS34PF80 Mini.brd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]
2023-08-15 Removed unneeded files; finished design rule errors
    Removed the regular Qwiic files and redid the structure of the file folder. Renamed the appropriate files as well. Finished the design rule errors and routing, along with the silk screen. Should be ready for order soon.
    [SparkFun Infrared Sensor STH34PF80.brd, SparkFun Infrared Sensor STH34PF80.sch, SparkFun Qwiic Mini Human Presence Sensor - STHS34PF80.brd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]
2023-08-16 Move mini files into sub folder.
    [SparkFun Qwiic Mini Human Presence Sensor - STHS34PF80.brd, SparkFun Qwiic Mini Human Presence Sensor - STHS34PF80.sch]
2023-08-16 Add 1U files.
    [SparkFun_Qwiic_Presence_STHS34PF80-Panel.GBL, SparkFun_Qwiic_Presence_STHS34PF80-Panel.GBP, SparkFun_Qwiic_Presence_STHS34PF80-Panel.GBS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]
2023-08-17 Layout Updates
    Finished updates to layout - almost ready for design review
    [SparkFun Qwiic Mini Human Presence Sensor - STHS34PF80.brd]
2023-08-18 Updated design for review and added production files for Mini
    MINI ONLY: Completed layout and worked through design errors, panelized the board, and then created Gerbers for production. Added more comments throughout layout and schematic.
    [SparkFun Qwiic Mini Human Presence Sensor - STHS34PF80-Panel.brd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]
2023-08-18 Updated version number on schematic
    Board is now ready for review
    [SparkFun Qwiic Mini Human Presence Sensor - STHS34PF80.brd, SparkFun Qwiic Mini Human Presence Sensor - STHS34PF80.sch]
2023-08-21 Updated files for design review
    Changed ST part to have 80% solder cream; changed panels to be 6x6 boards; changed vector font issues in schematic; added measures; added some more silk for easier part identification
    [SparkFun Qwiic Mini Human Presence Sensor - STHS34PF80-Panel.brd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]
2023-08-21 Changed from Qwiic horizontal to qwiic vertical
    Changed to the Qwiic Vertical connector we have for a better surface mounting option for the user. Updated the gerbers and panel to now have the correct information
    [SparkFun Qwiic Mini Human Presence Sensor - STHS34PF80-Panel.brd, SparkFun Qwiic Mini Human Presence Sensor - STHS34PF80.brd, SparkFun Qwiic Mini Human Presenc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]
2023-08-22 Small documentation additions
    Added I2C address to schematic and units for measures (measures in inches)
    [SparkFun Qwiic Mini Human Presence Sensor - STHS34PF80.brd, SparkFun Qwiic Mini Human Presence Sensor - STHS34PF80.sch]
2023-09-06 Updated 1U to correct paste layer for main IC
    Updated the board and the panel/gerbers to have the correct percentage of fill for the solder paste on the STHS34PF80
    [SparkFun_Qwiic_Presence_STHS34PF80-Panel.brd, SparkFun_Qwiic_Presence_STHS34PF80.brd, SparkFun_Qwiic_Presence_STHS34PF80.sch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]
2023-09-20 Update to Mini board
    Changed silkscreen on the back to have the correct part number on it
    [SparkFun Qwiic Mini Human Presence Sensor - STHS34PF80.brd]
2024-07-16 Fix typo
    Remove carriage return
2024-07-16 Fix CS jumper info
    Misinterpreted schematic. The CS jumper doesn't need to be cut to enable SPI; pin just needs to be pulled low.

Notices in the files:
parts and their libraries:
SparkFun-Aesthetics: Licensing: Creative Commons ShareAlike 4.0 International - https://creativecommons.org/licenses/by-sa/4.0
